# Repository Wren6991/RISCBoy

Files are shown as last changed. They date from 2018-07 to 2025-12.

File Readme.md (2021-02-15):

RISCBoy
=======

RISCBoy is an open-source portable games console, designed from scratch. This includes:

- A RISC-V compatible CPU
- A raster graphics pipeline and display controller
- Other chip infrastructure: busfabric, memory controllers, UART, GPIO etc.
- A PCB layout in KiCad

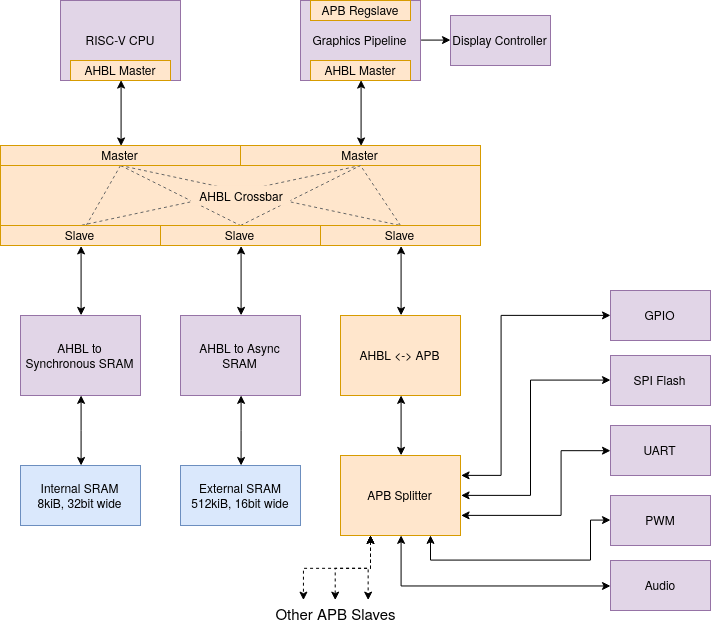
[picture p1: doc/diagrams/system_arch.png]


It is a Gameboy Advance from a parallel universe where RISC-V existed in 2001. A love letter to the handheld consoles from my childhood, and a 3AM drunk text to the technology that powered them.

The design is written in synthesisable Verilog 2005, and is intended to fit onto an iCE40-HX8k FPGA. This is a LUT4-based FPGA with 7680 logic elements, so fitting a 32 bit games console requires a crowbar and some vaseline, or perhaps just careful design. The HX8k was once the largest FPGA targeted by the open-source [Icestorm](http://www.clifford.at/icestorm/) FPGA toolchain, but that toolchain has since [moved on](https://github.com/SymbiFlow/prjtrellis) to [greater things](https://github.com/SymbiFlow/prjxray).

More detailed information can be found in the [documentation](doc/riscboy_doc.pdf).

The processor supports the RV32IMC instruction set, and passes the RISC-V compliance suite for these instructions, as well as the [riscv-formal](https://github.com/SymbioticEDA/riscv-formal) verification suite, and some of my own formal property checks for instruction frontend consistency and basic bus compliance. It also supports M-mode CSRs, exceptions, and a simple compliant extension for vectored external interrupts.

Cloning
-------

**This repository uses submodules for HDL as well as tests**

```bash
git clone --recursive https://github.com/Wren6991/RISCBoy.git riscboy
```

Alternatively

```bash
git clone https://github.com/Wren6991/RISCBoy.git riscboy
cd riscboy
git submodule update --init --recursive
```

Note a recursive submodule update is required to run the processor's standalone tests. This is not necessary for building RISCBoy gateware.

Building RV32IMC Toolchain
-------------------------

The RV32IMC toolchain is required for compilation of software-based tests. Follow the instructions on the [RISC-V GNU Toolchain GitHub](https://github.com/riscv/riscv-gnu-toolchain), except for the configure line:

```bash
# Prerequisites for Ubuntu 20.04
sudo apt install -y autoconf automake autotools-dev curl python3 libmpc-dev libmpfr-dev libgmp-dev gawk build-essential bison flex texinfo gperf libtool patchutils bc zlib1g-dev libexpat-dev
cd /tmp
git clone --recursive https://github.com/riscv/riscv-gnu-toolchain
cd riscv-gnu-toolchain
# The ./configure arguments are the most important difference
./configure --prefix=/opt/riscv --with-arch=rv32imc --with-abi=ilp32 --with-multilib-generator="rv32i-ilp32--;rv32ic-ilp32--;rv32im-ilp32--;rv32imc-ilp32--"
sudo mkdir /opt/riscv
sudo chown $(whoami) /opt/riscv
make -j $(nproc)
```

On smaller FPGAs, like the iCE40 UP5k, RISCBoy may be configured to use a smaller RV32I variant of the processor, rather than the higher-performance RV32IMC version. The compiler will support any of the ISA variants available on RISCBoy, but we must also instruct the toolchain build scripts to produce standard libraries for these variants, via the `--with-multilib` arguments. Running a RV32I executable linked against an RV32IMC standard library on an RV32I-only processor will ruin your day!

Simulation
----------

The simulation flow is driven by Xilinx ISIM 14.x; makefiles are found in the scripts/ folder. This has only been tested with the Linux version of ISIM.

You will also need to checkout the RISC-V compliance suite in order to run these tests (note the `-- test` is required to stop git from looking in the KiCad directories and complaining about the library structure there).

```
$ git submodule update --init --recursive
```

Once this is ready, you should be able to run the following:

```bash
. sourceme
cd test
./runtests
```

which will run all of the HDL-level tests. Software tests will require the RV32IC toolchain. You may need to adjust some of the paths in `sourceme` if ISIM is installed in a non-default location. To graphically debug a test, run its makefile directly:

```bash
cd system
make TEST=helloworld gui
```

PCB
---

The image shows the Rev A PCB. It is compatible with iTead's 4-layer 5x5 cm prototyping service, which currently costs $65 for 10 boards.

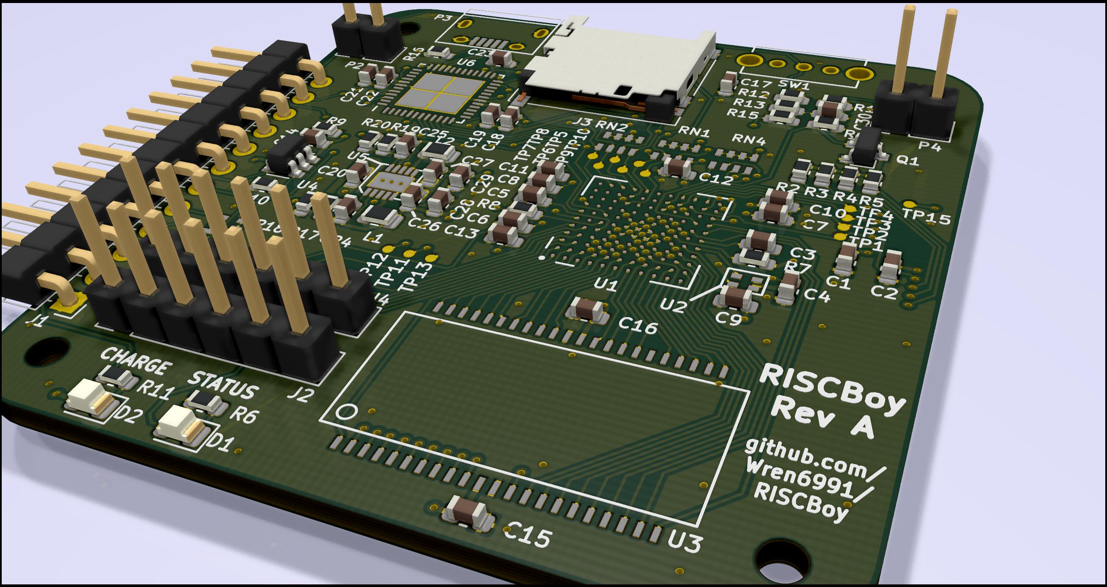
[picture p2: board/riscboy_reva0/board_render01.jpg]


The schematic can be viewed [here (pdf)](board/fpgaboy.pdf)

Rev B will look quite different; I am waiting for the gateware and bootloader to mature before proceeding. My current dev hardware looks a lot like my [Snowflake FPGA board](https://github.com/Wren6991/Snowflake-FPGA).

Synthesis
---------

FPGA synthesis for iCE40 uses an open-source toolchain. If you would like to build this project using the existing makefiles, you will first need to build the toolchain I used:

- [Yosys](https://github.com/yosyshq/yosys) for synthesis
- [nextpnr](https://github.com/YosysHQ/nextpnr) for place and route
- [Project Icestorm](http://www.clifford.at/icestorm/) for bitstream generation

Note that I have only built these on Linux. I've heard it is possible to build these on Windows, but haven't tried it. However, they can be built on a Raspberry Pi, which is neat.

Once the toolchain is in place, run

```bash
. sourceme
cd synth
make -f HX8k-EVN.mk bit
```

to generate an FPGA image suitable for Lattice HX8k evaluation board.

There is also highly experimental support (i.e. not my main dev platform) for ECP5, with board files for the Lattice LEF5UM5G-85F-EVN evaluation board:

```bash
make -f ECP5-EVN.mk BUILD=full bit
```

This build replaces the external, 512 kiB, 16 bit wide SRAM of RISCBoy development hardware with an internal, 256 kiB, 32 bit wide synchronous memory, which Trellis builds out of ECP5 sysmem blocks.

Directory Structure
-------------------

- `board`: KiCad files for main RISCBoy PCB and other small boards used during development
- `doc`: LaTeX source and diagrams for documentation, and the most recently built PDF
- `hdl`: The Verilog source for RISCBoy gateware.
	- `busfabric`: AHB-lite crossbar and APB peripheral fabric
	- `graphics`: Source for the pixel processing unit
	- `hazard5`: Source for the RISC-V processor. This is completely self-contained.
	- `mem`: Memory controllers, and inference/injection wrappers and models for the memories themselves
	- `peris`: Small peripherals such as UART, SPI, PWM
	- `riscboy_core`: Structural module to instantiate and connect the components that comprise RISCBoy
	- `riscboy_fpga`: Top-level wrappers for a few different FPGAs and boards: connect up IOs, provide clock and reset
- `reference`: a few PDFs for standards used in RISCBoy, e.g. the RISC-V instruction set
- `scripts`: Junk that I can't put anywhere else
- `software`: Loose collection of C files that are used for system-level tests. Not really a useful software tree yet.
- `synth`: Working directory for running whole-system synthesis. Top-level makefiles, pin constraint files.
- `test`: Regression tests. Some are Verilog testbenches, others are software testcases that run on simulations of the processor or the full system.

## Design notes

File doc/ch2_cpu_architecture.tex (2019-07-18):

\section{CPU Architecture}

Hazard5 is a 32-bit processor based on the RISC-V instruction set architecture. It accesses the system through a single AMBA 3 AHB-Lite master port. Those familiar with the textbook 5-stage RISC pipeline will find Hazard5 mostly straightforward, but hopefully will still find some interesting tricks. We will use the following symbols to refer to the 5 stages:

\begin{itemize}
\item {\tt F}: fetch
\item {\tt D}: decode
\item {\tt X}: execute
\item {\tt M}: memory access (load/store)
\item {\tt W}: register writeback, fetch address generation
\end{itemize}

Hazard5 supports the RV32IC instruction set, whose encoding is variable-width. The C extension typically reduces instruction bandwidth by \textasciitilde 25\%, which helps to maintain performance when sharing bus access between fetch and load/store.

Branches are speculated, but there is currently no dynamic branch predictor. Instead, we use the static prediction scheme described in the RV ISA manual (based on sign of branch offset).

\subsection{Frontend}
\label{section:frontend}

\begin{figure}[!htb]
\centering
\caption{Hazard5 processor frontend, block diagram}

\label{diagram:frontend}
\end{figure}

The frontend (figure \ref{diagram:frontend}) consists of stage {\tt F} and an additional stage which performs the AHB address phase, and can be considered part of {\tt W}. Its purpose is to feed {\tt D} with instructions, whilst meeting the following constraints:

\begin{itemize}
	\item No combinatorial path from AHB-Lite data phase to address phase (e.g. {\tt hready} $\to$ {\tt htrans})
	\item AHB-Lite compliant: no unaligned transfers, no deassertion or change of active requests
	\item Provide up to 32 bits of instruction data per clock in steady state, even if instructions are unaligned
	\item 0-cycle jump/flush to AHB address phase assertion (with minimal logic on this path)
	\item No performance penalty for unaligned jump to 16-bit instruction
	\item Attempt to maintain performance when competing with the load/store unit and AHB-Lite busmaster peers
\end{itemize}

The main source of complexity is that a RISC-V *C instruction stream is not naturally-aligned, i.e. instruction address modulo instruction size is not always zero. We spend gates here to optimise the common case of sequential execution, and to lessen the effects of fetch starvation due to load-store activity.

To meet these constraints, the frontend performs almost exclusively word accesses, which must be aligned. The only exception is a jump (or similar, e.g. mispredict recovery) to a non-word-aligned address. In this case, a halfword fetch from the target address is performed.

\subsubsection{Prefetch Queue}

The frontend queues up fresh instruction data which is waiting to be decoded. The pipelined nature of AHB-Lite means that the bus transfers run ahead of {\tt D} by at least two clocks, and the prefetch queue is able to buffer these in-flight transfers if {\tt D} stalls against a later pipe stage. The queue also decouples {\tt D}'s stall logic (which is a function of {\tt hready}) from the address phase request, and finally, the queue helps keep {\tt D} supplied with instructions while the busmaster is busy with load/stores from {\tt X}.

There are three parts to the queue:

\begin{itemize}
	\item A 32-bit FIFO. The depth is configurable, and can be as little as 1 word.
	\item A halfword buffer which may store the higher-addressed half of a recently-popped FIFO word
	\item The upper half of the current instruction register ({\tt CIR}), if the previous instruction was 16-bit
\end{itemize}

These three sources should service the majority of instruction fetches, and fresh bus data is written only to the FIFO. However, following jumps, flushes, or fetch starvation (either due to load/store activity or bus wait states), bus data can be forwarded directly to {\tt CIR}.

\subsubsection{Program Counter}

Hazard5 does {\it not} use the program counter ({\tt PC}) for code fetching, during sequential execution. {\tt PC} is used exclusively for the link value in {\tt JAL(R)}, mispredict recovery, and PC-relative addressing; it is physically located in {\tt D}.

The frontend fetches instruction data from consecutive word-aligned addresses, paced by backpressure from the instruction FIFO; {\tt PC} is not involved. However, as a special case, it {\it does} need the full jump target address (which becomes the new {\tt PC}), as unaligned jumps require special attention.

\subsubsection{Arbitration of Fetch and Load/Store}
\label{section:fetch_ls_arb}

The single AHB master port asserts transactions from two sources: the frontend, whose address phase is in {\tt W}, and the load/store unit, whose address phase is in {\tt X}. Frontend requests may be linear or non-linear (e.g jumps). The rules are:

\begin{enumerate}
	\item If a jump or mispredict recovery is asserted by {\tt M}, this wins.
	\begin{itemize}
		\item Any requests from earlier stages are logically later in program order.
		\item If {\tt M} wants to jump then these instructions are being executed in error, so should certainly not be permitted to access the bus.
	\end{itemize}
	\item Else if a load/store is asserted by {\tt X}, this wins.
	\begin{itemize}
		\item Stalling instruction fetch {\it may} be covered by the prefetch queue, in which case we've lost nothing
		\item Stalling a load/store will always increase execution time
		\item If instead {\tt X} stalled, and instruction fetch ran ahead, what would we do with the fetched instructions?
	\end{itemize}
	\item Otherwise, perform any other access requested by the frontend.
	\begin{itemize}
		\item Always Be Fetching
	\end{itemize}
\end{enumerate}

The fetch and load/store interfaces are well-decoupled; it would be simple to remove the arbiter and create a 2-master processor configuration. (TODO: add a wrapper that does this!)

\subsubsection{Jumps and Branches}

Due to the pipelined nature of AHB, we are unable to jump or to take branches in fewer than 2 cycles (without adding sophisticated prediction):

\begin{itemize}
\item Cycle 0: AHB data phase for fetch of jump/branch. Next instruction is in address phase concurrently.
\item Cycle 1: Jump/branch instruction is now available to {\tt D}
	\begin{itemize}
		\item (Quickly) use to control the new address phase
		\item The immediately following instruction is already in data phase
	\end{itemize}
\item Cycle 2: Data phase for jump target instruction
\item Cycle 3: Jump target is presented to {\tt D} and decoded.
\end{itemize}

We knew the jump target on cycle 1, but did not begin decoding the targeted instruction until cycle 3. We also made one wasted code fetch. This is suboptimal, but fetching the jump target {\it before} decoding the jump is tricky, and there are lower-hanging fruit in terms of performance per LUT.

Jumps physically occur in {\tt W}, directly in front of the fetch address generator. There are two reasons to jump:

\begin{itemize}
	\item Inspecting the {\tt CIR} in {\tt F/D} pipe register ({\tt JAL}, speculated taken branches)
	\item Inspecting {\tt X/M} pipe register ({\tt JALR}, branch mispredict recovery)
\end{itemize}

{\tt JALR} (indirect jump) is taken later because it uses the register file and the ALU to compute its target.

If both of these sources attempt to jump in the same cycle, {\tt X/M} takes priority, since it is executing an older instruction. In both cases, the part of the pipeline in the hazard shadow is invalidated; i.e., {\tt W} $\to$ {\tt F}, or {\tt W} $\to$ {\tt X}. Invalidation is performed by clobbering the pipeline control signals in such a way that these instructions will have no side effects.

The branch prediction scheme is static: take backward branches, and do not take forward branches. The cycle costs are as follows:

\begin{center}
\begin{tabular}{l c}
\hline
Jump Type & Cycles (Execution + Penalty) \\
\hline
Direct jump & 2 \\
Predicted, non-taken branch & 1 \\
Predicted, taken branch (same as jump) & 2 \\
Indirect jump & 4 \\
Branch mispredict & 4 \\
\hline
\end{tabular}
\end{center}

Upon jumping, we need some mechanism to invalidate parts of the pipeline: this is described in section \ref{section:stalling_flushing}.

\subsubsection{CIR Locking}

There is a landmine in the following tableau:

\begin{itemize}
	\item {\tt M} contains a load (in data phase), and the bus is stalled
	\item {\tt X} contains an instruction dependent on the load result; say an {\tt AND}
	\item {\tt D} contains a branch which is mispredicted taken
\end{itemize}

For example, say we are polling a status bit in an IO register, looping until some bit is high. The instruction in {\tt X} must stall for at least two cycles due to the bus stall and load-use hazard. Due to a frontend design constraint from \ref{section:frontend} -- "No combinatorial path from AHB-Lite data phase to address phase (e.g. {\tt hready} $\to$ {\tt htrans})" -- we must not use {\tt X}'s stall signal to gate the jump request, as this would create such a path. However, {\it not} gating the jump request is fatal, as new fetches will clobber {\tt CIR} before the branch instruction can proceed into {\tt X}, so the mispredict will never recover. {\tt JAL} has the same problem: it will jump, but not produce a link address.

Hazard5 resolves this with {\tt CIR} locking. {\tt D} signals to {\tt F} that {\tt CIR} and its validity count must not change on the next clock edge, and uses this same signal to inhibit repeated assertion of its own jump request. In the fetch path, this is achieved by steering the controls on the existing shift/overlay logic in the frontend, and requires no additional muxing.

Whilst the {\tt CIR} is locked, the frontend is still free to act on the jump request, and fetch ahead along the new code path (more useful for {\tt JAL}); this data is buffered in the FIFO. Once the roadblock ahead of {\tt D} clears, the branch instruction proceeds down the pipeline, and the lock is released simultaneously.

Note also that a bus stall does not cause the frontend to block jump requests, as this too would create a combinatorial path, since requests are forwarded straight to the bus (due to another constraint from \ref{section:frontend}). The frontend's response to bus stall on jump request is simply to not increment the target before storing to {\tt FC}, so that the target address continues to be asserted on subsequent cycles. Registered feedback blocks {\it subsequent} jump requests until the first request completes its address phase.

\subsubsection{Instruction Barrier (FENCE.I)}

If the program stores to instruction addresses about to be executed from, which potentially exist in the prefetch queue, a stale instruction will be executed. {\tt FENCE.I} cannot be decoded as a nop, and requires special handling.

Hazard5 decodes {\tt FENCE.I} as "jump to {\tt PC} + 4". The jump invalidates the prefetch queue, and the following instruction will be re-fetched from memory.

Timing analysis shows that calculating a jump target, between {\tt CIR} and the address bus, is generally on the critical path. To avoid more logic on this path, {\tt FENCE.I} is instead implemented by spoofing a branch-taken mispredict, which has the same effect. This adds two cycles to the execution time, but performance of this instruction is decidedly noncritical.

\subsection{Backend}

The backend is the hardware which manipulates the processor's architectural state according to the stream of instruction data from the frontend. Architectural state refers to the state you will read about in the ISA manual, and includes the register file and program counter; the backend also contains some non-architectural state, e.g. holding intermediate results in between pipeline stages.

The backend consists of stages {\tt D}, {\tt X}, {\tt M}. Its overall structure is depicted by figure \ref{diagram:cpu_backend}. This is a pretty large figure -- too large to print really -- so you can view it separately at \url{https://github.com/Wren6991/RISCBoy/raw/master/doc/diagrams/cpu_backend.pdf}

\newpage

\begin{center}
	\begin{sideways}
		\begin{minipage}{\textheight}
			
			\captionof{figure}{Hazard5 processor backend, block diagram}
			\label{diagram:cpu_backend}
		\end{minipage}
	\end{sideways}
\end{center}

\newpage

\subsubsection{Operand Bypass}

Hazard5 possesses an operand bypass (forwarding) network. Register writes must always be visible to later instructions, even before an earlier instruction reaches register writeback. One solution is to detect that one instruction depends on the result of an earlier instruction (a read-after-write, or RAW hazard) and stall the later instruction until the earlier one completes. This is safe, but incurs a hefty performance penalty; a more elegant solution is to pluck the result of the earlier instruction straight from the pipeline, before it finishes executing (but after the result is valid!).

Locations of bypasses are shown in figure \ref{diagram:cpu_backend}. The following bypasses are available:

\begin{itemize}
	\item {\tt X/M} $\to$ {\tt X}
	\item {\tt M/W} $\to$ {\tt X}
	\item {\tt M/W} $\to$ {\tt M}
	\item {\tt W/X} $\to$ {\tt X}
\end{itemize}

The last is in lieu of a write-to-read bypass in the register file; some tools (not Yosys!) struggle with inferring memories from transparent memory models, so it's better to be explicit.

To control the bypassing, some of the register specifiers from {\tt CIR} are passed down the pipeline alongside the data. {\tt rs1, rs2, rd} (operand sources and destination) are passed down as far as {\tt X}. {\tt rs2, rd} make it to {\tt M}, and only {\tt rd} makes it to {\tt W}.

The upshot is:

\begin{itemize}
	\item Back-to-back ALU operations execute at 1 CPI
	\item Loads insert 1 stall cycle if immediately required by the ALU. 1 CPI otherwise.
	\item Stores execute at 1 CPI (bus stall notwithstanding)
	\item In a load + store pair, the load takes only one cycle, since the {\tt M} stage has self-forwarding
\end{itemize}

Various interesting strategies can alleviate load-use penalty in in-order pipelines, such as adding a second, "late" ALU in the {\tt M} stage. In our case we judge this to not be worth the LUTs.

Another interesting strategy is to add muxing at the register file write port, to select which stage to retire from. This has the dual benefit of firstly simplifying the operand bypass, and secondly reducing dynamic power, since there is no need to pass data through unused stages (and they can be clock gated). Hazard5 does not use this strategy either -- maybe the next project.

\subsubsection{Pipeline Stalling and Flushing}
\label{section:stalling_flushing}

Our terminology: stalling means a pipeline stage does not advance its state until some blocking condition has cleared. The instruction residing in this stage will not progress to the next stage, and the previous stage will not write {\it its} instruction into this stage. Flushing is when in-flight instructions in some stages are replaced with NOPs, and their results are discarded.

The frontend is decoupled from other stages' stall logic via the prefetch queue. This is important: {\tt hready} is an input to that stall logic, and the the frontend's address-phase request must not be a function of {\tt hready}.

The frontend may not be able to immediately accept a jump request, which may cause other pipe stages to stall if it is low. One cause is the frontend holding an existing address-phase request stable until the cycle {\it after} {\tt hready}, which is required for AHB-Lite compliance.

For the backend, the stall logic is more intricate, as signals such as {\tt hready} are used in-cycle to determine whether an instruction progresses to the next pipeline stage:

\begin{itemize}
	\item {\tt D}:
	\begin{itemize}
		\item {\tt CIR} does not contain a valid instruction (either no data, or half of a 32-bit instruction)
		\item {\tt D} asserts jump, but frontend rejects the jump request
		\item {\tt X} is stalled
	\end{itemize}
	\item {\tt X}:
	\begin{itemize}
		\item {\tt hready} low and {\tt X} address-phase request asserted
		\item RAW hazard on {\tt M} (load-use)
		\item {\tt M} is stalled
	\end{itemize}
	\item {\tt M}:
	\begin{itemize}
		\item {\tt hready} low and data-phase active
		\item {\tt M} asserts jump, but frontend rejects the jump request
	\end{itemize}
	\item {\tt W}: does not stall
\end{itemize}

If a given stage is stalled, but the following stage is not, it must insert a bubble. Bubbles are created by zeroing out control fields, such as {\tt rd}, so that the instruction cannot affect system or processor state.

There are two cases where we must flush:

\begin{itemize}
	\item Branch/jump taken from {\tt D}; frontend invalidates prefetched data
	\item Jump/mispredict taken from {\tt M}; must flush frontend, {\tt D}, {\tt X}
\end{itemize}

And the flushing mechanisms for each stage are as follows:
\begin{itemize}
	\item {\tt D}: destination register {\tt rd} cleared, which makes result invisible to register file and operand bypass. {\tt memop}, {\tt branchcond} pipe flags are cleared.
	\item {\tt X}: same as {\tt D} (except for {\tt branchcond}, which does not pass on to {\tt M} anyway.
\end{itemize}

Flushing and bubble insertion are very similar in mechanism.

\subsection{Unaligned Memory Accesses}

Alignment is the constraint that the address of a memory access be equal to zero, modulo some size. Where no size is specified, we refer to {\it natural} alignment, i.e. modulo the size of this particular memory operation. RISC-V requires that memory is byte-addressable.

The frontend goes to some length (section \ref{section:frontend}) to maintain high throughput. RV-C instruction streams are {\it always} unaligned, and {\it every} instruction must be fetched before it is executed, so Amdahl says it's worth it. On the other hand load/stores are less than 100\% of all instructions, and the vast majority are unaligned; consequently, Hazard5 does not have hardware support for unaligned load/stores. These are trapped (TODO) and handled in software if and when they occur.

\subsection{Control and Status Registers (CSRs)}

Hazard5 possesses the standard {\tt Zicsr} extension, which provides atomic access to the CSRs. Only M-mode CSRs are implemented. Access to an unimplemented CSR (e.g. a U-mode or S-mode CSR) causes an illegal instruction exception. The implementation is minimally legal: WARL fields are widely exploited, to reduce logic and state overhead. Module parameters can reduce CSR support, or remove it entirely, as per relative importance of compliance versus area in your application. Note that some features, such as interrupts and exceptions, require CSR support.

When the counter CSRs are present, {\tt mtime} and {\tt mcycle} are aliased to the same counter. 64-bit counters are prohibitively large in a compact 32-bit processor. The {\tt mcountinhibit} (WARL) register is tied to zero: {\tt mtime} must run freely, hence the {\tt mcycle} alias of this counter cannot be halted either. {\tt minstret} is fully implemented, but its {\tt mcountinhibit} bit is also tied low. The width of the counters can be reduced from 64 bits to save logic ({\it noncompliant}), although the full 64 CSR bits remain writeable, which leaves some opportunity for software emulation.

TODO: full table of CSRs we implement, and to what extent they are implemented/WARL'd

\subsection{Interrupts and Exceptions}

\begin{figure}[!htb]
\centering
\caption{Hazard5 trap vector table layout}
\label{table:traps}
\begin{tabular}{l l l}
\hline
Trap Table Offset & {\tt mcause} & Trap Description \\
\hline
0x00 & 0x00000000 & Misaligned instruction access \\
0x04 & 0x00000001 & Instruction access fault \\
0x08 & 0x00000002 & Illegal instruction \\
0x0c & 0x00000003 & Breakpoint \\
0x10 & 0x00000004 & Misaligned load address \\
0x14 & 0x00000005 & Load access fault \\
0x18 & 0x00000006 & Misaligned store address \\
0x1c & 0x00000007 & Store access fault \\
0x20 & 0x00000008 & {\it Reserved} \\
0x24 & 0x00000009 & {\it Reserved} \\
0x28 & 0x0000000a & {\it Reserved} \\
0x2c & 0x0000000b & M-mode ECALL \\
0x30 & 0x0000000c & {\it Reserved} \\
... & ... & ... \\
0x3c & 0x0000000f & {\it Reserved} \\
\hline
0x40 & 0x80000000 & {\it Reserved} \\
0x44 & 0x80000001 & {\it Reserved} \\
0x48 & 0x80000002 & {\it Reserved} \\
0x4c & 0x80000003 & Machine software interrupt \\
0x50 & 0x80000004 & {\it Reserved} \\
0x54 & 0x80000005 & {\it Reserved} \\
0x58 & 0x80000006 & {\it Reserved} \\
0x5c & 0x80000007 & Machine timer interrupt \\
0x60 & 0x80000008 & {\it Reserved} \\
... & ... & ... \\
0x7c & 0x8000000f & {\it Reserved} \\
\hline
0x80 & 0x80000010 & External IRQ 0 \\
... & ... & ... \\
0xbc & 0x8000001f & External IRQ 15 \\
\hline
\end{tabular}
\end{figure}

Hazard5 has simple exception and interrupt support, compliant with the RISC-V privileged ISA spec (M-mode only). Here we follow the terminology set out in the RISC-V user-level spec: an {\it exception} is an anomalous condition caused by executing an instruction, which requires control transfer; an {\it interrupt} request is some external, asynchronous event, which requires control transfer; a {\it trap} is the transfer of control to a handler, used to service either an interrupt or an exception. Hazard5 implements interrupts and exceptions as follows:

\begin{itemize}
	\item Trap entry causes a jump to a location in the trap vector table (addressed by {\tt mtvec}), simultaneously stashing the PC in {\tt mepc}
	\begin{itemize}
		\item Other CSR state is also modified, e.g. {\tt mcause}, {\tt mstatus}
		\item The physical mechanism for this jump is the same as a branch mispredict
	\end{itemize}
	\item Trap exit, via the {\tt mret} instruction, causes a jump to {\tt mepc}
	\begin{itemize}
		\item {\tt mret} also modifies some diagnostic CSR state, e.g. {\tt mstatus}, as per the privileged ISA specification
	\end{itemize}
	\item Only vectored mode is available. I.e., the LSBs of {\tt mtvec} are tied to 0x1.
	\item When written, {\tt mtvec} is rounded down to a 4kB boundary. This saves an adder when generating the trap vector address.
	\item Besides PC, the hardware saves/restores no architectural state on entry/exit. Software is responsible for stacking/unstacking the GPRs.
\end{itemize}

External IRQs can be observed and masked in bits 31:16 of {\tt mip} and {\tt mie}. This limits the number of IRQs to 16, but this limit could be increased by additional nonstandard CSRs to observe and mask more external interrupts.

The layout of the trap table is in figure \ref{table:traps}. Where a standard exception or interrupt is unimplemented (S/U mode) or irrelevant (page faults), it is marked as {\it reserved}. In particular, the standard machine external interrupt vector ({\tt mcause} = 0x8000000b) is not used, and external interrupts are instead separately routed to {\tt mcause} = 0x80000010 and above. This layout has been arranged to produce an obvious mapping between {\tt mcause} and trap vector address, which unfortunately bloats the table with reserved vectors.

To save space, it is reasonable for initial bootcode to include only the first 12 entries in the table (the exceptions), and run with interrupts disabled until it has populated a more complete table elsewhere in memory, which it can then point to by modifying {\tt mtvec}.

Trap handlers do not preempt one another. After a trap returns, the highest-priority active trap request is selected, and its handler entered. Normal execution continues while there are no active trap requests. Exceptions take priority over IRQs, and lower-numbered IRQs are higher priority. An illegal instruction exception encountered while handling an exception causes a lockup of the core (details TBD). TODO: table of the exception/interrupt space

IRQ inputs are level-sensitive. It is recommended to clear an interrupt at its source upon entering its handler. If the interrupt reasserts before the handler {\tt mret}s, the handler still returns, and the interrupt competes with other trap requests for reentry. Note that, if many register stages are present on the IRQ signal, there is a potential race between clearing the IRQ and executing the {\tt mret}, causing spurious reentry; in practice, restoration of caller-saves should provide ample time for IRQ deassertion to be observed, before the {\tt mret} is reached.

\subsection{Plugin Interface}

Plugins are pieces of hardware attached to the Hazard5 pipeline to extend its functionality, and instruction set. For example, the M extension (multiply and divide) is implemented using a plugin.

Plugins interact with three pipe stages:

\begin{itemize}
	\item {\tt D}
	\begin{itemize}
		\item Plugins see the current instruction, so that they can decode it
		\item Plugins notify {\tt D} that an instruction it does not recognise is, in fact, valid
	\end{itemize}
	\item {\tt X}
	\begin{itemize}
		\item Plugins can see the {\tt rs1} and {\tt rs2} operand bypasses
		\item Additional control signals provide functionality such as killing an in-progress operation so that e.g. an interrupt can run
	\end{itemize}
	\item {\tt M}
	\begin{itemize}
		\item All plugins retire their results into {\tt M}.
		\item This adds a 1-cycle RAW stall if the immediately-following instruction is dependent, but on current iCE40 implementations, {\tt X} is already near-critical-path and very mux heavy.
		\item Plugins can stall {\tt M} if they need more cycles to produce a result.
	\end{itemize}
\end{itemize}

There is no hard limit to the number of plugins that can be added, but the additional muxing and fanout is not free, which constrains practical implementations.

\subsubsection{M-small Plugin}

The M-small plugin implements the RISC-V M standard extension (multiply, divide and modulo). To save area, the plugin employs a combined multiply/divide unit which performs all required calculations, at 1 bit per clock. If timing permits, the datapath can be unrolled to perform multiple iterations per clock. e.g. radix-4 divide/multiply.

\subsubsection{M-fast Plugin}

The Mfast plugin also implements the M extension, but uses a fast Wallace tree to perform multiplication, allowing a throughput of 1 32-bit multiply per clock.

Other details TBD

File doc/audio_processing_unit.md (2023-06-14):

# RISCBoy Audio Processing Unit (APU)

Goals:

- Resource budget: 100 LUTs (excluding system interface and digital DACs), two BRAMs
- 48 kHz 8 bit stereo output when running at 36 MHz
- Provide similar capability to an original Gameboy with default microcode
- Be rather more capable with user-supplied microcode
- Easy to use as a dumb wave-out ring buffer interface
- Fun to program

Design is still at the handwaving stage, I might have to adjust features downward or budget upward.

## Memory Architecture

Two 256x16 block RAMs, each with one write port and one read port. This assumes iCE40, but other FPGA block RAMs can support similar partitioning with some waste.

One memory (IRAM) contains the audio generation code. The registers (e.g. 8x16b) are stored at the top of this memory. The other memory (WRAM) contains wave sample tables, user configuration variables which can be used as software-defined control registers, and the core registers are *also* stored at the top of this memory. There is no memory for buffering of audio samples between the APU and the audio DACs: the APU runs in hard real time, with a fixed cycle budget for each audio sample.

Having the registers mirrored to both memories allows two source registers to be fetched in one cycle. The separate read and write port on IRAM allow the next instruction to be fetched on the same cycle that the current instruction's result is written back. So a typical register-to-register instruction will take two cycles:

1. Read both source registers
2. Write back result register, and fetch next instruction

At an ISA level, IRAM is read-only, and WRAM is read-write (using conventional load/store instructions). The system has write-only access to IRAM when the APU is halted, and no access when it is running. The system has read-write access to WRAM at all times, but has lower access priority than the APU, so may stall.

The APU has minimal linked-load store-conditional support on WRAM accesses: if the APU performs a linked load to some address, followed by a conditional store, and the system has written to that address in the intervening cycles, the store is suppressed (NOP'd). The APU is not able to detect that this has happened, and the system has no corresponding mechanism of its own. The use case is for the APU to perform read-modify-writes of some control variable (e.g. decrementing a volume) whilst the system concurrently performs *writes only* on that variable, in which case this ll-sc mechanism resolves the race between the write and the read-modify-write.

## Arithmetic

The APU uses two data types, each stored in a single register:

- 16-bit integers
- Pairs of 8-bit integers (SIMD)

The `88` format is for SIMD processing of stereo audio, and most arithmetic instructions use this format. The `16` format is used where higher precision or larger count is required, e.g. for phase accumulation.

All `88` arithmetic is signed-saturating. 16-bit arithmetic may be signed-saturating, or regular modular arithmetic.

Operations wishlist for 8+8:

- Saturating add (e.g. channel blending)
- 8x0.4 multiply (volume envelope; multiply 8-bit integer by 4-bit fractional in range 0..15/16)
- Some kind of swizzling move

Operations wishlist for 16:

- Signed-saturating add and subtract
- Modular add and subtract
- LFSR (polynomial in second source register; right-shift by 1, XOR masked by shifted-out LSB)

## Control Flow

There are two branch flags:
 - ZH (upper half of result was 0)
 - ZL (lower half of result was 0)

Branches test both flags against "true" or "don't care". So:

- `bxx` always branch
- `bxz` branch if lower half zero
- `bzx` branch if upper half zero
- `bzz` branch if all zeroes

Greater/less-than comparisons are performed with the help of saturating arithmetic.

TBD whether branches will be relative or absolute, but probably no indirect branches (so no procedure calls). We have more instruction slots than we have cycles per sample, so microcode is probably going to be fully unrolled rather than using loops and procedure calls.

## Load/Store Instructions

Only halfword load/stores are supported. Note that WRAM is always halfword-addressed, i.e. if two halfwords are consecutive in memory, the difference between their addresses is 1. The load/store data may represent a single 16-bit value or a pair of 8-bit values.

There are two addressing modes:

- Absolute immediate (loads or stores)
- Immediate with register ring (loads only)

The first is the most common. The entire address is supplied directly by the instruction word. Because we have more instruction slots available than cycles per sample, programs will generally be completely unrolled, so there is little purpose in being able to immediately index a data structure at offsets from a register-resident pointer.

Mnemonics are `ld` and `st`. Additionally there is a linked load, `ldl`, and conditional store, `stc`. `ldl` executes as a normal load, and additionally sets a hidden flag -- the *exclusive* flag -- that is cleared if the system writes to the address that the `ldl` loaded from, or any `stc` is executed. `stc` executes as a normal `st` when the exclusive flag is set (and additionally clears the flag), but executes as a NOP when the flag is clear.

Ok it's time to talk about the other addressing mode. The lower 5 address bits come from the upper 5 bits of a register, and the upper address bits come from an instruction immediate. This is used to index a 32-sample wave table stored in WRAM. The *upper* 5 bits of the register are used, so that the full 16 bits of that register can be used for fractional phase accumulation. Effectively the register is treated as a 5.11 fixed point number. Only a load is provided, and the mnemonic is `ldw`, where the w stands for "WTF".

Probably also some kind of immediate load (`ldi`). 8 bit immediate, same as address size. Ideally, can go to upper, lower or both halves of the destination register.

## Output

An `out` instruction outputs one `88` sample pair to the DACs.

Generally the APU will have finished calculating a sample slightly before the allotted time elapses. When this happens, the APU is stalled until the next audio sample period begins.

The APU runs in hard real time. There is (probably) no buffering of samples in between the APU and the DACs. It might be desirable to add a 1-deep sample buffer externally, for the case where the occasional sample has a longer runtime, e.g. some control update that happens once per 1024 samples, but the APU is designed to not need this in general.

## Interrupts

An `irq` instruction sets the interrupt flag. The system clears the flag to acknowledge the interrupt. Yup that's it.

Main use case is for dumb audio ring buffers with half-empty or quarter-empty interrupts. The audio ring buffer is constructed from multiple stacked 32-sample ring tables, which are addressed in a strictly incrementing fashion.

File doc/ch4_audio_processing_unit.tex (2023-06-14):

\section{Audio Processing Unit (APU)}

{\it Note: this section is even less complete than the others}

The APU is a lightweight processing core, designed to synthesise polyphonic audio, stream PCM or ADPCM audio from the system, or a mixture of the two, whilst blending/panning the audio channels. It runs in hard real time: each audio sample is calculated in one sample period, so no data buffering is required between APU and DACs. The design goals are:

\begin{enumerate}
	\item Low resource utilisation ($~100$ LUTs for the processing core)
	\item Output 48 kSa/s 8-bit stereo audio with a 12 MHz clock
	\item Provide similar interface to an 8-bit era games console with default APU code, so no programming required
	\item Streaming PCM audio from the system should be trivial (ring buffer + IRQ)
	\item Be fun to program: very focused on a single task, so quirky but easy to learn
\end{enumerate}

\subsection*{Architectural Overview}

\subsubsection*{Memory Architecture}

The APU is designed around a pair of iCE40 block RAMs: each is 16 bits wide by 256 entries deep, and has an independent read port and write port. The architecture and microarchitecture are designed around these parameters, for efficient use of the memory, and in particular for high utilisation of the memory ports. Figure \ref{diagram:apu_mem_arch} shows this in overview.

\begin{figure}[H]
\centering
\caption{Audio processing unit memory architecture}
\label{diagram:ppu_arch}

\end{figure}

\begin{itemize}
	\item IMEM:
	\begin{itemize}
		\item Contains the APU program instructions. Each instruction is 16 bits in size.
		\item Upper 8 slots contain a copy of the APU's general purpose registers
		\item The system has write-only access when the APU is halted, and no access when the APU is running
	\end{itemize}
	\item DMEM:
	\begin{itemize}
		\item Contains sample ring buffers used for wave tables or for buffering PCM data from the system
		\item Contains program temporary variables that don't fit into registers or need to be indexed
		\item Upper 8 slots contain a copy of the APU's general purpose registers
		\item The system has read-write access at all times, at a lower priority than the APU (system access stalls when the APU is accessing DMEM)
	\end{itemize}
\end{itemize}

8 general-purpose registers are available to APU programs. The register contents are mirrored across IMEM and DMEM, so that two independent register reads can take place simultaneously. Register writeback of one instruction is overlapped with instruction fetch of the next instruction. A typical register-to-register instruction (e.g. an add) executes in two cycles, performs 3 memory reads and 2 memory writes.

\subsubsection*{Arithmetic}

There are two data types used by APU instructions:

\begin{itemize}
	\item 16-bit integers
	\item Packed pairs of 8-bit integers (SIMD)
\end{itemize}

The former is useful for control variables and for phase accumulation of digital oscillators. The latter is used for SIMD processing of stereo sampling pairs. All 8-bit arithmetic is signed-saturating. 16-bit arithmetic can generally be either signed-saturating or normal modular arithmetic.

\subsubsection*{Input/Output}

The APU performs all calculations necessary to produce a 2$\times$8-bit stereo sample pair, then outputs this to the external DACs (probably some kind of sigma delta thing) with an {\tt out} instruction. The APU then stalls until the end of the audio sample period, whereupon it begins calculating the next samples.

For PCM sample streaming, the APU accesses ring buffers in DMEM, in the same way that it access DMEM wavetables for local synthesis. The system tops up the ring buffers by writing to DMEM, triggered by APU interrupts.

The {\tt irq} instruction can generate a system interrupt, which is mainly useful for half-empty or quarter-empty interrupts for PCM ring buffers.

\subsection{Instruction Set}

The two main instruction formats are:

{\bf R format}

\begin{bytefield}[endianness=big]{16}
\bitheader{0,4,5,7,8,10,11,15} \\
\bitbox{5}{{\tt opcode}} \bitbox{3}{{\tt rd}} \bitbox{3}{{\tt rs}} \bitbox{5}{\reservedfield}
\end{bytefield}

{\bf I format}

\begin{bytefield}[endianness=big]{16}
\bitheader{0,7,8,10,11,15} \\
\bitbox{5}{{\tt opcode}} \bitbox{3}{{\tt rd}} \bitbox{8}{{\tt imm}}
\end{bytefield}

\subsection*{Example Programs}

\subsubsection*{Wave channel}

\begin{lstlisting}
.imem                     ; List instruction memory contents
	ld r1, [#freq]        ; Initialise frequency from data memory
	li r0, #0             ; Initialise phase to 0
loop:
	addm16 r0, r1         ; Modular 16-bit addition to advance phase
	ldw r2, [r0, #sine]   ; Look up 2x8-bit samples in sine wave table
	out r2                ; Output samples to DAC, stall until next sample
	b loop                ; Repeat forever

.dmem                     ; List data memory contents
sine:
	...
freq:
	.hword 0x1234
\end{lstlisting}

\subsubsection{Wave channel, controllable frequency}

\begin{lstlisting}
.imem
loop:
	ld r1, [#freq]        ; Fetch frequency stored in memory
	ll r0, [#phase]       ; Fetch phase stored in memory, and set exclusive flag
	addm16 r0, r1         ; Increment phase by frequency
	sc r0, [#phase]       ; Store phase back into memory if still exclusive
	ldw r0, [r0, #sine]   ; Load wave sample from sine table
	out r0                ; Output 2x8-bit samples from r0
	b loop                ; Always jump to loop

.dmem
sine:
	...
freq:
	.hword 0x1234
phase:
	.hword 0
\end{lstlisting} 

\subsubsection{Wave channel, controllable volume with decay}

\begin{lstlisting}
.imem
loop:
	ld r1, [#freq]       ; Atomic update phase based on frequency
	ll r0, [#phase]
	addm16 r0, r1
	sc r0, [#phase]
	ld r2, [#decay]      ; Atomic update volume based on linear decay
	ll r1, [#volume]
	sub16 r1, r2
	sc r1, [#volume]
	ldw r0, [r0, #sine]  ; Look up wave table based on phase
	movhl r1, r1         ; Duplicate upper byte of volume
	mul48 r0, r1         ; Multiply each sample by 4 volume MSBs
	out
	b loop

.dmem
sine:
	...
freq:
	.hword 0x1234
phase:
	.hword 0
decay:
	.hword 0xabcd
volume:
	.hword 0
\end{lstlisting}

\subsubsection{Multiple wave channels}

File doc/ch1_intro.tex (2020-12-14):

\section{Introduction}

RISCBoy is an open source portable games console, designed from scratch:

\begin{itemize}
\item An open source CPU, graphics and bus architecture
\item Based on the RISC-V open source instruction set
\item FPGA synthesis, place and route with icestorm open source FPGA toolchain
\item An open source PCB layout
\item PCB designed with KiCAD open source PCB software
\item It's open source
\end{itemize}

\begin{displayquote}
{\it If you say open source one more time I'm gonna nut instantly} - Oscar Wilde
\end{displayquote}

\subsection{Digital Design}

\begin{figure}[!htb]
\caption{System-level block diagram}
\label{diagram:system_arch}
\centering

\end{figure}

The heart of the design is a Lattice iCE40-HX8k FPGA, containing 7680 LUT4s and flipflops. The logic was designed in synthesisable Verilog, with no dependencies on FPGA vendor IP; the contents of this GitHub repository could be taped out onto a chip. This includes:

\begin{itemize}
\item RV32IC-compatible 32-bit CPU design
	\begin{itemize}
	\item RISC-V instruction set
	\item 32I: base integer ISA profile
	\item M: hardware multiply/divide extension
	\item C: compressed instruction extension, for higher code density
	\item Vectored interrupts (save/restore of PC, RA only)
	\item 5-stage pipeline, similar to textbook RISC
	\item Single AHB-Lite master port
	\end{itemize}
\item Graphics pipeline
	\begin{itemize}
	\item Don't expect much, it's about as powerful as a Gameboy Advance
	\item Includes some MODE7-like functionality which allows drawing perspective-mapped textured planes, by providing per-scanline affine texture transformation. Think MarioKart
	\end{itemize}
\item AMBA 3 AHB-Lite compatible multi-master busfabric
\item Peripherals:
	\begin{itemize}
	\item DMA master
	\item External asynchronous SRAM controller (GS74116 or similar)
	\item Display controller (ILI9341)
	\item GPIO (bitbanging, peripheral muxing)
	\item SD card controller
	\item UART
	\item PWM
	\item Basic audio: voices + samples, noise-shaped PWM output
	\end{itemize}
\end{itemize}

This document attempts to describe some of these, but if you need nitty-gritty detail, the best documentation is the files ending with {\tt .v}.

That a free synthesis tool can cram this into one of the cheapest FPGAs on the market is tremendous. I hope for a situation like software compilers, where free tools such as GCC and LLVM are industry standards.

\subsection{Licensing}

The Verilog source to this project has no dependencies, and is distributed under the DWTFPL version 3. This is a {\it very} permissive open-source licence, and its text is included in full at the top of the source files. This license is very similar to the original DWTFPL, which more readers may be familiar with, but has an added indemnification clause.

This license is also known by its more formal name, as the "Do What The Fuck You Want To And Don't Blame Us Public License".

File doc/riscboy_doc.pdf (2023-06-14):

# RISCBoy Documentation

Luke Wren

1 Introduction | 1
2 CPU Architecture | 3
3 Pixel Processing Unit (PPU) | 13
4 Audio Processing Unit (APU) | 26
5 Bus Fabric and Memory Subsystem | 30

5.2.1 | Multiple Masters, One Slave | 32
5.2.2 | Full Crossbar | 34
5.3 Memories | 35
5.3.1 | Internal RAM | 35
5.3.2 | Main Memory | 37

## List of Figures

1 | System-level block diagram | | 1
2 | Hazard5 processor frontend, block diagram | | 3
3 | Hazard5 processor backend, block diagram | | 7
4 | Hazard5 trap vector table layout | 10
5 | Pixel processing unit, block-level diagram | 13
6 | PPU pixel formats | 14
7 | PPU scanline buffer states | 15
8 | PPU screen coordinate system | 19
9 | PPU texture coordinate system | 19
10 | PPU texture example | 20
11 | PPU affine blit with identity mapping | 21
12 | PPU affine blit with reflection in u=v | 21
13 | PPU affine blit with uniform scale | 22
14 | PPU affine blit with uniform scale and translation | 22
15 | PPU affine blit with rotation | 23
16 | PPU background coordinate system | 24
17 | Example PPU tileset | 24
18 | Example PPU tilemap | 25
19 | Audio processing unit memory architecture | 26
20 | AHB-Lite crossbar, module-level block diagram | 30
21 | AHB-Lite transfers, a simple example | 31
22 | AHB-Lite transfers, simple example with stalling | 32
23 | AHB-Lite transfers, two masters access one slave | 33
24 | AHB-Lite transfers, two masters access one slave, with low-priority back-to-back | 33
25 | AHB-Lite arbiter: simultaneous request buffer writes | 34
26 | AHB-Lite arbiter: late arrival of high priority request | 34
27 | Timing of synchronous SRAM interface | 36
28 | Timing of AHB-lite SRAM accesses, showing write data misalignment | 36
29 | AHB-lite SRAM access: resolving address collision with wait states | 36
30 | AHB-lite SRAM access: resolving address collision with a write buffer | 37

## 1 Introduction

RISCBoy is an open source portable games console, designed from scratch:

| An open source CPU, graphics and bus architecture
| Based on the RISC-V open source instruction set
| FPGA synthesis, place and route with icestorm open source FPGA toolchain
| An open source PCB layout
| PCB designed with KiCAD open source PCB software
| It’s open source
| If you say open source one more time I’m gonna nut instantly - Oscar Wilde

### 1.1 Digital Design

Figure 1: System-level block diagram

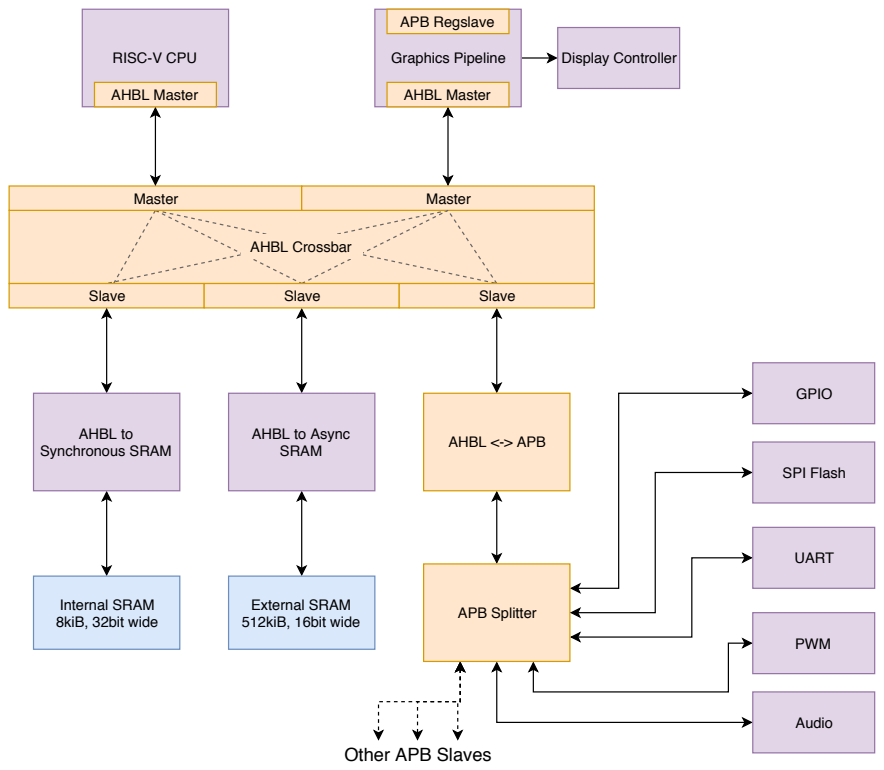
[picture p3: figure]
Master; Slave; RISC-V CPU; AHBL Master; Graphics Pipeline; APB Regslave; Display Controller; AHBL to Synchronous SRAM; Internal SRAM 8kiB, 32bit wide; AHBL to Async SRAM; External SRAM 512kiB, 16bit wide; AHBL <-> APB; APB Splitter; UART; PWM; Audio; GPIO; AHBL Crossbar; SPI Flash; Other APB Slaves

The heart of the design is a Lattice iCE40-HX8k FPGA, containing 7680 LUT4s and flipflops. The logic was designed in synthesisable Verilog, with no dependencies on FPGA vendor IP; the contents of this GitHub repository could be taped out onto a chip. This includes:

| RV32IC-compatible 32-bit CPU design
| – RISC-V instruction set
| – 32I: base integer ISA profile
| – M: hardware multiply/divide extension

– C: compressed instruction extension, for higher code density – Vectored interrupts (save/restore of PC, RA only)

– 5-stage pipeline, similar to textbook RISC

– Single AHB-Lite master port

| Graphics pipeline
| – Don’t expect much, it’s about as powerful as a Gameboy Advance – Includes some MODE7-like functionality which allows drawing perspective-mapped textured planes, by providing per-scanline affine texture transformation. Think MarioKart
| AMBA 3 AHB-Lite compatible multi-master busfabric
| Peripherals:
| – DMA master – External asynchronous SRAM controller (GS74116 or similar) – Display controller (ILI9341) – GPIO (bitbanging, peripheral muxing) – SD card controller – UART – PWM – Basic audio: voices + samples, noise-shaped PWM output

This document attempts to describe some of these, but if you need nitty-gritty detail, the best documentation is the files ending with .v.
That a free synthesis tool can cram this into one of the cheapest FPGAs on the market is tremendous. I hope for a situation like software compilers, where free tools such as GCC and LLVM are industry standards.

### 1.2 Licensing

The Verilog source to this project has no dependencies, and is distributed under the DWTFPL version 3. This is a very permissive open-source licence, and its text is included in full at the top of the source files. This license is very similar to the original DWTFPL, which more readers may be familiar with, but has an added indemnification clause.
This license is also known by its more formal name, as the “Do What The Fuck You Want To And Don’t Blame Us Public License”.

## 2 CPU Architecture

Hazard5 is a 32-bit processor based on the RISC-V instruction set architecture. It accesses the system through a single AMBA 3 AHB-Lite master port. Those familiar with the textbook 5-stage RISC pipeline will find Hazard5 mostly straightforward, but hopefully will still find some interesting tricks. We will use the following symbols to refer to the 5 stages:

| F: fetch
| D: decode
| X: execute
| M: memory access (load/store)
| W: register writeback, fetch address generation

Hazard5 supports the RV32IC instruction set, whose encoding is variable-width. The C extension typically reduces instruction bandwidth by ˜25%, which helps to maintain performance when sharing bus access between fetch and load/store.
Branches are speculated, but there is currently no dynamic branch predictor. Instead, we use the static prediction scheme described in the RV ISA manual (based on sign of branch offset).

### 2.1 Frontend

Figure 2: Hazard5 processor frontend, block diagram

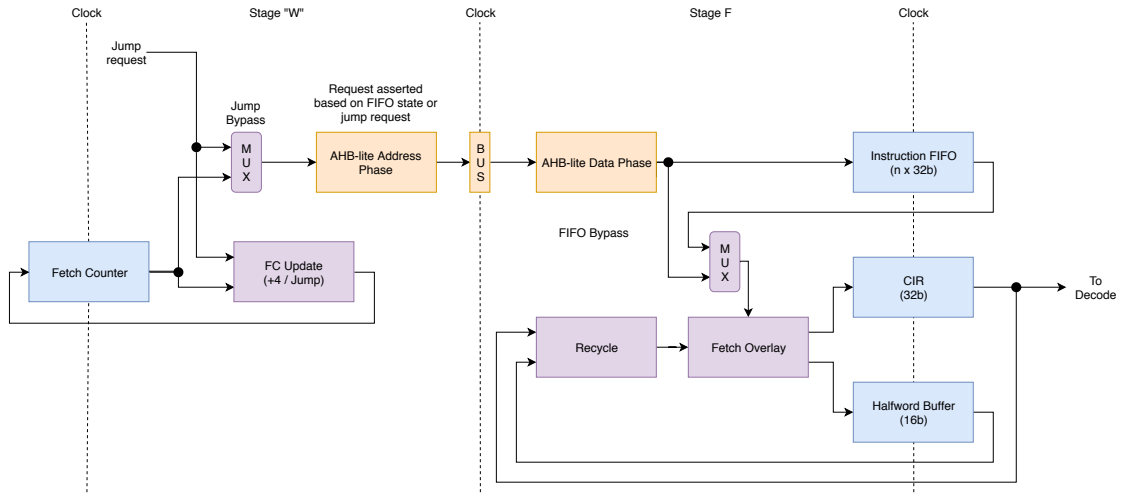
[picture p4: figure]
Instruction FIFO (n x 32b); Halfword Buffer (16b); CIR (32b); To Decode; Clock; AHB-lite Data Phase; Recycle; Fetch Overlay; FIFO Bypass; AHB-lite Address Phase; Fetch Counter; Request asserted based on FIFO state or jump request; FC Update (+4 / Jump); Jump request; Stage "W"; Stage F; Jump Bypass

The frontend (figure 2) consists of stage F and an additional stage which performs the AHB address phase, and can be considered part of W. Its purpose is to feed D with instructions, whilst meeting the following constraints:

| No combinatorial path from AHB-Lite data phase to address phase (e.g. hready → htrans)
| AHB-Lite compliant: no unaligned transfers, no deassertion or change of active requests
| Provide up to 32 bits of instruction data per clock in steady state, even if instructions are unaligned
| 0-cycle jump/flush to AHB address phase assertion (with minimal logic on this path)
| No performance penalty for unaligned jump to 16-bit instruction
| Attempt to maintain performance when competing with the load/store unit and AHB-Lite busmaster peers

The main source of complexity is that a RISC-V *C instruction stream is not naturally-aligned, i.e. instruction address modulo instruction size is not always zero. We spend gates here to optimise the common case of sequential execution, and to lessen the effects of fetch starvation due to load-store activity.
To meet these constraints, the frontend performs almost exclusively word accesses, which must be aligned. The only exception is a jump (or similar, e.g. mispredict recovery) to a non-word-aligned address. In this case, a halfword fetch from the target address is performed.

### 2.1.1 Prefetch Queue

The frontend queues up fresh instruction data which is waiting to be decoded. The pipelined nature of AHB-Lite means that the bus transfers run ahead of D by at least two clocks, and the prefetch queue is able to buffer these in-flight transfers if D stalls against a later pipe stage. The queue also decouples D’s stall logic (which is a function of hready) from the address phase request, and finally, the queue helps keep D supplied with instructions while the busmaster is busy with load/stores from X.
There are three parts to the queue:
| A 32-bit FIFO. The depth is configurable, and can be as little as 1 word.
| A halfword buffer which may store the higher-addressed half of a recently-popped FIFO word
| The upper half of the current instruction register (CIR), if the previous instruction was 16-bit

These three sources should service the majority of instruction fetches, and fresh bus data is written only to the FIFO. However, following jumps, flushes, or fetch starvation (either due to load/store activity or bus wait states), bus data can be forwarded directly to CIR.

### 2.1.2 Program Counter

Hazard5 does not use the program counter (PC) for code fetching, during sequential execution. PC is used exclusively for the link value in JAL(R), mispredict recovery, and PC-relative addressing; it is physically located in D.
The frontend fetches instruction data from consecutive word-aligned addresses, paced by backpressure from the instruction FIFO; PC is not involved. However, as a special case, it does need the full jump target address (which becomes the new PC), as unaligned jumps require special attention.

### 2.1.3 Arbitration of Fetch and Load/Store

The single AHB master port asserts transactions from two sources: the frontend, whose address phase is in W, and the load/store unit, whose address phase is in X. Frontend requests may be linear or non-linear (e.g jumps). The rules are:

1. If a jump or mispredict recovery is asserted by M, this wins.
| Any requests from earlier stages are logically later in program order.
| If M wants to jump then these instructions are being executed in error, so should certainly not be
permitted to access the bus.
2. Else if a load/store is asserted by X, this wins.
| Stalling instruction fetch may be covered by the prefetch queue, in which case we’ve lost nothing
| Stalling a load/store will always increase execution time
| If instead X stalled, and instruction fetch ran ahead, what would we do with the fetched instructions?
3. Otherwise, perform any other access requested by the frontend.

Always Be Fetching

The fetch and load/store interfaces are well-decoupled; it would be simple to remove the arbiter and create a 2-master processor configuration. (TODO: add a wrapper that does this!)

### 2.1.4 Jumps and Branches

Due to the pipelined nature of AHB, we are unable to jump or to take branches in fewer than 2 cycles (without adding sophisticated prediction):

| Cycle 0: AHB data phase for fetch of jump/branch. Next instruction is in address phase concurrently.
| Cycle 1: Jump/branch instruction is now available to D

– (Quickly) use to control the new address phase

– The immediately following instruction is already in data phase

| Cycle 2: Data phase for jump target instruction
| Cycle 3: Jump target is presented to D and decoded.

We knew the jump target on cycle 1, but did not begin decoding the targeted instruction until cycle 3. We also made one wasted code fetch. This is suboptimal, but fetching the jump target before decoding the jump is tricky, and there are lower-hanging fruit in terms of performance per LUT.
Jumps physically occur in W, directly in front of the fetch address generator. There are two reasons to jump:
| Inspecting the CIR in F/D pipe register (JAL, speculated taken branches)
| Inspecting X/M pipe register (JALR, branch mispredict recovery)

JALR (indirect jump) is taken later because it uses the register file and the ALU to compute its target.
If both of these sources attempt to jump in the same cycle, X/M takes priority, since it is executing an older instruction. In both cases, the part of the pipeline in the hazard shadow is invalidated; i.e., W → F, or W → X. Invalidation is performed by clobbering the pipeline control signals in such a way that these instructions will have no side effects.
The branch prediction scheme is static: take backward branches, and do not take forward branches. The cycle costs are as follows:
Jump Type | Cycles (Execution + Penalty)
Direct jump | 2
Predicted, non-taken branch | 1
Predicted, taken branch (same as jump) | 2
Indirect jump | 4
Branch mispredict | 4

Upon jumping, we need some mechanism to invalidate parts of the pipeline: this is described in section 2.2.2.

### 2.1.5 CIR Locking

There is a landmine in the following tableau:

| M contains a load (in data phase), and the bus is stalled
| X contains an instruction dependent on the load result; say an AND
| D contains a branch which is mispredicted taken

For example, say we are polling a status bit in an IO register, looping until some bit is high. The instruction in X must stall for at least two cycles due to the bus stall and load-use hazard. Due to a frontend design constraint from 2.1 – “No combinatorial path from AHB-Lite data phase to address phase (e.g. hready → htrans)” – we must not use X’s stall signal to gate the jump request, as this would create such a path. However, not gating the jump request is fatal, as new fetches will clobber CIR before the branch instruction can proceed into X, so the mispredict will never recover. JAL has the same problem: it will jump, but not produce a link address.

Hazard5 resolves this with CIR locking. D signals to F that CIR and its validity count must not change on the next clock edge, and uses this same signal to inhibit repeated assertion of its own jump request. In the fetch path, this is achieved by steering the controls on the existing shift/overlay logic in the frontend, and requires no additional muxing.
Whilst the CIR is locked, the frontend is still free to act on the jump request, and fetch ahead along the new code path (more useful for JAL); this data is buffered in the FIFO. Once the roadblock ahead of D clears, the branch instruction proceeds down the pipeline, and the lock is released simultaneously.
Note also that a bus stall does not cause the frontend to block jump requests, as this too would create a combinatorial path, since requests are forwarded straight to the bus (due to another constraint from 2.1). The frontend’s response to bus stall on jump request is simply to not increment the target before storing to FC, so that the target address continues to be asserted on subsequent cycles. Registered feedback blocks subsequent jump requests until the first request completes its address phase.

### 2.1.6 Instruction Barrier (FENCE.I)

If the program stores to instruction addresses about to be executed from, which potentially exist in the prefetch queue, a stale instruction will be executed. FENCE.I cannot be decoded as a nop, and requires special handling. Hazard5 decodes FENCE.I as “jump to PC + 4”. The jump invalidates the prefetch queue, and the following instruction will be re-fetched from memory.
Timing analysis shows that calculating a jump target, between CIR and the address bus, is generally on the critical path. To avoid more logic on this path, FENCE.I is instead implemented by spoofing a branch-taken mispredict, which has the same effect. This adds two cycles to the execution time, but performance of this instruction is decidedly noncritical.

### 2.2 Backend

The backend is the hardware which manipulates the processor’s architectural state according to the stream of instruction data from the frontend. Architectural state refers to the state you will read about in the ISA manual, and includes the register file and program counter; the backend also contains some non-architectural state, e.g. holding intermediate results in between pipeline stages.
The backend consists of stages D, X, M. Its overall structure is depicted by figure 3. This is a pretty large figure – too large to print really – so you can view it separately at https://github.com/Wren6991/RISCBoy/raw/master/doc/diagrams/cpu_backend.pdf (https://github.com/Wren6991/RISCBoy/raw/master/doc/diagrams/cpu_backend.pdf)

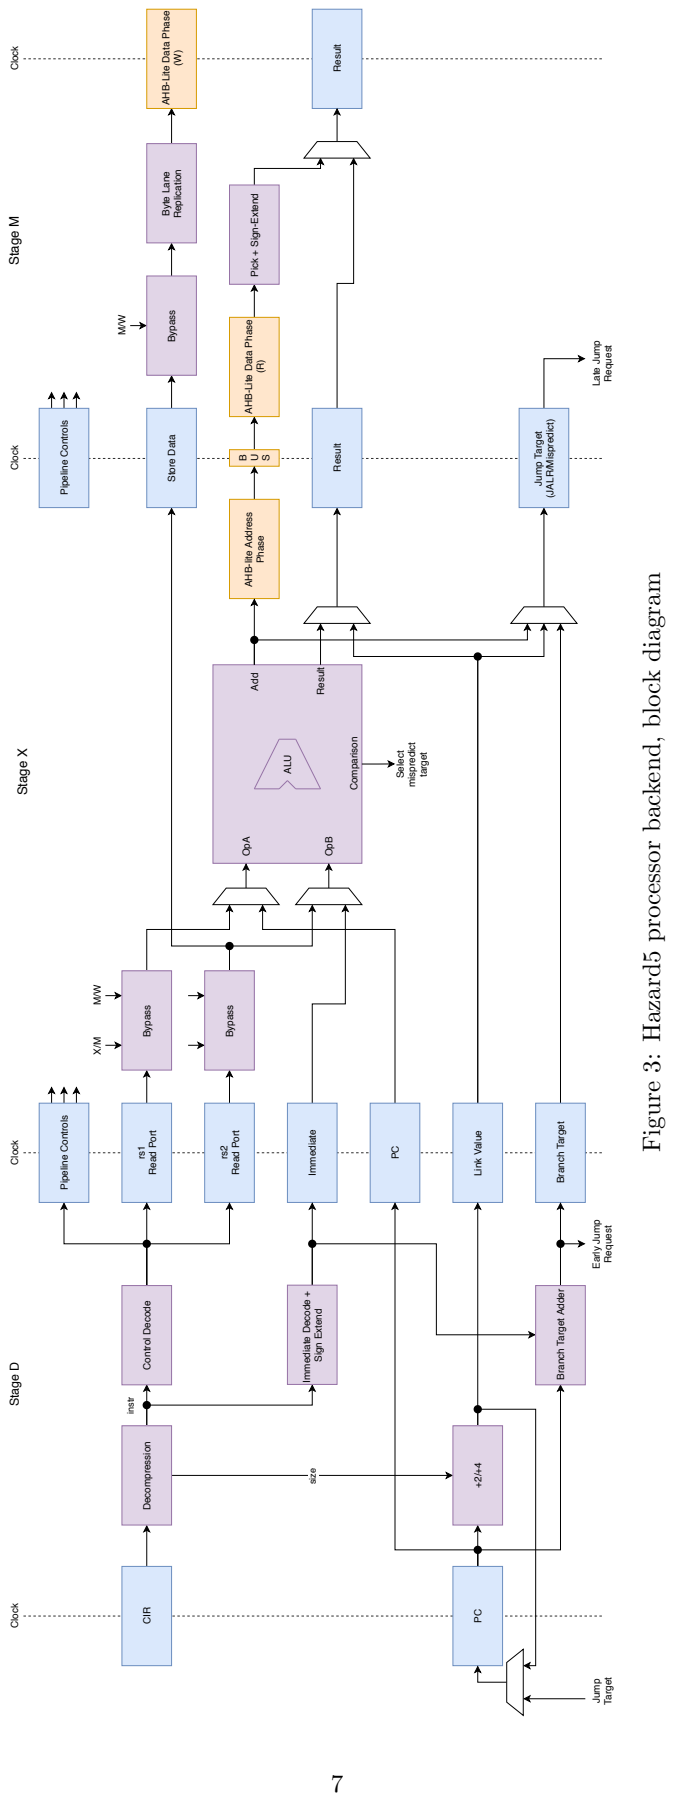
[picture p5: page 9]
Read Port; CIR; size; instr; Decompression; Branch Target; Link Value +2/+4; Immediate; Control Decode; Immediate Decode +; Sign Extend; Pipeline Controls; ALU; OpA; OpB; Add; Comparison; Result; Bypass; Early Jump; Request; Jump Target; Clock Stage D; Result BUS; Phase; (JALR/Mispredict); Late Jump; Replication; Clock Stage M; Select; mispredict; target

AHB-Lite Data Phase

Store Data Bypass Byte Lane

Pick + Sign-Extend

AHB-lite Address

Figure 3: Hazard5 processor backend, block diagram

Clock Stage X Clock

Branch Target Adder

### 2.2.1 Operand Bypass

Hazard5 possesses an operand bypass (forwarding) network. Register writes must always be visible to later instructions, even before an earlier instruction reaches register writeback. One solution is to detect that one instruction depends on the result of an earlier instruction (a read-after-write, or RAW hazard) and stall the later instruction until the earlier one completes. This is safe, but incurs a hefty performance penalty; a more elegant solution is to pluck the result of the earlier instruction straight from the pipeline, before it finishes executing (but after the result is valid!).
Locations of bypasses are shown in figure 3. The following bypasses are available:
| X/M → X
| M/W → X
| M/W → M
| W/X → X

The last is in lieu of a write-to-read bypass in the register file; some tools (not Yosys!) struggle with inferring memories from transparent memory models, so it’s better to be explicit.
To control the bypassing, some of the register specifiers from CIR are passed down the pipeline alongside the data. rs1, rs2, rd (operand sources and destination) are passed down as far as X. rs2, rd make it to M, and only rd makes it to W.
The upshot is:
| Back-to-back ALU operations execute at 1 CPI
| Loads insert 1 stall cycle if immediately required by the ALU. 1 CPI otherwise.
| Stores execute at 1 CPI (bus stall notwithstanding)
| In a load + store pair, the load takes only one cycle, since the M stage has self-forwarding

Various interesting strategies can alleviate load-use penalty in in-order pipelines, such as adding a second, “late” ALU in the M stage. In our case we judge this to not be worth the LUTs.
Another interesting strategy is to add muxing at the register file write port, to select which stage to retire from. This has the dual benefit of firstly simplifying the operand bypass, and secondly reducing dynamic power, since there is no need to pass data through unused stages (and they can be clock gated). Hazard5 does not use this strategy either – maybe the next project.

### 2.2.2 Pipeline Stalling and Flushing

Our terminology: stalling means a pipeline stage does not advance its state until some blocking condition has cleared. The instruction residing in this stage will not progress to the next stage, and the previous stage will not write its instruction into this stage. Flushing is when in-flight instructions in some stages are replaced with NOPs, and their results are discarded.
The frontend is decoupled from other stages’ stall logic via the prefetch queue. This is important: hready is an input to that stall logic, and the the frontend’s address-phase request must not be a function of hready.
The frontend may not be able to immediately accept a jump request, which may cause other pipe stages to stall if it is low. One cause is the frontend holding an existing address-phase request stable until the cycle after hready, which is required for AHB-Lite compliance.
For the backend, the stall logic is more intricate, as signals such as hready are used in-cycle to determine whether an instruction progresses to the next pipeline stage:

D:

– CIR does not contain a valid instruction (either no data, or half of a 32-bit instruction)

– D asserts jump, but frontend rejects the jump request – X is stalled

X:

– hready low and X address-phase request asserted – RAW hazard on M (load-use)
– M is stalled
| M:
| – hready low and data-phase active – M asserts jump, but frontend rejects the jump request
| W: does not stall

If a given stage is stalled, but the following stage is not, it must insert a bubble. Bubbles are created by zeroing out control fields, such as rd, so that the instruction cannot affect system or processor state.
There are two cases where we must flush:
| Branch/jump taken from D; frontend invalidates prefetched data
| Jump/mispredict taken from M; must flush frontend, D, X

And the flushing mechanisms for each stage are as follows:

| D: destination register rd cleared, which makes result invisible to register file and operand bypass. memop, branchcond pipe flags are cleared.
| X: same as D (except for branchcond, which does not pass on to M anyway.

Flushing and bubble insertion are very similar in mechanism.

### 2.3 Unaligned Memory Accesses

Alignment is the constraint that the address of a memory access be equal to zero, modulo some size. Where no size is specified, we refer to natural alignment, i.e. modulo the size of this particular memory operation. RISC-V requires that memory is byte-addressable.
The frontend goes to some length (section 2.1) to maintain high throughput. RV-C instruction streams are always unaligned, and every instruction must be fetched before it is executed, so Amdahl says it’s worth it. On the other hand load/stores are less than 100% of all instructions, and the vast majority are unaligned; consequently, Hazard5 does not have hardware support for unaligned load/stores. These are trapped (TODO) and handled in software if and when they occur.

### 2.4 Control and Status Registers (CSRs)

Hazard5 possesses the standard Zicsr extension, which provides atomic access to the CSRs. Only M-mode CSRs are implemented. Access to an unimplemented CSR (e.g. a U-mode or S-mode CSR) causes an illegal instruction exception. The implementation is minimally legal: WARL fields are widely exploited, to reduce logic and state overhead. Module parameters can reduce CSR support, or remove it entirely, as per relative importance of compliance versus area in your application. Note that some features, such as interrupts and exceptions, require CSR support.
When the counter CSRs are present, mtime and mcycle are aliased to the same counter. 64-bit counters are prohibitively large in a compact 32-bit processor. The mcountinhibit (WARL) register is tied to zero: mtime must run freely, hence the mcycle alias of this counter cannot be halted either. minstret is fully implemented, but its mcountinhibit bit is also tied low. The width of the counters can be reduced from 64 bits to save logic (noncompliant), although the full 64 CSR bits remain writeable, which leaves some opportunity for software emulation.
TODO: full table of CSRs we implement, and to what extent they are implemented/WARL’d

### 2.5 Interrupts and Exceptions

Figure 4: Hazard5 trap vector table layout

Trap Table Offset | mcause | Trap Description
0x00 | 0x00000000 | Misaligned instruction access
0x04 | 0x00000001 | Instruction access fault
0x08 | 0x00000002 | Illegal instruction
0x0c | 0x00000003 | Breakpoint
0x10 | 0x00000004 | Misaligned load address
0x14 | 0x00000005 | Load access fault
0x18 | 0x00000006 | Misaligned store address
0x1c | 0x00000007 | Store access fault
0x20 | 0x00000008 | Reserved
0x24 | 0x00000009 | Reserved
0x28 | 0x0000000a | Reserved
0x2c | 0x0000000b | M-mode ECALL
0x30 | 0x0000000c | Reserved
0x3c | 0x0000000f | Reserved
0x40 | 0x80000000 | Reserved
0x44 | 0x80000001 | Reserved
0x48 | 0x80000002 | Reserved
0x4c | 0x80000003 | Machine software interrupt
0x50 | 0x80000004 | Reserved
0x54 | 0x80000005 | Reserved
0x58 | 0x80000006 | Reserved
0x5c | 0x80000007 | Machine timer interrupt
0x60 | 0x80000008 | Reserved
0x7c | 0x8000000f | Reserved
0x80 | 0x80000010 | External IRQ 0
0xbc | 0x8000001f | External IRQ 15

Hazard5 has simple exception and interrupt support, compliant with the RISC-V privileged ISA spec (M-mode only). Here we follow the terminology set out in the RISC-V user-level spec: an exception is an anomalous condition caused by executing an instruction, which requires control transfer; an interrupt request is some external, asynchronous event, which requires control transfer; a trap is the transfer of control to a handler, used to service either an interrupt or an exception. Hazard5 implements interrupts and exceptions as follows:

Trap entry causes a jump to a location in the trap vector table (addressed by mtvec), simultaneously stashing the PC in mepc

– Other CSR state is also modified, e.g. mcause, mstatus

– The physical mechanism for this jump is the same as a branch mispredict

Trap exit, via the mret instruction, causes a jump to mepc

– mret also modifies some diagnostic CSR state, e.g. mstatus, as per the privileged ISA specification

| Only vectored mode is available. I.e., the LSBs of mtvec are tied to 0x1.
| When written, mtvec is rounded down to a 4kB boundary. This saves an adder when generating the trap
vector address.

Besides PC, the hardware saves/restores no architectural state on entry/exit. Software is responsible for stacking/unstacking the GPRs.

External IRQs can be observed and masked in bits 31:16 of mip and mie. This limits the number of IRQs to 16, but this limit could be increased by additional nonstandard CSRs to observe and mask more external interrupts. The layout of the trap table is in figure 4. Where a standard exception or interrupt is unimplemented (S/U mode) or irrelevant (page faults), it is marked as reserved. In particular, the standard machine external interrupt vector (mcause = 0x8000000b) is not used, and external interrupts are instead separately routed to mcause = 0x80000010 and above. This layout has been arranged to produce an obvious mapping between mcause and trap vector address, which unfortunately bloats the table with reserved vectors.
To save space, it is reasonable for initial bootcode to include only the first 12 entries in the table (the exceptions), and run with interrupts disabled until it has populated a more complete table elsewhere in memory, which it can then point to by modifying mtvec.
Trap handlers do not preempt one another. After a trap returns, the highest-priority active trap request is selected, and its handler entered. Normal execution continues while there are no active trap requests. Exceptions take priority over IRQs, and lower-numbered IRQs are higher priority. An illegal instruction exception encountered while handling an exception causes a lockup of the core (details TBD). TODO: table of the exception/interrupt space
IRQ inputs are level-sensitive. It is recommended to clear an interrupt at its source upon entering its handler. If the interrupt reasserts before the handler mrets, the handler still returns, and the interrupt competes with other trap requests for reentry. Note that, if many register stages are present on the IRQ signal, there is a potential race between clearing the IRQ and executing the mret, causing spurious reentry; in practice, restoration of caller-saves should provide ample time for IRQ deassertion to be observed, before the mret is reached.

### 2.6 Plugin Interface

Plugins are pieces of hardware attached to the Hazard5 pipeline to extend its functionality, and instruction set. For example, the M extension (multiply and divide) is implemented using a plugin.
Plugins interact with three pipe stages:

D

– Plugins see the current instruction, so that they can decode it

– Plugins notify D that an instruction it does not recognise is, in fact, valid

X

– Plugins can see the rs1 and rs2 operand bypasses
– Additional control signals provide functionality such as killing an in-progress operation so that e.g. an interrupt can run

M

– All plugins retire their results into M.

– This adds a 1-cycle RAW stall if the immediately-following instruction is dependent, but on current iCE40 implementations, X is already near-critical-path and very mux heavy.

– Plugins can stall M if they need more cycles to produce a result.

There is no hard limit to the number of plugins that can be added, but the additional muxing and fanout is not free, which constrains practical implementations.

### 2.6.1 M-small Plugin

The M-small plugin implements the RISC-V M standard extension (multiply, divide and modulo). To save area, the plugin employs a combined multiply/divide unit which performs all required calculations, at 1 bit per clock. If timing permits, the datapath can be unrolled to perform multiple iterations per clock. e.g. radix-4 divide/multiply.

### 2.6.2 M-fast Plugin

The Mfast plugin also implements the M extension, but uses a fast Wallace tree to perform multiplication, allowing a throughput of 1 32-bit multiply per clock.
Other details TBD

## 3 Pixel Processing Unit (PPU)

Figure 5 shows the high-level structure of the PPU. This is the second-generation architecture – the previous version had a number of sprite and tile engines operating in parallel, with shared bus access. This was a mistake. Many of these units were idle much of the time, and they were stripped down to the minimum to meet strict area requirements; this in turn led to poor bus utilisation and a lack of flexibility. The second problem was partially solved by the Poker, but at the expense of high software complexity for common use cases (e.g. many sprites on screen). The high level goals of PPU2 are, in order of precedence:

1. Always Be Fetching
2. Avoid idle or duplicated base functional units (e.g. pixel unpacker) so that more expensive functions can be provided (e.g. random access to pixels)
3. Be highly programmable, and allow features to be combined in interesting ways
4. Serve the simple use cases (layered, tiled backgrounds with sprites) with minimum program complexity
5. Mario Kart: Super Circuit

Fundamentally we are fetching pixels from memory (over a 16 bit bus on RISCBoy), and putting them on the screen in interesting orders. If we saturate the bus, and do not waste what we fetch, our performance is as good as it possibly can be.

Figure 5: Pixel processing unit, block-level diagram

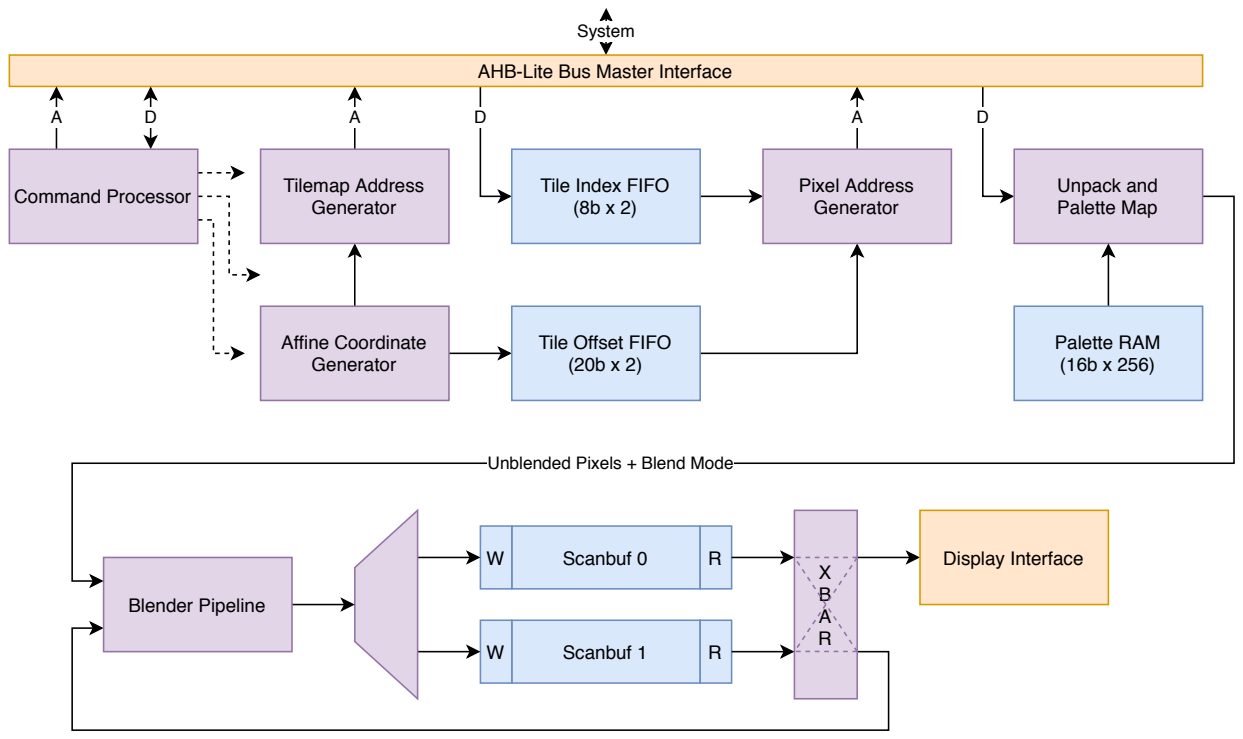
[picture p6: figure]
Scanbuf 0; Scanbuf 1; Blender Pipeline; Unblended Pixels + Blend Mode; Unpack and Palette Map; Affine Coordinate Generator; Tilemap Address Generator; Tile Index FIFO (8b x 2); Tile Offset FIFO (20b x 2); Pixel Address Generator; System; AHB-Lite Bus Master Interface; Command Processor; Display Interface; Palette RAM (16b x 256)

At any point in time the PPU is either rendering to one of the internal scanline buffers, or waiting for a buffer to be freed and passed back by the display interface hardware. The exact sequence of operations the PPU performs while rendering is defined by a program in memory, executed by the command processor. The instruction set is small, and specialised to the task at hand – for example the SYNC instruction marks the current scanline buffer as ready for display, and waits for a buffer be freed by the display hardware, and the FILL instruction writes a constant-colour span to some x range of pixels.

Common memory access patterns (for nonpaletted pixels):

| Sprite blitting: fetch a pixel from memory every cycle
| Tiling: fetch a tile index after every n pixels, then n pixel fetches
| Affine-mapped tiling: fetch tile indices and pixels on alternate cycles

The display controller attaches to a dedicated interface on the PPU. Through a simple handshake, the display controller can acquire and release dirty scanbuffers. The display interface routes read addresses from the display controller to the correct scanline buffer, and routes pixel data back to the controller. Currently two display controllers are available to connect to this interface: one for serial LCDs such as ILI9341, and another for direct DVI output. The PPU display interface is synchronous, and any clock crossing (to SCK domain for serial LCDs, or pixel clock domain for DVI) is handled inside the display controller.

### 3.1 Pixel Formats

Internally, the PPU uses a single native pixel format, namely ARGB 1555 (see figure 6), but it can stream pixels from memory in a variety of formats, and convert internally. PPU memory accesses are always little-endian: for performance reasons the PPU performs the widest possible fetch, yielding multiple pixels each, which are numbered least-significant-first.

Figure 6: PPU pixel formats

0459101415

A | R | G | B | Mode 0: ARGB1555, alpha = 0 when transparent

07

Index | Mode 1: P8, an index into a table of 256 colours

03

| | | Index | Mode 2: P4, an index into a table of 16 colours

0

I Mode 3: P1, an index into a table of 2 colours

For pixels smaller than one byte, the pixel order continues to be defined in a little-endian fashion, i.e. the least-significant pixel will be the first to be displayed. The PPU also requires image base addresses to be word-aligned, which implies all pixels are naturally aligned.

### 3.2 Palettes

The PPU contains a single hardware palette memory (PRAM), which is large enough to store 256 colours in ARGB1555 format. Each pixel in a paletted image (see figure 6) consists of an index into PRAM. The PPU looks these indices up before passing pixels to the screen; wide colour range is maintained at reduced bits per pixel. Since PRAM contents is in ARGB1555 format, there is no special convention for indicating whether a paletted pixel is transparent: the hardware always performs the palette lookup, and the resulting colour may or may not have its Alpha bit set.
Although there is only a single hardware palette, 256 colours in size, TILE and BLIT commands can supply an offset, which is added to each paletted pixel before palette lookup. PRAM may be initialised with e.g. multiple 16-colour tables at different (potentially overlapping) locations, giving effectively independent palettes.
PRAM can be written to (but not read) through the PPU’s configuration interface.

### 3.3 Scanline Buffers

The scanline buffers are implemented as 1-read 1-write memories, which allows the blending pipeline to easily achieve a 1 pixel per clock throughput, keeping the bottleneck on the system bus. This could also be implemented as a double-width 1RW memory, but not a compelling tradeoff on FPGA.

Figure 7: PPU scanline buffer states

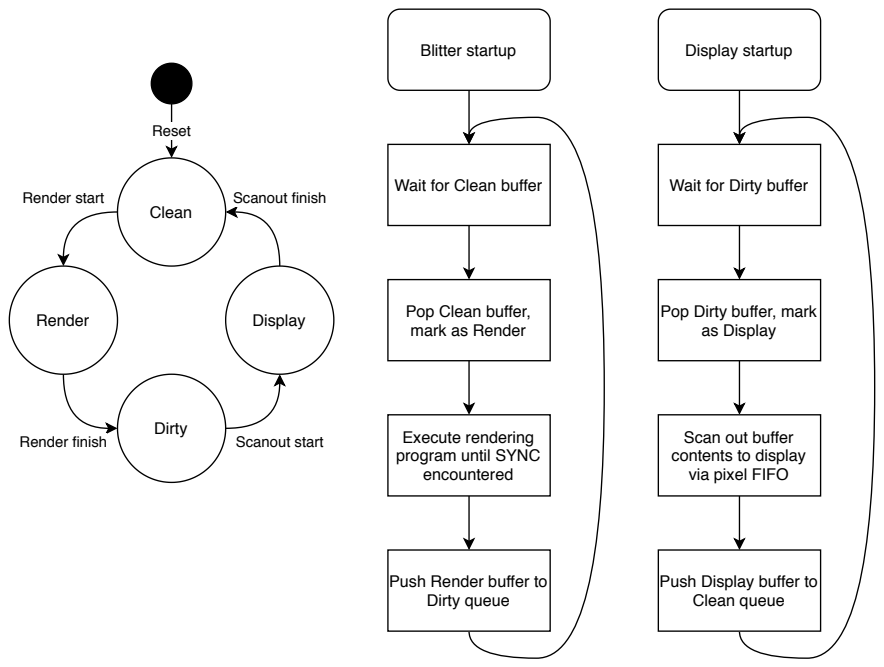
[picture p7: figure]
Render finish; Render; Scanout start; Dirty; Scanout finish; Display; Render start; Clean; Push Render buffer to Dirty queue; Wait for Clean buffer; Pop Clean buffer, mark as Render; Blitter startup; Execute rendering program until SYNC encountered; Display startup; Wait for Dirty buffer; Reset; Pop Dirty buffer, mark as Display; Scan out buffer contents to display via pixel FIFO; Push Display buffer to Clean queue

On RISCBoy these are 15b×512 memories, each composed of a pair of iCE40 4 kb block RAMs. This is sufficient to store one QVGA RGB555 scanline in each buffer. The blitter and display pass each other buffers through a pair of queues, one containing clean buffers for the blitter, and the other containing dirty buffers for the display. After reset, both buffers are in the clean queue.

### 3.4 Instruction Set

Each instruction consists of one or more words in memory; the blitter processes each instruction in turn, progressing in a linear fashion unless a POPJ is encountered, or the PPU is manually vectored to a new program by system software. This section describes the encoding of blitter instructions, and their operation. Some fields are marked as reserved, denoted by a grey colour fill in the bit diagrams. Reserved fields are not used by the current hardware, and should be written all-zeroes by software.
For simple purposes (e.g. tiled backgrounds with some sprites on top), the blitter can execute the same program on each scanline: the coordinate systems of BLIT/TILE commands take the current raster y coordinate into account (see section 3.5). However, the instruction set is quite flexible, and the blitter’s features can be combined in interesting ways, with fancy-looking results.

SYNC

272831 | 0
0x0

Present the current scanline buffer to the display, then stall until a clean buffer becomes available. If CSR HALT HSYNC is set, or CSR HALT VSYNC is set and this is the last line of the frame, halt the PPU.

CLIP

09101920272831
0x1 | | | x end | x start

Set the active region for rendering. Pixels at x coordinates less than x start or greater than x end will be unaffected by subsequent FILL, [A]TILE or [A]BLIT operations. This region remains in effect until another CLIP is executed.
Often it is sufficient to perform an initial CLIP to the screen width, and never change from this value, but CLIP has numerous applications when combined with pixel-filling operations: for example using CLIP + ABLIT pairs to render a sequence of short affine-textured spans.

FILL

0459101415272831
0x2 | R | G | B

Fill the entire clipped region with a single colour. Note that scanline buffers retain their old contents when passed back to the blitter by the display hardware; if you want a solid background colour, you must FILL it into each scanline, or include it in your background tileset.

BLIT

0910192021222425272831
0x4 | size | poff | y | x
31 | 012
img | fmt

Block image transfer: paste a square image (e.g. a sprite) over the current scanline. If this image does not intersect the current scanline due to its position and size, or if it is fully outside of the clipped region on this scanline, the BLIT command has no effect, and completes immediately. Generally BLIT is called on each scanline with the same arguments, to build up the full image. For example, each game sprite may correspond to a BLIT command which runs on every scanline.
BLIT also supports efficient framebuffer graphics: in this case each scanline will have a different BLIT command with a y equal to that scanline’s position, and a img pointer that is one scanline further advanced into a software framebuffer. This allows a framebuffer to be packed in memory as a flat width × height array of pixels.
| img is a pointer to the source image, which is assumed to be word-aligned (hence the missing LSBs).
| fmt is the pixel format, as described in figure 6. The values are: mode 0 ARGB1555, mode 1 P8, mode 2 P4,
mode 3 P1.

size defines the size of the source image: width = height = 2size+3, so square images from 8 to 1024 pixels are supported.

poff is the palette offset. This is left-shifted by 5 and added to each paletted pixel, with wrap on overflow, before the pixel is looked up in the palette RAM.

TILE

091019202122242526272831
0x5 | s | poff | yscroll | xscroll
31 | 012
tilemap | pfs
31 | 012
tileset | fmt

Render a tiled background span (see section 3.6).

xscroll and yscroll define the horizontal and vertical scroll of the tiled region. (TBD this may need to be redefined slightly for new PPU).

s defines the size of the source image: width = height = 2s+3, so square images of 8 × 8 or 16 × 16 are supported.

poff is the palette offset. This is left-shifted by 5 and added to each paletted pixel, with wrap on overflow, before the pixel is looked up in the palette RAM.

| tileset is a pointer to an array of 8 × 8 or 16 × 16 px images
| fmt is the pixel format of the tileset images, as described in figure 6. The values are: mode 0 ARGB1555,
mode 1 P8, mode 2 P4, mode 3 P1.

tilemap is a pointer to a 2D array of 8 bit tile indices. Each index identifies which image from tileset occupies that 8 × 8 or 16 × 16 px square.

pfs is the playfield size in pixels, width = height = 2size+7, so 128 to 1024 px. See section 3.6.

ABLIT

0910192021222425272831
0x6 | size | poff | h | y | x

0151631
b1 | b0

0151631
a01 | a00

0151631
a11 | a10
31 | 012
img | fmt

Like BLIT, except screen coordinates are transformed before each pixel lookup:

u = A(s − s0) + b

Where

u =

u vT
(texture coordinates)

s =

sx sy

T
(screen coordinates)

s0 =

x yT
(blit target position x, y)

A =

a00 | a01
a10 | a11
(scale/rotate/shear matrix)

b =

b0 b1

T
(translation vector)

This affine transform is described in detail in section 3.5. It allows a range of geometric manipulations of the source image. ABLIT renders to the same square region as BLIT, defined by the size, x and y parameters, as well as the current CLIP region. It is the texture lookup for each rendered pixel that differs.
The a components are signed 8.8 fixed point numbers, and b components are unsigned 10.6 fixed point.

h: half-size flag: indicate the texture is only half the size of the rasterized region in each axis. This allows e.g. a 32 × 32 px texture to be rotated, without scaling, by 45◦ and blitted to a 64 × 64 px region, so that its corners are not clipped. The effect of the half-size flag when size = 0 is undefined.

| img is a pointer to the source image, which is assumed to be word-aligned (hence the missing LSBs).
| fmt is the pixel format, as described in figure 6. The values are: mode 0 ARGB1555, mode 1 P8, mode 2 P4,
mode 3 P1.

size defines the size of both the source image and the blit target area: width = height = 2size+3, so square images from 8 to 1024 pixels are supported.

poff is the palette offset. This is left-shifted by 5 and added to each paletted pixel, with wrap on overflow, before the pixel is looked up in the palette RAM.

ATILE

091019202122242526272831
0x7 | s | poff | yscroll | xscroll

0151631
b1 | b0

0151631
a01 | a00

0151631
a11 | a10
31 | 012
tilemap | pfs
31 | 012
tileset | fmt

Like TILE but affine transform applied before each tile and pixel lookup: u = A(s − s0) + b. As with TILE, the entire CLIP region is rendered to. s0 is the xscroll, yscroll offset, the same as TILE. All in all, TILE can be thought of as a simple case of ATILE, where A is the identity matrix and b is the zero vector.

s defines the size of the source image: width = height = 2s+3, so square images of 8 × 8 or 16 × 16 are supported.

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

| tileset is a pointer to an array of 8 × 8 or 16 × 16 px images
| fmt is the pixel format of the tileset images, as described in figure 6. The values are: mode 0 ARGB1555,
mode 1 P8, mode 2 P4, mode 3 P1.

tilemap is a pointer to a 2D array of 8 bit tile indices. Each index identifies which image from tileset occupies that 8 × 8 or 16 × 16 px square.

pfs is the playfield size in pixels, width = height = 2size+7, so 128 to 1024 px. See section 3.6.

PUSH

272831 | 0
0xe
31 | 012
data

Push literal data onto the stack. The stack is popped only by a POPJ instruction, is 8 words deep, and wraps on empty/full.

POPJ

09102324272831
0xf | cc | a

Always pop an address from the stack. If cc is true, branch to this address. Values for cc:

| 0: always
| 1: YLT, current raster beam y < a
| 2: YGE, current raster beam y ≥ a

A regular jump is formed with PUSH addr; POPJ, and a subroutine call is formed with PUSH ret; PUSH target; POPJ; label ret: followed by a POPJ at the end of the target routine.
Subroutines are useful for when a part of your command list is repeated every scanline (e.g. a list of sprites, represented by BLIT commands) and a part is not (e.g. FILLing a different background colour every scanline to produce a gradient). Such a program can be structured as a larger per-frame command list which repeatedly calls into a per-scanline subroutine.

### 3.5 Coordinate Systems

The origin of the screen is at the top left. x coordinates increase to the right. y coordinates increase going downward.

Figure 8: PPU screen coordinate system

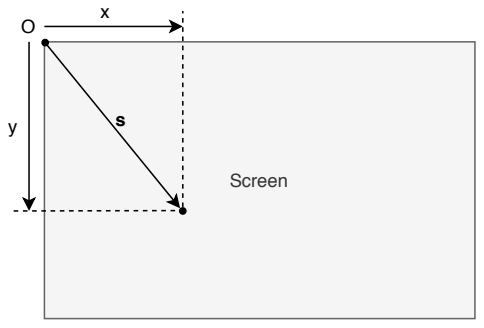
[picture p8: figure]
Screen

When using a vector to refer to a screen-space coordinate, we will typically use the symbol s.

Texture Coordinates

Figure 9: PPU texture coordinate system

O

u

v | u

Textures (e.g. sprite images) have completely independent coordinates. We will conventionally refer to pixels in texture space with the vector u =

u vT
. Textures are stored in memory as a flat array of pixels, going first in u order and then stepping down to the next row.
When drawing a sprite, the PPU does the following:
| Iterate over each pixel in some horizontal span of screen space
| For each pixel, transform the screen-space coordinate s into a texture-space coordinate u
| Look up the texture pixel at u and draw it on the screen at s

This transformation may be simple, as in the case of the BLIT command:

| u = s − s0

Where s0 is the position the texture is being blitted to (x, y in the BLIT instruction), s is the position of next pixel to be rendered on the screen, and u is the position in texture space which determines the colour of the screen pixel. The transformation may be more complex, as in the case of the ABLIT command:

| u = A(s − s0) + b

Where the matrix A and vector b are constants supplied by the ABLIT instruction, permitting any combination of translation, rotation, scale and shear. Note the direction of the definition: this is a mapping from screen space to texture space. If you find it more intuitive to think about mapping the texture onto the screen, you must note that this is the inverse of the above mapping, and you have some linear algebra to do.
Internally, the PPU represents u-space coordinates as pairs of unsigned 10.8 fixed point numbers (a range of 0 to 1023 + 255
| 256 ); the largest supported texture size is therefore 1024 × 1024 px.
As far as coordinates are concerned, there is no difference between e.g. a 512×512 px texture and a 512×512 px tiled background. The difference is that a texture’s pixels are defined by a single large image (512 × 512 px in this example), whereas the tiled area is defined by a number of small e.g. 16 × 16 px images called the tileset, and a 2D array of tile indices called the tilemap which defines which 16 × 16 px image should be at which 16 × 16 px region of u-space.

Affine Transforms

We gave the following definition for the transformation from screen space to texture space used by the ABLIT and ATILE commands:

| u = A(s − s0) + b

All of our examples will use the following texture which, for argument’s sake, is 64 × 64 px in size:

Figure 10: PPU texture example

| u

v

64 x 64 px

Like BLIT, ABLIT renders to a square area of the screen, starting at s0 (defined by the x, y arguments to ABLIT),

and extending rightward and downward by the texture size. If we set A = I =

1 0

0 1
and b =

0 0T
, then the

texture coordinate u is equal to the raster coordinate s − s0, and the ABLIT behaves the same as a BLIT:

Figure 11: PPU affine blit with identity mapping

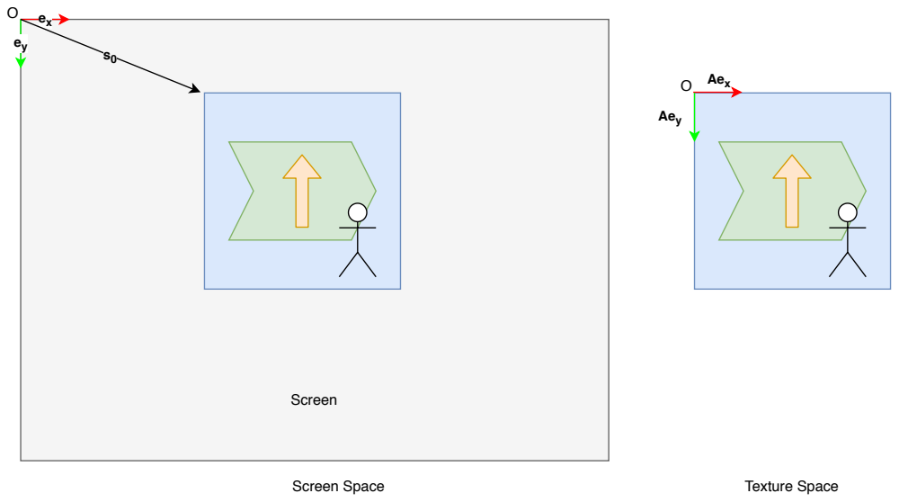
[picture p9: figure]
Screen; Aex; Aey; Screen Space; Texture Space

Setting A to the identity matrix maps the screen-space unit vectors ex and ey to the texture space’s unit vectors

eu, ev. The texture is undistorted. If we instead set A =

0 1

1 0
:

Figure 12: PPU affine blit with reflection in u=v

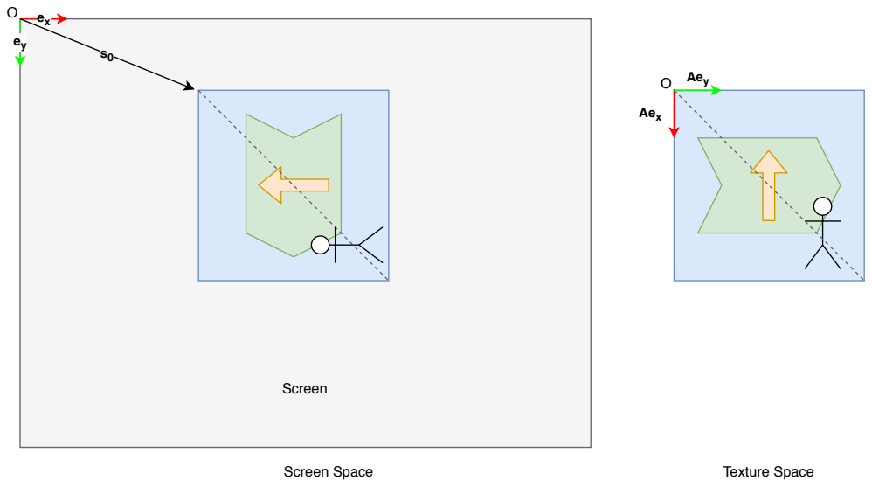
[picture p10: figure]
Screen; Aex; Aey; Screen Space; Texture Space

The horizontal axis in screen space (ex) has instead been mapped to the vertical axis in texture space (ev), and vice versa. Texture lookups have been reflected across the line u = v.
We can perform a uniform scale by setting A = λI, which maps the screen-space unit vectors onto larger vectors in texture space, so that texture samples of neighbouring screen pixels are further apart on the texture. E.g. take

λ = 2:

Figure 13: PPU affine blit with uniform scale

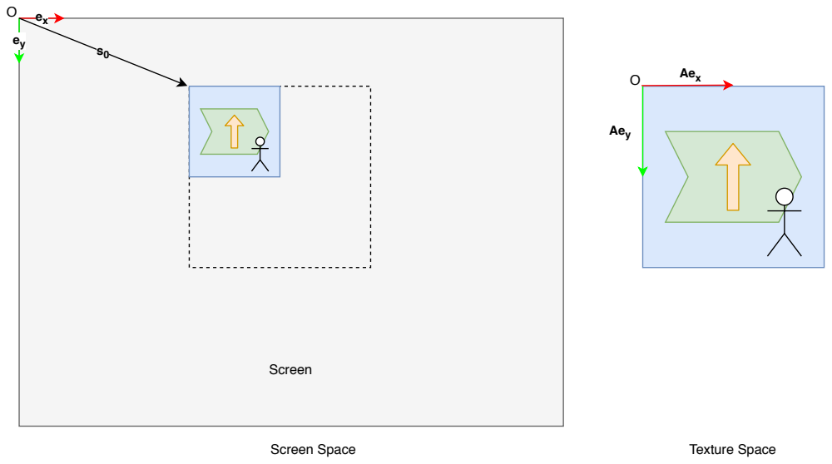
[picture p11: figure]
Screen; Aex; Aey; Screen Space; Texture Space

The b vector is used to translate texture lookups. It can be understood as the point in texture space to which the upper-left of the rasterised region is mapped, since at this point on the screen s = s0, so u = A(s0−s0)+b = b. For example, we could set b =

−32 −32T
, so that the sample corresponding to s0 is higher and further left in texture space:

Figure 14: PPU affine blit with uniform scale and translation

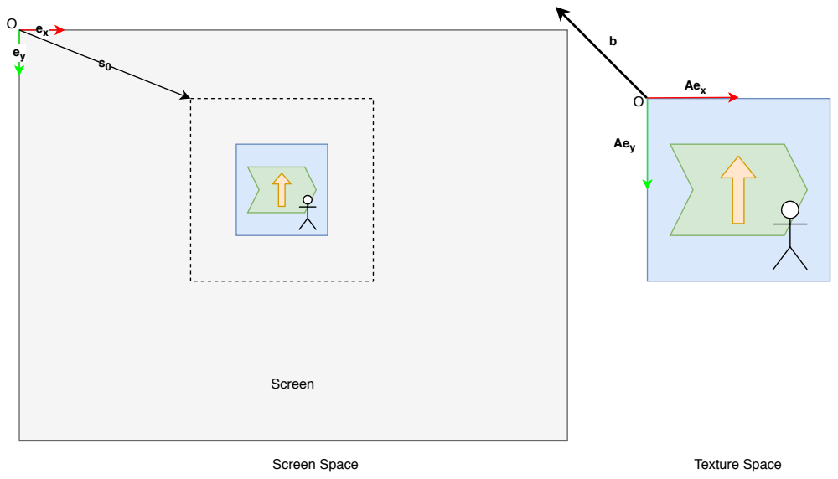
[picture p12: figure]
Screen; Aex; Aey; Screen Space; Texture Space

Figure 14 shows b plotted in texture space, and the resulting shift of the sampled texture as seen in the rasterised area. For a final example, the matrix

A =

cos θ − sin θ
sin θ cos θ

Defines, in our coordinate system, a clockwise rotation by θ. Setting θ = 45◦
, scaling by 2 and carefully choosing the b vector, we can make the texture appear to rotate counterclockwise about its centre in screen space.

Figure 15: PPU affine blit with rotation

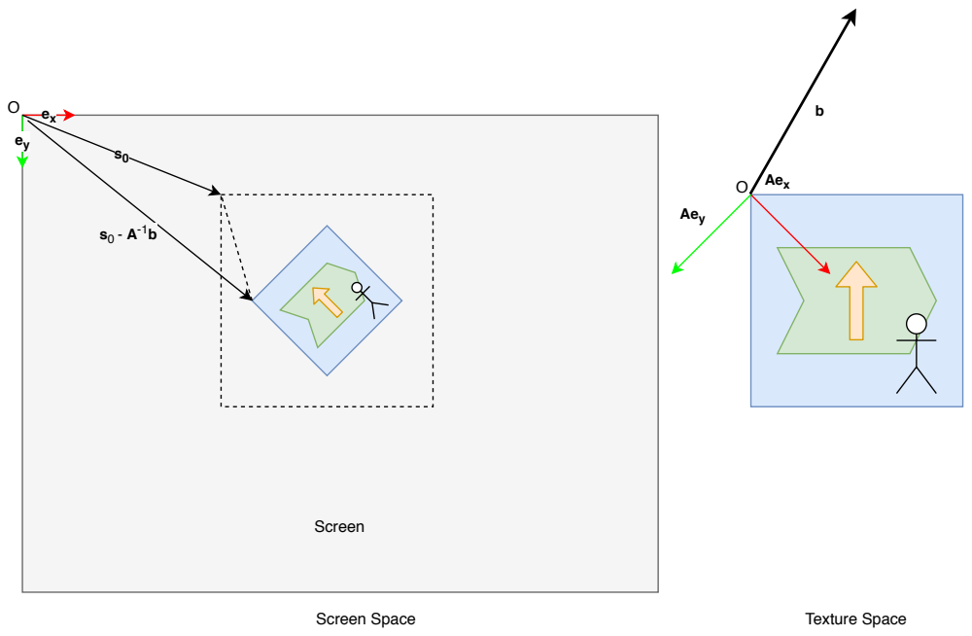
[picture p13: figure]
Screen; Aex; Aey; Screen Space; Texture Space

Note that, without a scale factor, the corners of the texture would be clipped to the rasterised region of the screen. It is quite inefficient to take a large texture and always show it in a scaled-down form; ABLIT’s half-size flag reduces the texture size to half of the rasterised region, so a 64 × 64 px ABLIT would expect a 32 × 32 px texture, which would occupy the upper-left quadrant of the rasterised region if A = I and b = 0. This could then be rotated without scaling, and provided it is appropriately translated, the corners of the texture would not be clipped.

### 3.6 Tiles

To reduce memory footprint, the PPU is able to assemble scenes on the fly from an array of small images, known as tiles. TODO much of this section refers to old hw with dedicated tiled backgrounds engines

Figure 16: PPU background coordinate system

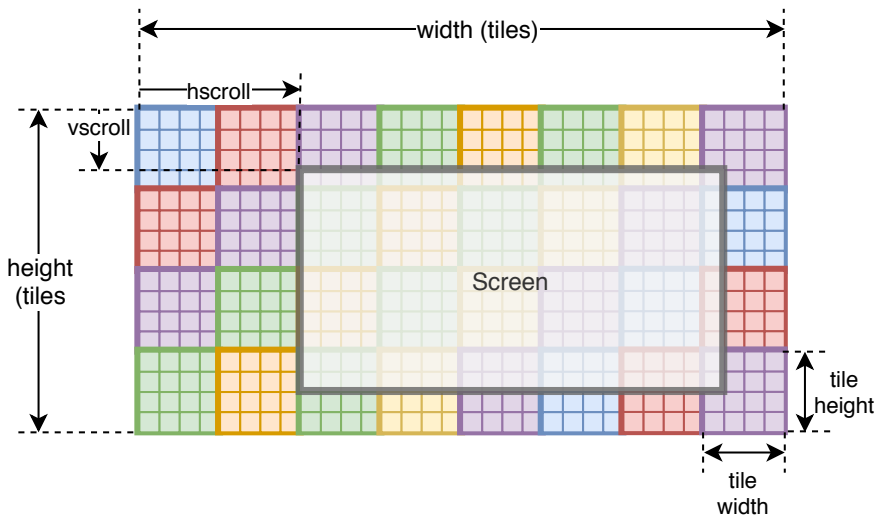
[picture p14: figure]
Screen; hscroll; vscroll; width (tiles); height (tiles; tile height; tile width

Each tile is a square image, the width and height of which (measured in pixels) is configured per-background, and is always a power of two. Tiles are stored as part of a larger image, known as the tileset. Tiles are numbered in a row-major order, starting at the top left of the tileset. An example tileset is shown in figure 17: this is a tileset of 8 tiles, each 4 × 4 pixels in size.

Figure 17: Example PPU tileset

+0

+16

Tile 0 | Tile 1 | Tile 2 | Tile 3
0 | 1 | 2 | 3 | 4 | 5 | 6 | 7 | 8 | 9 | 10 | 11 | 12 | 13 | 14 | 15

+32

+48

Tileset
pixels

+64

+80

+96

+112

Tile 4 | Tile 5 | Tile 6 | Tile 7

Each pixel row of the tileset is stored as a packed array of pixels in memory, and the next row follows. Note that all tiles must be the same size, and have the same pixel format.
The complete background image is assembled from these tiles. The arrangement is specified the tilemap: a grid of numbers, each naming a tile from the tileset. For each pixel on the screen, the tilemap tells the PPU which tile should be at that location, and the corresponding tile image in the tileset tells the PPU the colour of each pixel in that screen tile. This is shown in figure 18.

Figure 18: Example PPU tilemap

0 | 1 | 4 | 5 | 0 | 1
2 | 3 | 6 | 7 | 2 | 3

The screen origin is offset into the background by configuring the horizontal and vertical scroll. This allows the game view to move smoothly over a fixed background. If the screen area overhangs the background, coordinates are wrapped.
In total, a background is defined by:
| Width and height, measured in pixels
| Horizontal and vertical scroll, measured in pixels
| Tileset:
| – Tile pixel format – Tile size in pixels (power of two) – Tileset width in pixels (power of two) – Pointer to the tileset image (aligned to row size in bytes)
| Tilemap:
| – Pointer to the tilemap buffer

This tilemapping process allows detailed images to be displayed with a minimal memory footprint, compared with a framebuffer, which must store the colour of every single pixel on the screen.

## 4 Audio Processing Unit (APU)

Note: this section is even less complete than the others
The APU is a lightweight processing core, designed to synthesise polyphonic audio, stream PCM or ADPCM audio from the system, or a mixture of the two, whilst blending/panning the audio channels. It runs in hard real time: each audio sample is calculated in one sample period, so no data buffering is required between APU and DACs. The design goals are:
1. Low resource utilisation ( 100 LUTs for the processing core)
2. Output 48 kSa/s 8-bit stereo audio with a 12 MHz clock
3. Provide similar interface to an 8-bit era games console with default APU code, so no programming required
4. Streaming PCM audio from the system should be trivial (ring buffer + IRQ)
5. Be fun to program: very focused on a single task, so quirky but easy to learn

Architectural Overview

Memory Architecture

The APU is designed around a pair of iCE40 block RAMs: each is 16 bits wide by 256 entries deep, and has an independent read port and write port. The architecture and microarchitecture are designed around these parameters, for efficient use of the memory, and in particular for high utilisation of the memory ports. Figure ?? shows this in overview.

Figure 19: Audio processing unit memory architecture

| IMEM:

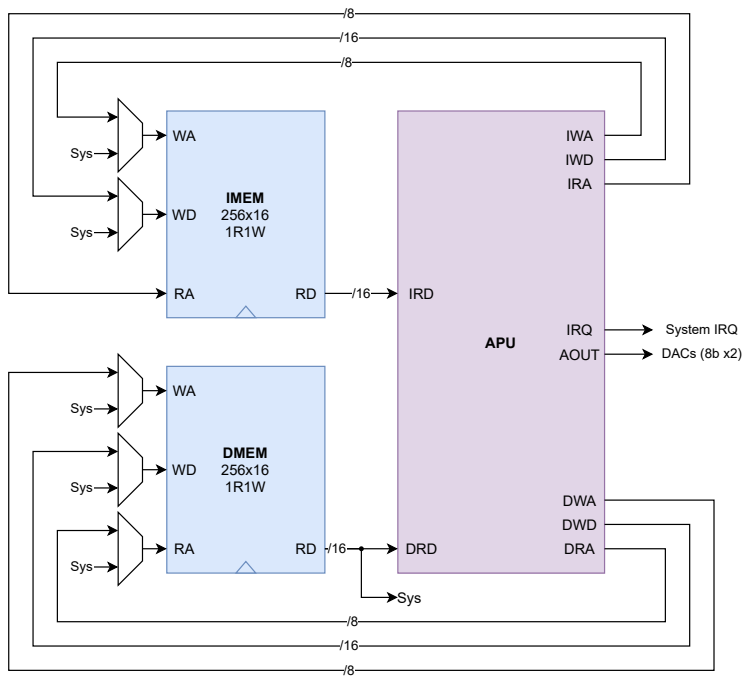
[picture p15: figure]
IMEM 256x16 1R1W; Sys; DMEM 256x16 1R1W; APU; IWA IWD IRA; IRD; DWA; AOUT; DACs (8b x2); IRQ; System IRQ; DWD; DRD; DRA

| – Contains the APU program instructions. Each instruction is 16 bits in size.
| – Upper 8 slots contain a copy of the APU’s general purpose registers

– The system has write-only access when the APU is halted, and no access when the APU is running

DMEM:

– Contains sample ring buffers used for wave tables or for buffering PCM data from the system

– Contains program temporary variables that don’t fit into registers or need to be indexed

– Upper 8 slots contain a copy of the APU’s general purpose registers
– The system has read-write access at all times, at a lower priority than the APU (system access stalls when the APU is accessing DMEM)

8 general-purpose registers are available to APU programs. The register contents are mirrored across IMEM and DMEM, so that two independent register reads can take place simultaneously. Register writeback of one instruction is overlapped with instruction fetch of the next instruction. A typical register-to-register instruction (e.g. an add) executes in two cycles, performs 3 memory reads and 2 memory writes.

Arithmetic

There are two data types used by APU instructions:

| 16-bit integers
| Packed pairs of 8-bit integers (SIMD)

The former is useful for control variables and for phase accumulation of digital oscillators. The latter is used for SIMD processing of stereo sampling pairs. All 8-bit arithmetic is signed-saturating. 16-bit arithmetic can generally be either signed-saturating or normal modular arithmetic.

Input/Output

The APU performs all calculations necessary to produce a 2×8-bit stereo sample pair, then outputs this to the external DACs (probably some kind of sigma delta thing) with an out instruction. The APU then stalls until the end of the audio sample period, whereupon it begins calculating the next samples.
For PCM sample streaming, the APU accesses ring buffers in DMEM, in the same way that it access DMEM wavetables for local synthesis. The system tops up the ring buffers by writing to DMEM, triggered by APU interrupts.
The irq instruction can generate a system interrupt, which is mainly useful for half-empty or quarter-empty interrupts for PCM ring buffers.

### 4.1 Instruction Set

The two main instruction formats are: R format
04578101115
opcode | rd | rs

I format
078101115
opcode | rd | imm

Example Programs

Wave channel

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

### 4.1.1 Wave channel, controllable frequency

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

.dmem
s i n e :
f r e q :
. hword 0 x1234
phase :
. hword 0

### 4.1.2 Wave channel, controllable volume with decay

. imem
l o o p :
l d r1 , [# f r e q ] | ; Atomic update phase based on f r e q u e n c y
l l r0 , [# phase ]
addm16 r0 , r 1
s c r0 , [# phase ]
l d r2 , [# decay ] | ; Atomic update volume based on l i n e a r decay
l l r1 , [#volume ]
sub16 r1 , r 2
s c r1 , [#volume ]
ldw r0 , [ r0 , #s i n e ] | ; Look up wave t a b l e based on phase
movhl r1 , r 1 | ; D u pli c a t e upper by te o f volume
mul48 r0 , r 1 | ; M ul ti pl y each sample by 4 volume MSBs
out
b l o o p

.dmem
s i n e :
f r e q :
. hword 0 x1234

phase :
. hword 0
decay :
. hword 0 xabcd
volume :
. hword 0

### 4.1.3 Multiple wave channels
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

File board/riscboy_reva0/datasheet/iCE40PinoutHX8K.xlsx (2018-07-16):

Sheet: Pinout
iCE40 Pinout HX8K
Ball Function | Pin Type | Bank | (BG121) 121-Ball caBGA Ball Number | (CB132) 132-Ball csBGA Ball Number | (CM225) 225-Ball ucBGA Ball Number | (CT256) 256-Ball caBGA Ball Number
IOL_1A | DPIO | 3 | - | - | C2 | E4
IOL_1B | DPIO | 3 | - | - | B1 | B2
IOL_2A | DPIO | 3 | B1 | B1 | E4 | F5
IOL_2B | DPIO | 3 | B2 | C1 | D4 | B1
IOL_3A | DPIO | 3 | - | - | E3 | C1
IOL_3B | DPIO | 3 | - | - | C1 | C2
IOL_4A | DPIO | 3 | C4 | C3 | E5 | F4
IOL_4B | DPIO | 3 | C3 | D3 | D3 | D2
IOL_5A | DPIO | 3 | C2 | D1 | E6 | G5
IOL_5B | DPIO | 3 | C1 | E1 | D1 | D1
IOL_6A | DPIO | 3 | - | - | D2 | G4
IOL_6B | DPIO | 3 | - | - | E2 | E3
IOL_7A | DPIO | 3 | - | - | - | H5
IOL_7B | DPIO | 3 | - | - | - | E2
IOL_8A | DPIO | 3 | E1 | D4 | F5 | G3
IOL_8B | DPIO | 3 | D1 | E4 | F4 | F3
IOL_9A | DPIO | 3 | D2 | F4 | F3 | H3
IOL_9B | DPIO | 3 | D3 | F3 | F2 | F2
IOL_10A | DPIO | 3 | E2 | H4 | G2 | H6
IOL_10B | DPIO | 3 | E3 | G4 | F1 | F1
IOL_11A | DPIO | 3 | - | - | G3 | H4
IOL_11B | DPIO | 3 | - | - | G1 | G2
IOL_12A | DPIO | 3 | F1 | J3 | G5 | J4
IOL_12B | DPIO | 3 | F2 | J1 | H2 | H2
IOL_13A | DPIO | 3 | F4 | G3 | H6 | J5
IOL_13B_GBIN7 | GBIN | 3 | F3 | G1 | G4 | G1
IOL_14A_GBIN6 | GBIN | 3 | G1 | H1 | H5 | J3
IOL_14B | DPIO | 3 | G2 | H3 | H1 | H1
IOL_15A | DPIO | 3 | - | - | H3 | J2
IOL_15B | DPIO | 3 | - | - | J3 | J1
IOL_16A | DPIO | 3 | - | - | H4 | K1
IOL_16B | DPIO | 3 | - | - | J1 | K3
IOL_17A | DPIO | 3 | G3 | - | J5 | L4
IOL_17B | DPIO | 3 | H3 | - | J2 | L1
IOL_18A | DPIO | 3 | H1 | K3 | J4 | K4
IOL_18B | DPIO | 3 | H2 | K4 | K1 | M1
IOL_19A | DPIO | 3 | - | - | - | L6
IOL_19B | DPIO | 3 | - | - | - | L3
IOL_20A | DPIO | 3 | - | - | K3 | K5
IOL_20B | DPIO | 3 | - | - | L1 | M2
IOL_21A | DPIO | 3 | - | - | - | L7
IOL_21B | DPIO | 3 | - | - | - | N2
IOL_22A | DPIO | 3 | - | - | L3 | M6
IOL_22B | DPIO | 3 | - | - | M1 | M3
IOL_23A | DPIO | 3 | J1 | L1 | K5 | L5
IOL_23B | DPIO | 3 | K1 | M1 | M2 | N3
IOL_24A | DPIO | 3 | - | - | N2 | P1
IOL_24B | DPIO | 3 | - | - | M3 | M4
IOL_25A | DPIO | 3 | K2 | N1 | P1 | P2
IOL_25B | DPIO | 3 | J2 | P1 | K4 | M5
IOL_26A | DPIO | 3 | - | - | M4 | R1
IOL_26B | DPIO | 3 | - | - | L4 | N4
IOB_52 | PIO | 2 | - | - | N3 | N6
IOB_53 | PIO | 2 | - | - | P2 | T1
IOB_54 | PIO | 2 | - | - | N4 | P4
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

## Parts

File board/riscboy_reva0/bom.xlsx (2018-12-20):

Ref | Val | Type
C10 | 0.1u | C
C11 | 0.1u | C
C12 | 0.1u | C
C13 | 0.1u | C
C16 | 0.1u | C
C17 | 0.1u | C
C19 | 0.1u | C
C22 | 0.1u | C
C30 | 0.1u | C
C4 | 0.1u | C
C6 | 0.1u | C
C7 | 0.1u | C
C8 | 0.1u | C
C9 | 0.1u | C
C23 | 10u | C
C26 | 10u | C
C27 | 10u | C
C24 | 18p | C
C25 | 18p | C
C1 | 1u | C
C14 | 1u | C
C15 | 1u | C
C18 | 1u | C
C2 | 1u | C
C20 | 1u | C
C21 | 1u | C
C28 | 1u | C
C29 | 1u | C
C3 | 1u | C
C5 | 1u | C
D1 | LED | D
D2 | LED | D
J2 | Conn_01x06 | J
J4 | Conn_01x06 | J
J1 | Conn_01x12 | J
J3 | Micro_SD_Card_Det | J
L1 | 2u2 | L
L2 | 2u2 | L
P2 | CONN_01X02 | P
P4 | CONN_01X02 | P
P1 | ILI9341 | P
P3 | USB_OTG | P
Q1 | BSS816NW | Q
R7 | 10 | R
R8 | 10 | R
R14 | 220 | R
R2 | 220 | R
R3 | 220 | R
R4 | 220 | R
R5 | 220 | R
R10 | 680 | R
R11 | 680 | R
R13 | 680 | R
R15 | 680 | R
R6 | 680 | R
R18 | 100k | R
R19 | 100k | R
R20 | 100k | R
R1 | 10k | R
R12 | 10k | R
R9 | 10k | R
RN1 | 10k | R
RN2 | 10k | R
RN3 | 10k | R
RN4 | 10k | R
R17 | 450k | R
R16 | NF | R
SW1 | SWITCH_SPST | S
U4 | BQ21040 | U
U2 | DSC60XX | U
U3 | GS74116AGP/ | U
U1 | iCE40-HX8k-BG121 | U
U5 | NCP1532 | U
U6 | SAML22G18A | U

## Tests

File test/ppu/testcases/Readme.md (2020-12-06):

PPU Testcases
-------------

These testcases are run against a PPU cycle model generated from the PPU's Verilog source with [CXXRTL](https://tomverbeure.github.io/2020/08/08/CXXRTL-the-New-Yosys-Simulation-Backend.html), in a C++ testbench containing a memory and a virtual display output. Each testcase is one directory:

- Any files named `(addr).S` are assembled and appear in the testbench memory at address `(addr)`, where `(addr)` is a number of any base
- Any files named `sprite_(addr)_(format).png` (can be any image file extension) will be packed with pixel format `(format)` (any of argb1555, p8, p4, p1) and appear in the testbench memory at address `(addr)`.
- Files named `tile8_(addr)_(format).png` or `tile16_(addr)_(format).png` are treated similarly, except the pixels are packed as a tileset, rather than a single large image.
- Files named `asset_(addr).bin` (file extension unimportant) are copied directly into the program image, and appear in the testbench memory at address `(addr`)

The maximum program image size is 16 MiB. The testbench vectors the PPU command processor to address `0`, so generally each testcase directory will at least contain an assembly file called `0.S` containing the program entry point. For example, the `fill_with_branch` testcase consists of two files, one of them called `0.S`, and containing the following:

```
	clip 0, 319

loop1:
	fill 31, 0, 0
	sync
	push loop1
	popj ylt 80

loop2:
	fill 0, 31, 0
	sync
	push loop3
	popj yge 160
	push loop2
	popj

loop3:
	fill 0, 0, 31
	sync
	push loop3
	popj
```

The second file in the `fill_with_branch` directory is an image called `expected_output.png`. This is used to check testcase success, and one file with this name must appear in every testcase directory.

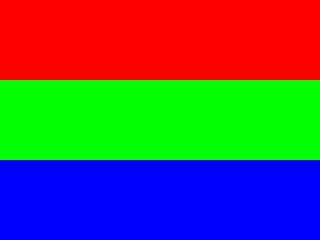
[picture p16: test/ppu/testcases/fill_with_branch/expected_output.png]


The program image is loaded into the C++ testbench and executed. The PPU's output is dumped to an image file, which is compared with the expected output. If the PPU fails to produce the required image, the test scripts create a file called `invalid_mask.png` in the test directory. For example, if the `y` comparisons were off by one, this would be the result:

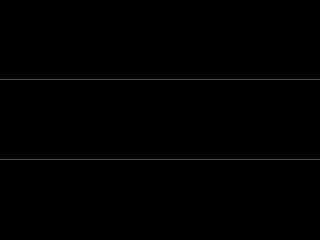
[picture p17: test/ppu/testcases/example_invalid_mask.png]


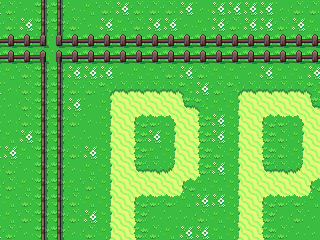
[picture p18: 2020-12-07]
test/ppu/testcases/tile_t16_pf1024_argb1555/expected_output.png

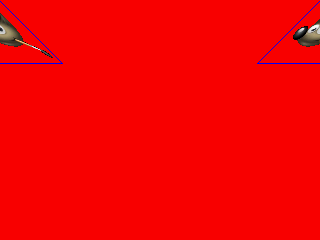
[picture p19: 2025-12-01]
test/ppu/testcases/blit_xedge_argb1555/expected_output.png

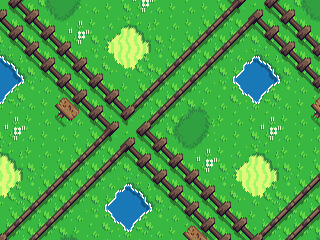
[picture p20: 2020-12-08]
test/ppu/testcases/atile_t16_pf128_argb1555/expected_output.png

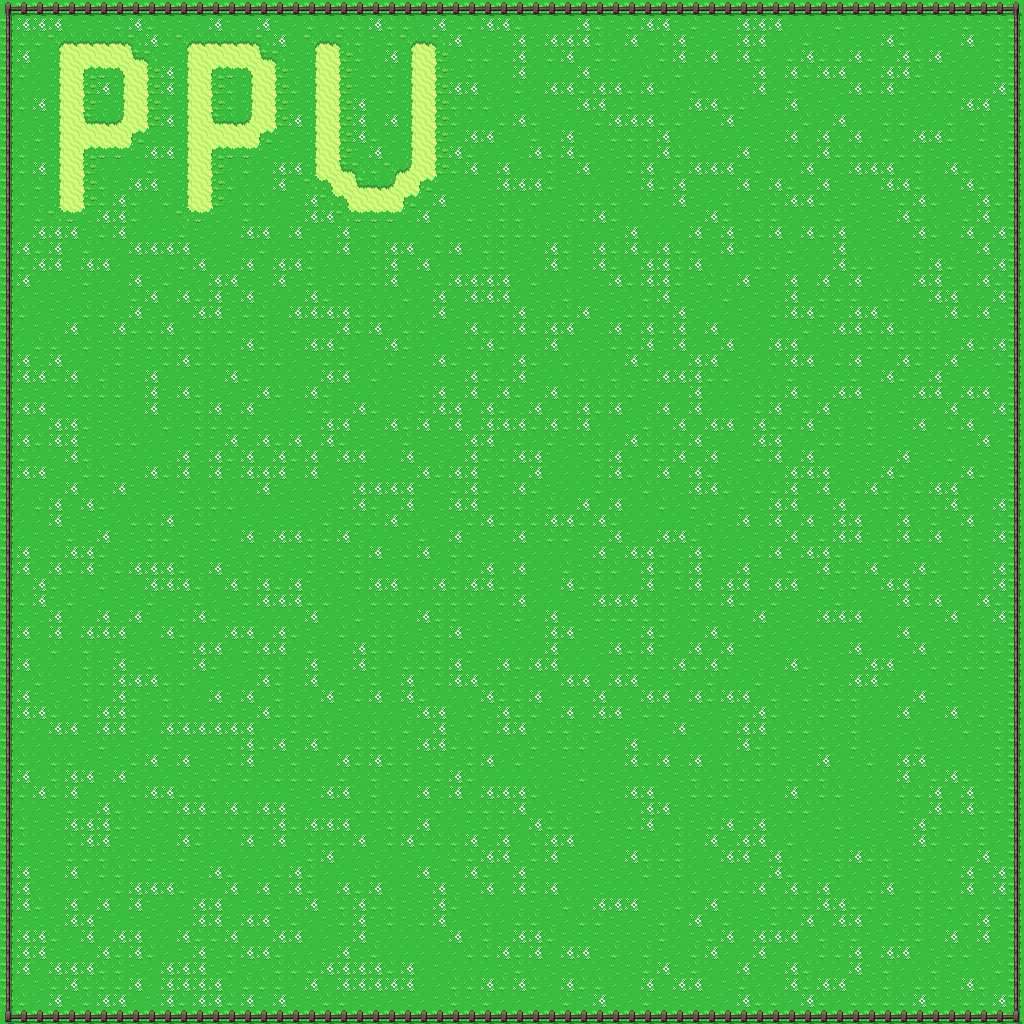
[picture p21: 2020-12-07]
test/ppu/testcases/tile_t16_pf1024_argb1555/1024x1024.png

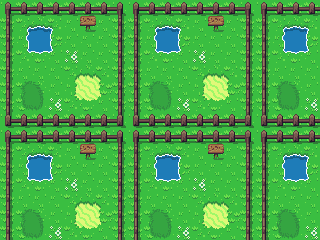
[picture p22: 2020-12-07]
test/ppu/testcases/tile_t16_pf128_argb1555/expected_output.png

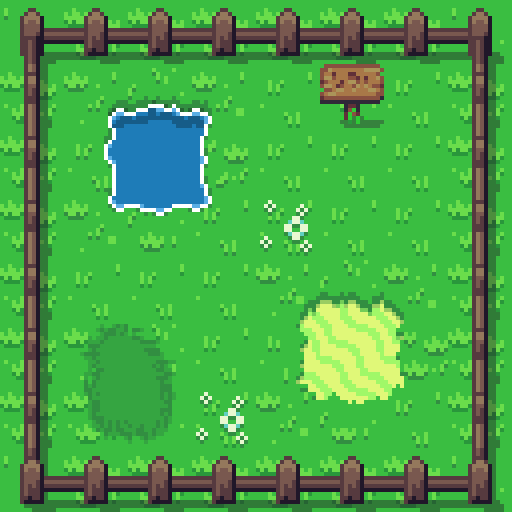
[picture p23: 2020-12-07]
test/ppu/testcases/atile_t16_pf128_argb1555/example_map_render.png

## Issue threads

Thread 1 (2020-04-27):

LLVM Scheduling Model!

lenary, 2020-04-27:
I think I threatened to make one of these a while ago on twitter… finally sat down and started one this weekend: https://reviews.llvm.org/D78910

I'm not sure I have the model entirely correct, and tbh improving instruction selection in the LLVM RISC-V backend will make a bigger difference than improving instruction scheduling, but I am interested to see if it helps at all.

I also know I don't have forwarding entirely correct yet, and probably some of the other latencies are incorrect too. I though I'd at least show you before it was finished and merged so you could have some input.

Wren6991, 2020-05-04:
Wow! This is far out of my wheelhouse, but at a first glance the parameters in that `.td` file look correct to me.

I'm not sure about this

```
  // RISCBoy has some funky instruction fetch fun
  let LoopMicroOpBufferSize = 2;
```

I do have a prefetch queue, mostly for timing reasons oddly enough, but it gets flushed on any branch, predicted or no. You just flush twice on a mispredict :)

I will do a pass over the processor documentation and make sure it is all strictly accurate, to save your from wasting time. In particular I think I am dropping the plugin idea.

Wren6991, 2020-05-04:
Load-use is indeed two cycles, but there is a load-to-store forward, so for that particular case (back-to-back load store) you don't pay the penalty cycle. This is mostly a waste of gates except perhaps for `memcpy`.

lenary, 2020-05-04:
Yeah, I'm not sure about the `LoopMicroOpBufferSize` which may just be for OoO cores.

There is a way to tell the scheduling model you have forwarding, I just haven't worked out exactly how to write it correctly.

lenary, 2020-05-12:
I haven't got around to updating this, but I see you've spun off a new repo for Hazard5 - should I rename the model to give the core that name instead?

Wren6991, 2020-05-12:
Yep, no rush -- I'm going to move the documentation over there too, and will do an update pass over it when I do that. I'll also add some friendlier test environment like a Verilator model so that people can run code against the core and get accurate cycle counts

Wren6991, 2020-05-12:
Yeah Hazard5 is the CPU, RISCBoy is the games console!

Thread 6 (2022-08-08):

No UART output on unsupported board

machdyne, 2022-08-08:
Hi. I've been trying to port RISCBoy to the [Riegel](https://github.com/machdyne/riegel) FPGA computer without much luck so far.

I'm wondering if this repo is still supposed to be in a working state as I had to change a reference from hazard5_cpu to hazard5_cpu_1port to get it to build.

With the nextpnr `--placer sa` option it seems to be hanging here:

```
nextpnr-ice40 -- Next Generation Place and Route (Version nextpnr-0.3-31-g997af6d7)
Info: Creating initial placement for remaining 4287 cells.
Info:   initial placement placed 500/4287 cells
Info:   initial placement placed 1000/4287 cells
Info:   initial placement placed 1500/4287 cells
Info:   initial placement placed 2000/4287 cells
Info:   initial placement placed 2500/4287 cells
```

Or maybe I'm not being patient enough. I was able to get it to build with the heap placer and blinky works but I'm not seeing anything on the UART. Unfortunately I don't have any of the supported boards to test this on. Any tips would be appreciated.

The fork with (non-working) Riegel support is here: https://github.com/machdyne/RISCBoy

Wren6991, 2023-06-12:
Yes I think this repo has suffered from the fact that the "tests" for libfpga live here, and I possibly bumped libfpga at some point without re-running the RISCBoy system-level tests. Let's see if I can find anything obvious.

Wren6991, 2023-06-12:
This should now be fixed by 77de506a. At least, I can now run the demos on my test platform, and couldn't before this commit.

machdyne, 2023-06-28:
Thanks. It's exciting to see activity on this project again.

I'm still not seeing any bootloader output to the UART so I'm probably doing something wrong. I'll keep testing your updates and debugging the issue because it would be great to have this working on [Riegel](https://github.com/machdyne/riegel), [Eis](https://github.com/machdyne/eis) and [Keks](https://github.com/machdyne/keks). In the meantime I'm keeping my [fork](https://github.com/machdyne/RISCBoy) up-to-date in case you'd like to have a look.

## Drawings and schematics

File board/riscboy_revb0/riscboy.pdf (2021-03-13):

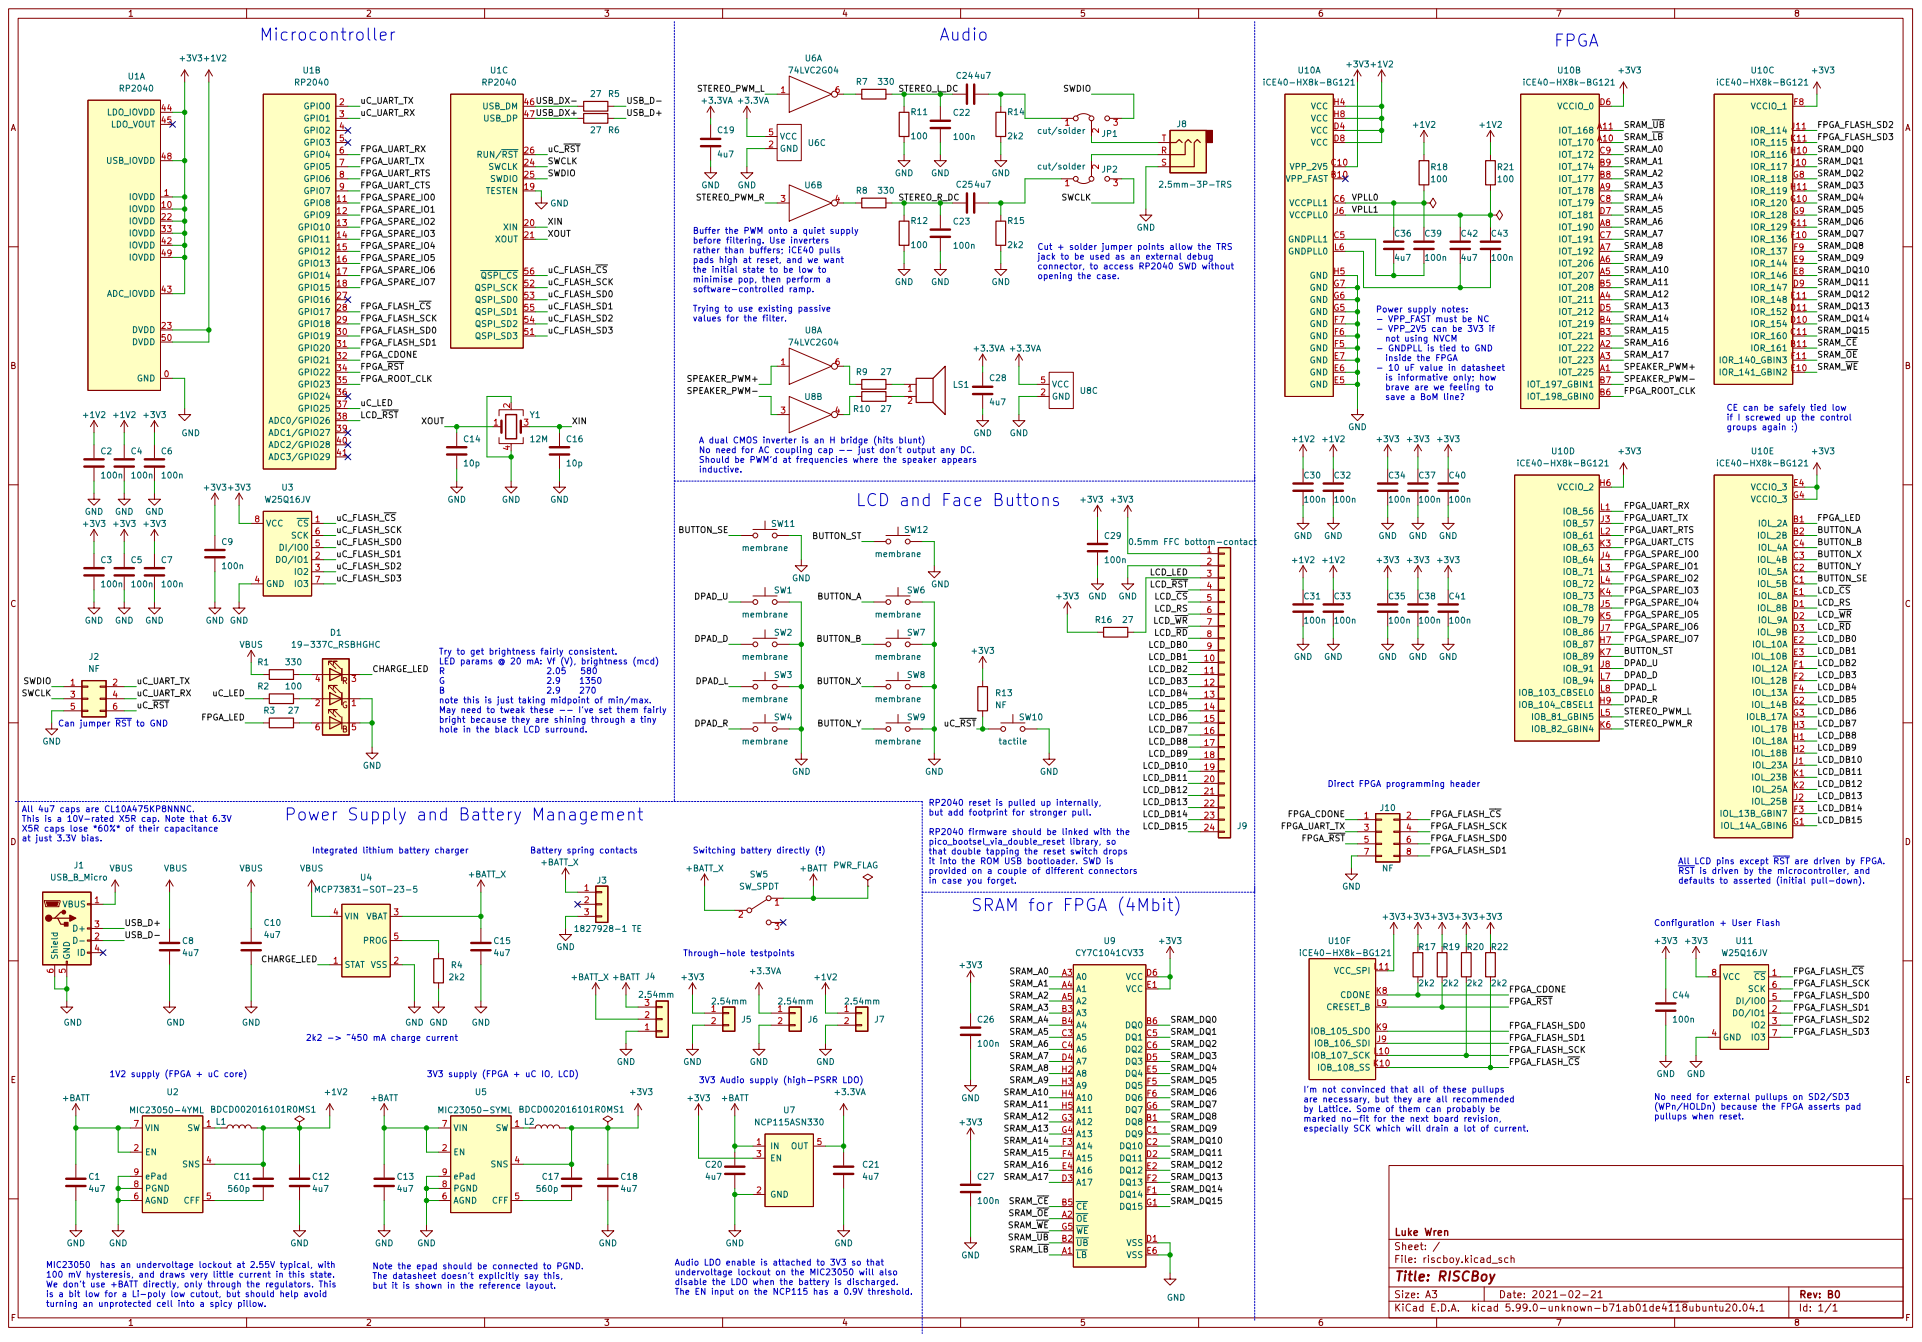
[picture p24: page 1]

Buffer the PWM onto a quiet supply
before filtering. Use inverters
rather than buffers; iCE40 pulls
pads high at reset, and we want
the initial state to be low to minimise pop, then perform a
R10 27 GND

Cut + solder jumper points allow the TRS
jack to be used as an external debug
connector, to access RP2040 SWD without opening the case.

values for the filter. Power Supply and Battery Management

Trying to use existing passive
inductive. Battery spring contacts

Power supply notes: - VPP_FAST must be NC

- VPP_2V5 can be 3V3 if
not using NVCM
- GNDPLL is tied to GND
inside the FPGA
- 10 uF value in datasheet
is informative only; how
brave are we feeling to
save a BoM line?

0.5mm FFC bottom-contact GND

CE can be safely tied low
if I screwed up the control
groups again :)

A dual CMOS inverter is an H bridge (hits blunt)
No need for AC coupling cap -- just don't output any DC.
Should be PWM'd at frequencies where the speaker appears

LCD and Face Buttons

100n GND GND GND GND

Try to get brightness fairly consistent.

Can jumper ~RST~ to GND

note this is just taking midpoint of min/max.
May need to tweak these -- I've set them fairly

Direct FPGA programming header

RP2040 reset is pulled up internally,
but add footprint for stronger pull. RP2040 firmware should be linked with the

All 4u7 caps are CL10A475KP8NNNC.
This is a 10V-rated X5R cap. Note that 6.3V
X5R caps lose *60%* of their capacitance
at just 3.3V bias.

pico_bootsel_via_double_reset library, so
that double tapping the reset switch drops
it into the ROM USB bootloader. SWD is provided on a couple of different connectors

Integrated lithium battery charger

All LCD pins except ~RST~ are driven by FPGA.
~RST~ is driven by the microcontroller, and
defaults to asserted (initial pull-down).

in case you forget.

1V2 supply (FPGA + uC core)

3V3 supply (FPGA + uC IO, LCD)

3V3 Audio supply (high-PSRR LDO)
+BATT

I'm not convinced that all of these pullups
are necessary, but they are all recommended
by Lattice. Some of them can probably be marked no-fit for the next board revision, especially SCK which will drain a lot of current.

(WPn/HOLDn) because the FPGA asserts pad
pullups when reset.

File: riscboy.kicad_sch Sheet: / Luke Wren

MIC23050 has an undervoltage lockout at 2.55V typical, with
100 mV hysteresis, and draws very little current in this state.
We don't use +BATT directly, only through the regulators. This
is a bit low for a Li-poly low cutout, but should help avoid
turning an unprotected cell into a spicy pillow.

Note the epad should be connected to PGND.
The datasheet doesn't explicitly say this,
but it is shown in the reference layout.

disable the LDO when the battery is discharged.
The EN input on the NCP115 has a 0.9V threshold.

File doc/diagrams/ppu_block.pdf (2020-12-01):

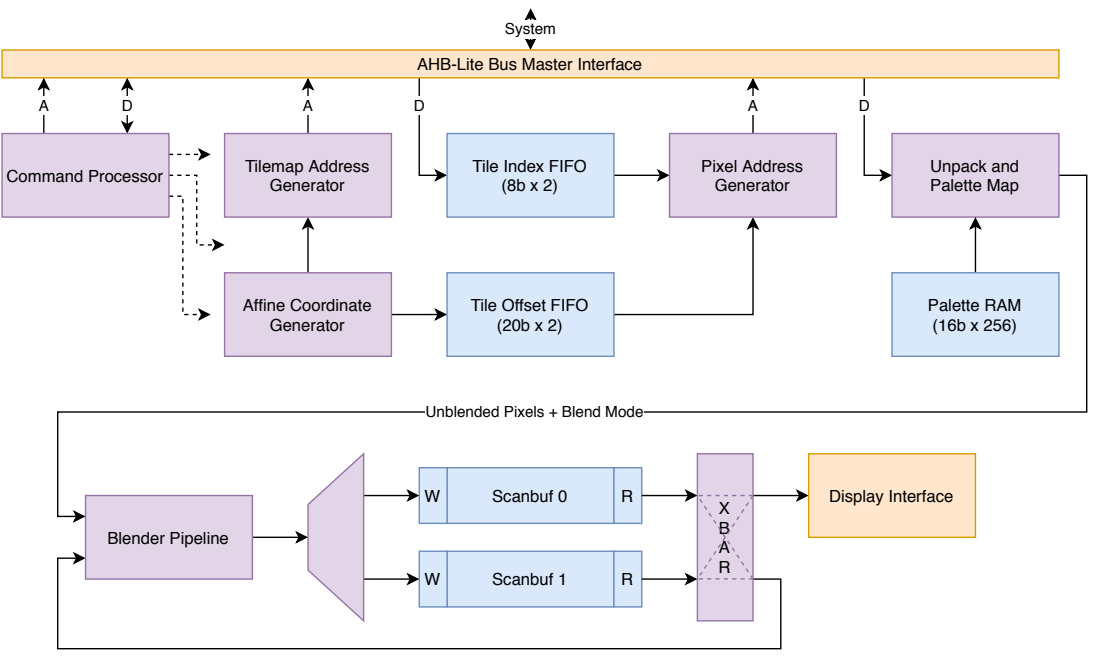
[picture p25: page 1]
Scanbuf 0; Scanbuf 1; Blender Pipeline; Unpack and Palette Map; Affine Coordinate Generator; Tilemap Address Generator; Pixel Address Generator; System; Command Processor; Display Interface; Palette RAM (16b x 256)

AHB-Lite Bus Master Interface

Tile Index FIFO

Tile Offset FIFO

Unblended Pixels + Blend Mode

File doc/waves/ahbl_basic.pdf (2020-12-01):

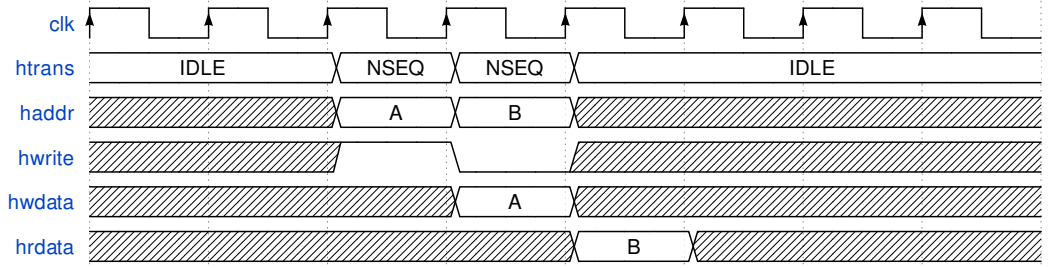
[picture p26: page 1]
clk; htrans; IDLE; NSEQ; haddr; hwrite; hwdata; hrdata

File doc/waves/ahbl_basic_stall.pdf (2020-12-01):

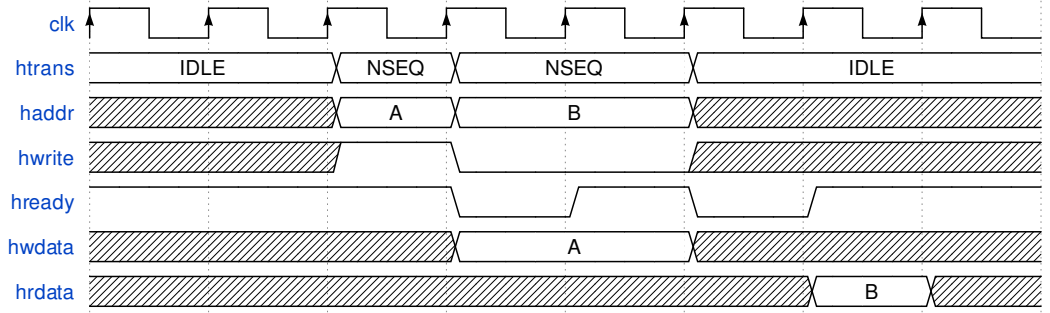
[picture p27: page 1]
clk; htrans; IDLE; NSEQ; haddr; hwrite; hready; hwdata; hrdata

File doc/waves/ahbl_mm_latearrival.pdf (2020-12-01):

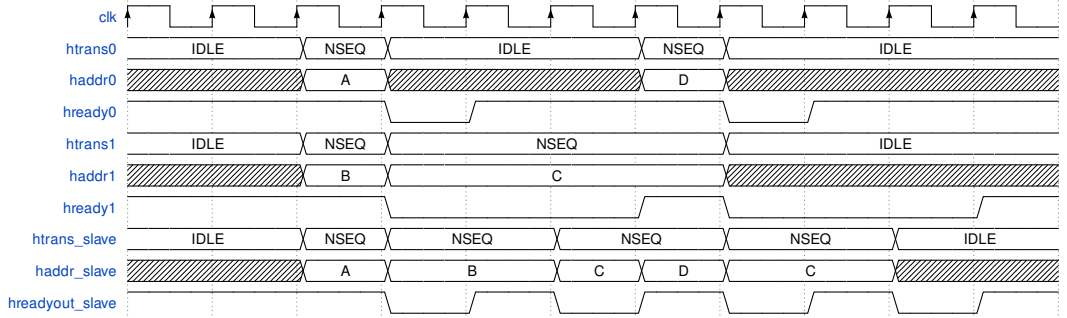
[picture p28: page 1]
clk; htrans0; IDLE; NSEQ; haddr0; hready0; htrans1; haddr1; hready1; htrans_slave; haddr_slave; hreadyout_slave

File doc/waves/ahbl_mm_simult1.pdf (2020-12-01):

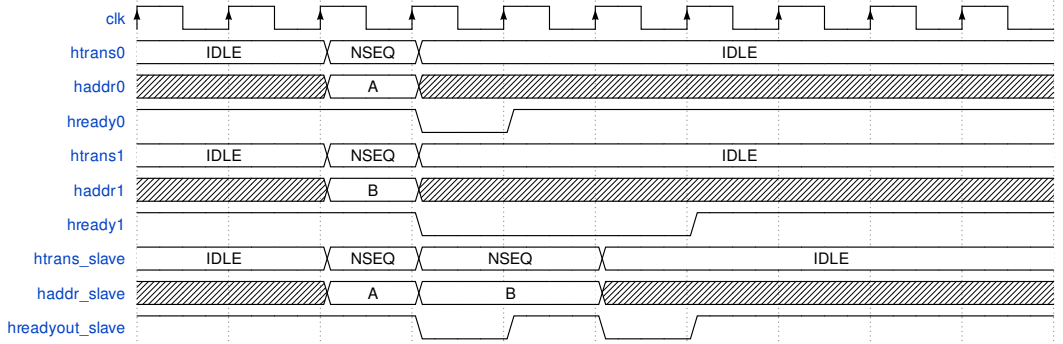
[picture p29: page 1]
clk; htrans0; IDLE; NSEQ; haddr0; hready0; htrans1; haddr1; hready1; htrans_slave; haddr_slave; hreadyout_slave

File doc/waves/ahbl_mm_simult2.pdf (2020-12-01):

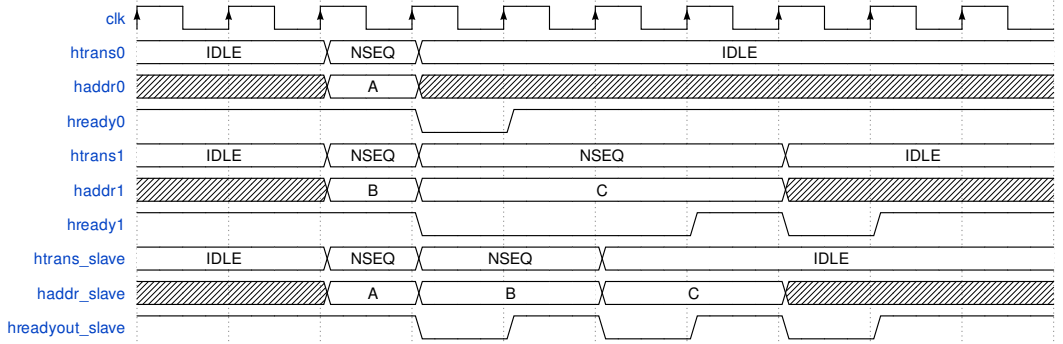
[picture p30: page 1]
clk; htrans0; IDLE; NSEQ; haddr0; hready0; htrans1; haddr1; hready1; htrans_slave; haddr_slave; hreadyout_slave

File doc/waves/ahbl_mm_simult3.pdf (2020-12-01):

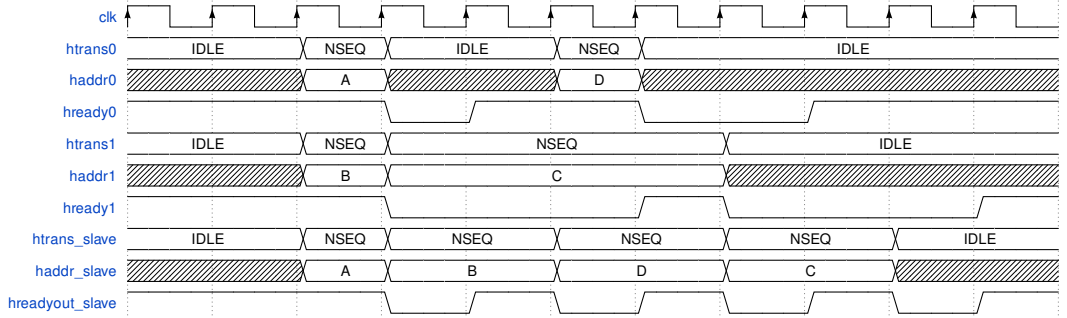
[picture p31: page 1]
clk; htrans0; IDLE; NSEQ; haddr0; hready0; htrans1; haddr1; hready1; htrans_slave; haddr_slave; hreadyout_slave

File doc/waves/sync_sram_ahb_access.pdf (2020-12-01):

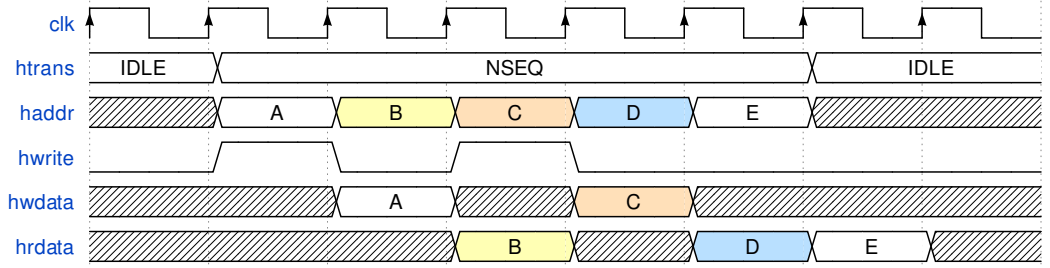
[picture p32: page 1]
clk; htrans; IDLE; NSEQ; haddr; hwrite; hwdata; hrdata

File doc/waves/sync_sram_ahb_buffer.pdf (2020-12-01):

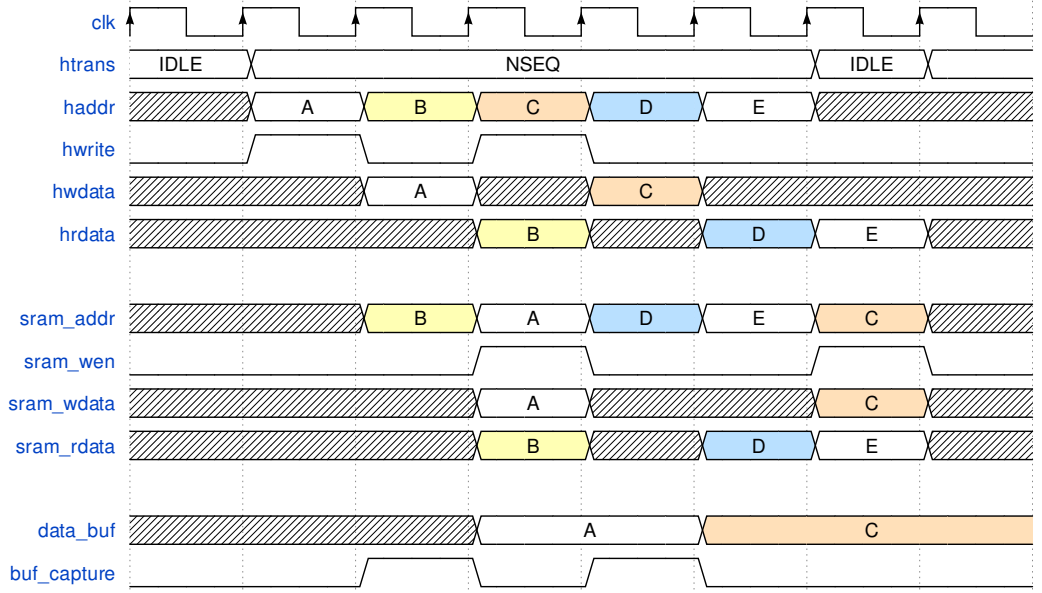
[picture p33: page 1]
clk; htrans; IDLE; NSEQ; haddr; hwrite; hwdata; hrdata; sram_addr; sram_wen; sram_wdata; sram_rdata; data_buf; buf_capture

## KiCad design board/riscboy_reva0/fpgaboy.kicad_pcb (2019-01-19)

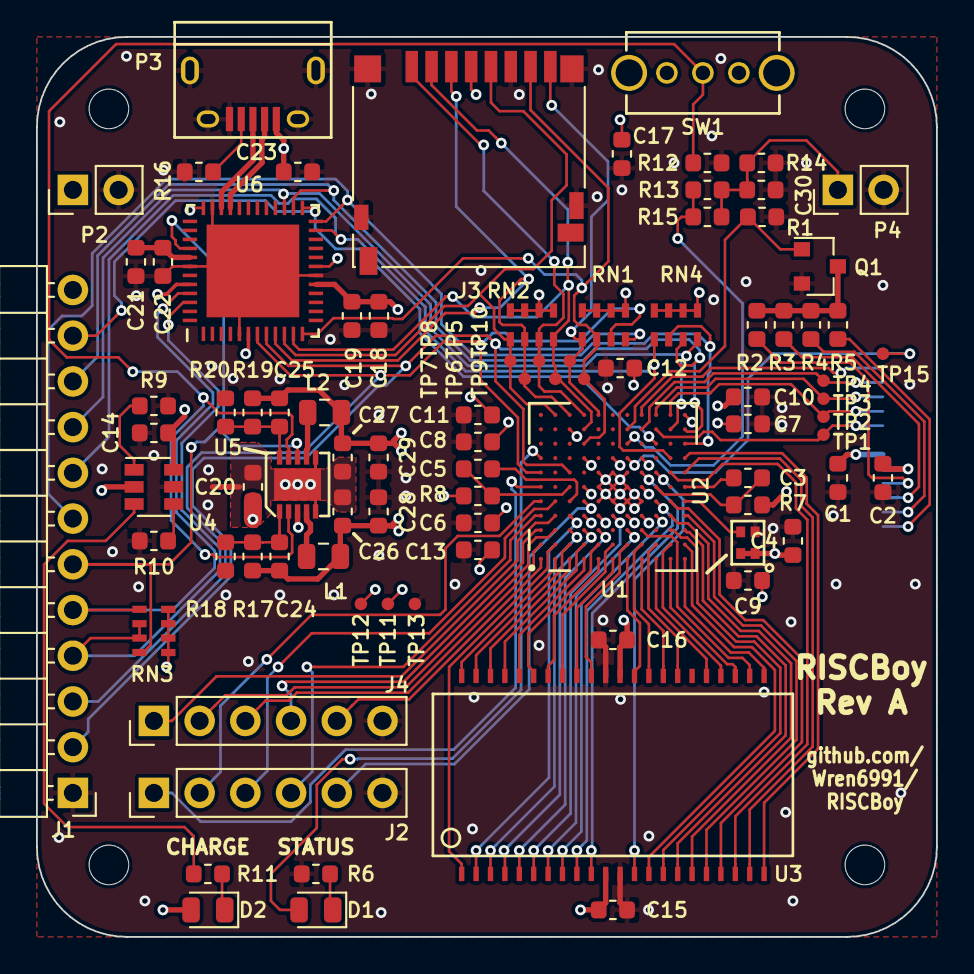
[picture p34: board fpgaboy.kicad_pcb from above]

Board: 4 copper layers, 50.0 x 50.0 mm, 89 parts (1 on the bottom side), 105 nets.

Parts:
C1, C2, C3, C5, C14, C15, C18, C20, C21, C28, C29: 1u; C_0603_1608Metric
C4, C6, C7, C8, C9, C10, C11, C12, C13, C16, C17, C19, C22, C30: 0.1u; C_0603_1608Metric
C23, C26, C27: 10u; C_0603_1608Metric
C24, C25: 18p; C_0603_1608Metric
D1, D2: LED; LED_0805_2012Metric
J1: Conn_01x12; PinHeader_1x12_P2.54mm_Horizontal
J2, J4: Conn_01x06; PinHeader_1x06_P2.54mm_Vertical
J3: Micro_SD_Card_Det; microSD_HC_Hirose_DM3D-SF
L1, L2: 2u2; R_0805_2012Metric
P1: ILI9341; FFC_18_0.8mm_solder
P2, P4: CONN_01X02; PinHeader_1x02_P2.54mm_Vertical
P3: USB_OTG; USB_Micro-B
Q1: BSS816NW; SOT-23
R1, R9, R12: 10k; R_0603_1608Metric
R2, R3, R4, R5, R14: 220; R_0603_1608Metric
R6, R10, R11, R13, R15: 680; R_0603_1608Metric
R7, R8: 10; R_0603_1608Metric
R16: NF; R_0603_1608Metric
R17: 450k; R_0603_1608Metric
R18, R19, R20: 100k; R_0603_1608Metric
RN1, RN2, RN3, RN4: 10k; RN4-1206
SW1: SWITCH_SPST; SPDT_SLIDE_SWITCH
TP1, TP2, TP3, TP4, TP5, TP6, TP7, TP8, TP9, TP10, TP11, TP12, TP13, TP15: TestPoint; Testpoint_d0.7mm
TP14: Tie_point; tiepoint-0.5
U1: iCE40-HX8k-BG121; BGA-121_11x11_9.0x9.0mm
U2: DSC60XX; LGA4_1.6x1.2mm
U3: GS74116AGP/; TSOP_II_44
U4: BQ21040; SOT-23-6
U5: NCP1532; UDFN-10
U6: SAML22G18A; QFN-48_EP_7x7_Pitch0.5mm

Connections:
+1V2: C7.1, C9.1, C11.1, C13.1, C25.1, C27.1, C29.1, L2.2, R7.2, R8.2, R19.1, TP11.1, U1.D4, U1.D8, U1.H4, U1.H8
+3V3: C1.1, C4.1, C6.1, C8.1, C10.1, C12.1, C15.1, C16.1, C17.1, C18.1, C19.1, C24.1, C26.1, C28.1, J3.4, L1.2, P1.9, R17.1, RN1.5, RN1.6, RN1.7, RN1.8, RN2.5, RN2.6, RN2.7, RN2.8, RN3.5, RN3.6, RN3.7, RN3.8, RN4.5, RN4.6, RN4.7, RN4.8, TP12.1, U1.C10, U1.D6, U1.E4, U1.F8, U1.G4, U1.H6, U1.L11, U2.1, U2.4, U3.11, U3.33, U6.6, U6.17, U6.19, U6.36, U6.44
+5V: C14.1, C23.1, P3.1, U4.6
+BATT: C2.1, C20.1, D2.2, J1.12, P1.10, P2.1, SW1.1, U4.2, U5.3
/AUDIO_PWM: R13.1, R15.1, U1.G9
/CHARGE: R11.2, U4.3
/CLK_OSC: U1.L5, U2.3
/FPGA_CFG_DONE: J1.8, RN4.1, U1.K8, U6.23
/FPGA_CFG_SCK: J1.10, RN4.3, U1.L10, U6.26
/FPGA_CFG_SI: J1.11, U1.J9, U6.25
/FPGA_CFG_~RST: J1.7, RN4.2, U1.L9, U6.24
/FPGA_CFG_~SS: J1.9, RN4.4, U1.K10, U6.27
/FPGA_HEARTBEAT: D1.2, U1.A8
/FPGA_UART_RX: J1.2, RN1.4, U1.C7, U6.8
/FPGA_UART_TX: J1.3, RN1.3, U1.A7, U6.7
/GPIO_SW0: J2.1, U1.A6
/GPIO_SW1: J2.2, U1.A5
/GPIO_SW2: J2.3, U1.B5
/GPIO_SW3: J2.4, U1.A4
/GPIO_SW4: J2.5, U1.D5
/GPIO_SW5: J4.1, U1.B4
/GPIO_SW6: J4.2, U1.B3
/GPIO_SW7: J4.3, U1.A2
/GPIO_SW8: J4.4, U1.A3
/GPIO_SW9: J4.5, U1.A1
/LCD_CS: P1.5, TP3.1, U1.J11
/LCD_D~C~: P1.6, TP2.1, U1.K11
/LCD_PWM: Q1.1, R1.1, U1.G10
/LCD_RESET: P1.2, TP15.1, U1.G8
/LCD_SCL: P1.7, TP1.1, U1.J10
/LCD_SDA: P1.4, TP4.1, U1.H10
/LCD_SDO: P1.3, U1.H11
/SRAM_A0: U1.E3, U3.5
/SRAM_A1: U1.D3, U3.4
/SRAM_A2: U1.C3, U3.3
/SRAM_A3: U1.C4, U3.2
/SRAM_A4: U1.B2, U3.1
/SRAM_A5: U1.B1, U3.44
/SRAM_A6: U1.C2, U3.43
/SRAM_A7: U1.C1, U3.42
/SRAM_A8: U1.J1, U3.27
/SRAM_A9: U1.K2, U3.26
/SRAM_A10: U1.K1, U3.25
/SRAM_A11: U1.H3, U3.24
/SRAM_A12: U1.L7, U3.21
/SRAM_A13: U1.K7, U3.20
/SRAM_A14: U1.K5, U3.19
/SRAM_A15: U1.L4, U3.18
/SRAM_A16: U1.L8, U3.22
/SRAM_A17: U1.L1, U3.23
/SRAM_DQ1: U1.G3, U3.7
/SRAM_DQ2: U1.J4, U3.8
/SRAM_DQ3: U1.J5, U3.9
/SRAM_DQ4: U1.H7, U3.10
/SRAM_DQ5: U1.J7, U3.13
/SRAM_DQ6: U1.L2, U3.14
/SRAM_DQ7: U1.K3, U3.15
/SRAM_DQ8: U1.L3, U3.16
/SRAM_DQ9: U1.J2, U3.29
/SRAM_DQ10: U1.H1, U3.30
/SRAM_DQ11: U1.H2, U3.31
/SRAM_DQ12: U1.G1, U3.32
/SRAM_DQ13: U1.G2, U3.35
/SRAM_DQ14: U1.F1, U3.36
/SRAM_DQ15: U1.F2, U3.37
/SRAM_DQ16: U1.E1, U3.38
/SRAM_~CE: U1.F4, U3.6
/SRAM_~LB: U1.E2, U3.39
/SRAM_~OE: U1.D2, U3.41
/SRAM_~UB: U1.D1, U3.40
/SRAM_~WE: U1.K4, U3.17
/USB_DM: P3.2, U6.33
/USB_DP: P3.3, U6.34
/VCCPLL0: C3.1, R7.1, U1.J6
/VCCPLL1: C5.1, R8.1, U1.C6
/VDDCORE: C21.1, C22.1, U6.41
/uC_SWCLK: J1.5, RN3.1, U6.45
/uC_SWD: J1.4, RN3.2, RN3.3, U6.46
/uC_~RST: J1.6, RN3.4, U5.8, U6.40
/uSD_CLK: J3.5, RN2.1, TP8.1, U1.B11, U6.10
/uSD_CMD: J3.3, RN2.2, TP7.1, U1.C11, U6.9
/uSD_DAT0: J3.7, RN1.2, TP9.1, U1.D9, U6.12
/uSD_DAT1: J3.8, RN1.1, TP10.1, U1.E11
/uSD_DAT2: J3.1, RN2.3, TP5.1, U1.D11
/uSD_DAT3: J3.2, RN2.4, TP6.1, U1.D10, U6.11
GND: C1.2, C2.2, C4.2, C6.2, C7.2, C8.2, C9.2, C10.2, C11.2, C12.2, C13.2, C14.2, C15.2, C16.2, C17.2, C18.2, C19.2, C21.2, C22.2, C23.2, C28.2, C29.2, C30.2, J1.1, J2.6, J3.6, J3.11, J4.6, P1.1, P1.8, P2.2, P3.5, P3.6, P4.2, Q1.2, R1.2, R6.2, R9.2, R10.2, R12.2, R14.2, R16.2, R18.2, R20.2, TP13.1, TP14.1, U1.E5, U1.E6, U1.E7, U1.F5, U1.F6, U1.F7, U1.G5, U1.G6, U1.G7, U1.H5, U2.2, U3.12, U3.34, U4.5, U6.5, U6.18, U6.35, U6.42, U6.49
GNDPWR: C20.2, C26.2, C27.2, TP14.2, U5.5, U5.6
unnamed: C3.2, U1.L6
unnamed: C5.2, U1.C5
unnamed: C24.2, R17.2, R18.1, U5.1
unnamed: C25.2, R19.2, R20.1, U5.10
unnamed: C30.1, P4.1, R13.2, R14.1, R15.2
unnamed: D1.1, R6.1
unnamed: D2.1, R11.1
unnamed: L1.1, U5.4
unnamed: L2.1, U5.7
unnamed: P1.11, R2.1
unnamed: P1.12, R3.1
unnamed: P1.13, R4.1
unnamed: P1.14, R5.1
unnamed: P3.4, R16.1
unnamed: Q1.3, R2.2, R3.2, R4.2, R5.2
unnamed: R9.1, U4.1
unnamed: R10.1, U4.4
unnamed: R12.1, SW1.2, U5.2, U5.9

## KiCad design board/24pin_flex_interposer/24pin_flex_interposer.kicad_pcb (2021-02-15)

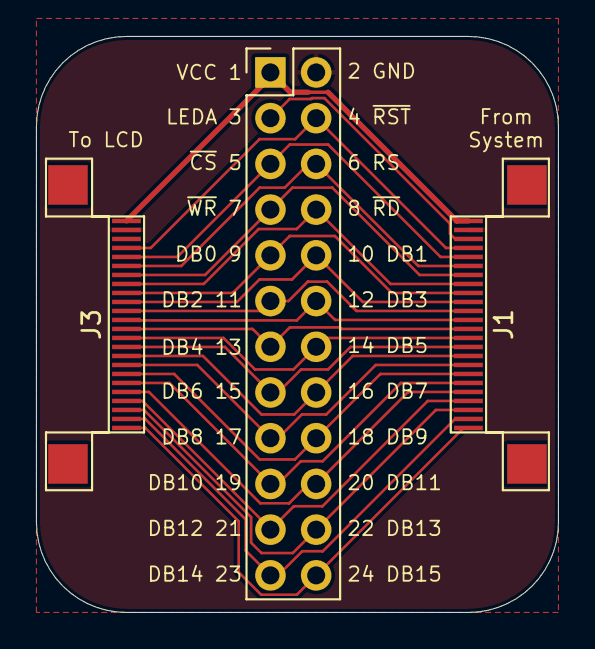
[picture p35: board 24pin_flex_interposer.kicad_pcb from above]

Board: 2 copper layers, 29.0 x 32.0 mm, 3 parts (0 on the bottom side), 24 nets.

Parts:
J1, J3: TF31-24S-0.5SH; FPC_24
J2: Conn_02x12_Odd_Even; PinHeader_2x12_P2.54mm_Vertical

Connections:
/LCD1: J1.24, J2.1, J3.1
/LCD2: J1.23, J2.2, J3.2
/LCD3: J1.22, J2.3, J3.3
/LCD4: J1.21, J2.4, J3.4
/LCD5: J1.20, J2.5, J3.5
/LCD6: J1.19, J2.6, J3.6
/LCD7: J1.18, J2.7, J3.7
/LCD8: J1.17, J2.8, J3.8
/LCD9: J1.16, J2.9, J3.9
/LCD10: J1.15, J2.10, J3.10
/LCD11: J1.14, J2.11, J3.11
/LCD12: J1.13, J2.12, J3.12
/LCD13: J1.12, J2.13, J3.13
/LCD14: J1.11, J2.14, J3.14
/LCD15: J1.10, J2.15, J3.15
/LCD16: J1.9, J2.16, J3.16
/LCD17: J1.8, J2.17, J3.17
/LCD18: J1.7, J2.18, J3.18
/LCD19: J1.6, J2.19, J3.19
/LCD20: J1.5, J2.20, J3.20
/LCD21: J1.4, J2.21, J3.21
/LCD22: J1.3, J2.22, J3.22
/LCD23: J1.2, J2.23, J3.23
/LCD24: J1.1, J2.24, J3.24

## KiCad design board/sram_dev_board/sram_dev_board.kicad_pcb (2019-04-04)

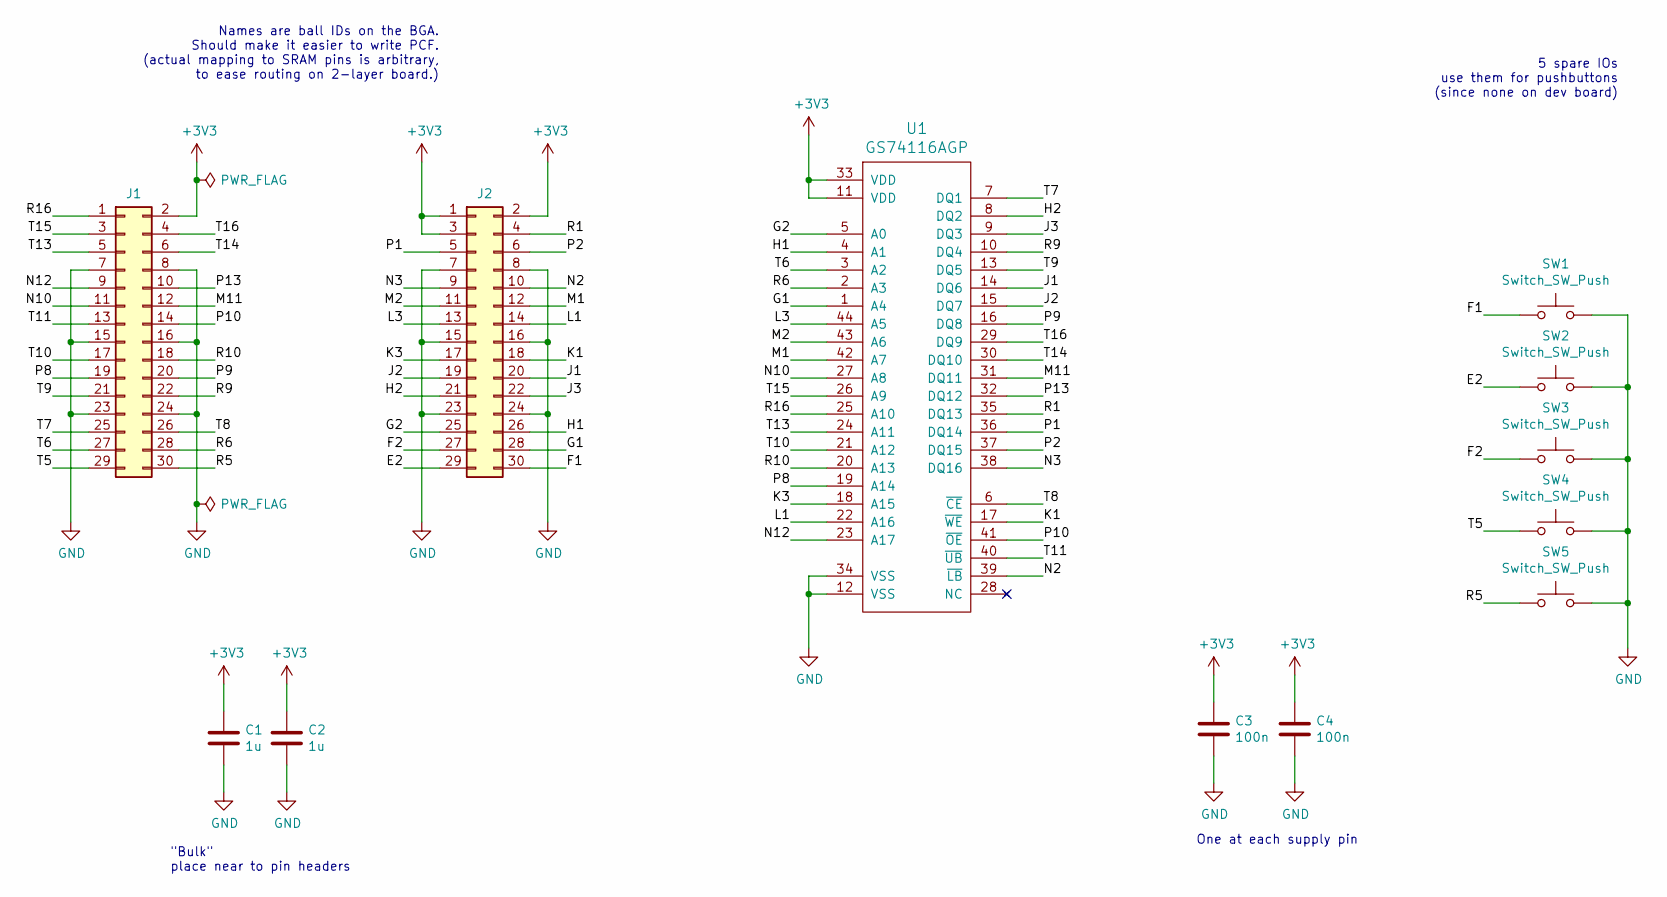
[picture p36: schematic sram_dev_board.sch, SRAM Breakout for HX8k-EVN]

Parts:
C1, C2: 1u; C_0603_1608Metric_Pad1.05x0.95mm_HandSolder
C3, C4: 100n; C_0603_1608Metric_Pad1.05x0.95mm_HandSolder
J1, J2: Conn_02x15_Odd_Even; PinHeader_2x15_P2.54mm_Vertical
SW1, SW2, SW3, SW4, SW5: Switch_SW_Push; SW_SPST_EVQP0
U1: GS74116AGP; TSOP_II_44

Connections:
+3V3: C1.1, C2.1, C3.1, C4.1, J1.2, J2.1, J2.2, J2.3, U1.11 (VDD), U1.33 (VDD)
/E2: J2.29, SW2.1
/F1: J2.30, SW1.1
/F2: J2.27, SW3.1
/G1: J2.28, U1.1 (A4)
/G2: J2.25, U1.5 (A0)
/H1: J2.26, U1.4 (A1)
/H2: J2.21, U1.8 (DQ2)
/J1: J2.20, U1.14 (DQ6)
/J2: J2.19, U1.15 (DQ7)
/J3: J2.22, U1.9 (DQ3)
/K1: J2.18, U1.17 (~WE)
/K3: J2.17, U1.18 (A15)
/L1: J2.14, U1.22 (A16)
/L3: J2.13, U1.44 (A5)
/M1: J2.12, U1.42 (A7)
/M2: J2.11, U1.43 (A6)
/M11: J1.12, U1.31 (DQ11)
/N2: J2.10, U1.39 (~LB)
/N3: J2.9, U1.38 (DQ16)
/N10: J1.11, U1.27 (A8)
/N12: J1.9, U1.23 (A17)
/P1: J2.5, U1.36 (DQ14)
/P2: J2.6, U1.37 (DQ15)
/P8: J1.19, U1.19 (A14)
/P9: J1.20, U1.16 (DQ8)
/P10: J1.14, U1.41 (~OE)
/P13: J1.10, U1.32 (DQ12)
/R1: J2.4, U1.35 (DQ13)
/R5: J1.30, SW5.1
/R6: J1.28, U1.2 (A3)
/R9: J1.22, U1.10 (DQ4)
/R10: J1.18, U1.20 (A13)
/R16: J1.1, U1.25 (A10)
/T5: J1.29, SW4.1
/T6: J1.27, U1.3 (A2)
/T7: J1.25, U1.7 (DQ1)
/T8: J1.26, U1.6 (~CE)
/T9: J1.21, U1.13 (DQ5)
/T10: J1.17, U1.21 (A12)
/T11: J1.13, U1.40 (~UB)
/T13: J1.5, U1.24 (A11)
/T14: J1.6, U1.30 (DQ10)
/T15: J1.3, U1.26 (A9)
/T16: J1.4, U1.29 (DQ9)
GND: C1.2, C2.2, C3.2, C4.2, J1.7, J1.8, J1.15, J1.16, J1.23, J1.24, J2.7, J2.8, J2.15, J2.16, J2.23, J2.24, SW1.2, SW2.2, SW3.2, SW4.2, SW5.2, U1.12 (VSS), U1.34 (VSS)

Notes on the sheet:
One at each supply pin
"Bulk" place near to pin headers
Names are ball IDs on the BGA. Should make it easier to write PCF. (actual mapping to SRAM pins is arbitrary, to ease routing on 2-layer board.)
5 spare IOs use them for pushbuttons (since none on dev board)

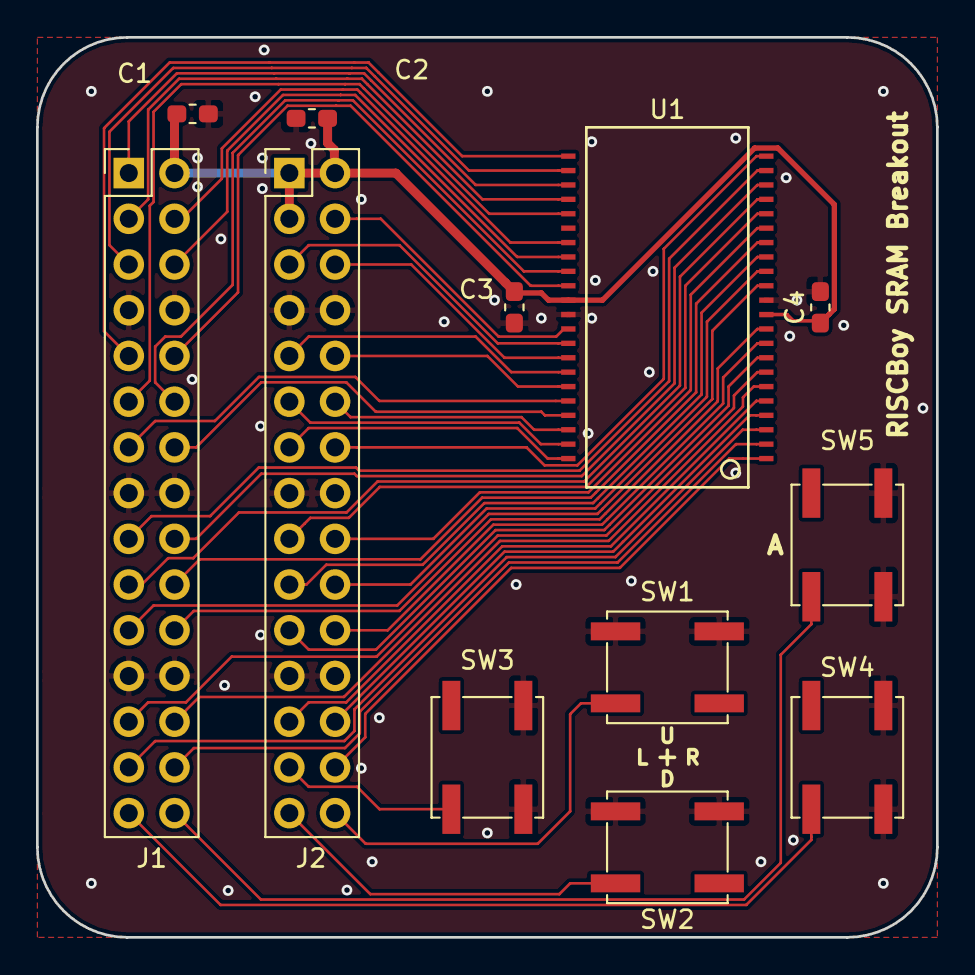
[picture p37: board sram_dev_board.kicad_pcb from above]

Board: 2 copper layers, 50.0 x 50.0 mm, 12 parts (0 on the bottom side), 46 nets.

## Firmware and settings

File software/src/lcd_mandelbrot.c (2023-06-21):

#include <stdint.h>
#include <stdbool.h>

#define CLK_SYS_MHZ 12
#include "gpio.h"
#include "spi_lcd.h"
#include "pwm.h"
#include "tb_cxxrtl_io.h"

static uint16_t palette[256];

#define WIDTH 320
#define HEIGHT 240
#define FIXPOINT 8
#define ESCAPE (3 << FIXPOINT)

int main()
{
	pwm_enable(false);
	pwm_invert(true);
	if (!tb_running_in_sim())
		spi_lcd_init(ili9341_init_seq);

	for (int i = 0; i < 256; ++i)
	{
		int j = i * 8;
		uint8_t r = 255 - j;
		uint8_t g = j < 128 ? j : 255 - j;
		uint8_t b = 0;
		palette[i] = (b >> 3) | ((g >> 2) << 5) | ((r >> 3) << 11);
	}

	// Output a test pattern and clear it, to check everything works
	if (!tb_running_in_sim())
	{
		spi_lcd_start_pixels();
		for (int y = 0; y < HEIGHT; ++y)
		{
			for (int x = 0; x < WIDTH; ++x)
			{
				spi_lcd_put_hword(0xffffu);
			}
		}
	}

	// This time it's for real
	spi_lcd_start_pixels();
	for (int y = 0; y < HEIGHT; ++y)
	{
		for (int x = 0; x < WIDTH; ++x)
		{
			int32_t cr = (x - WIDTH / 2 - 20) * 3;
			int32_t ci = (y - HEIGHT / 2) * 3;
			int32_t zr = cr;
			int32_t zi = ci;
			int i = 0;
			for (; i < 31; ++i)
			{
				int32_t zr_tmp = (((zr * zr) - (zi * zi)) >> FIXPOINT) + cr;
				zi = 2 * ((zr * zi) >> FIXPOINT) + ci;
				zr = zr_tmp;
				if (zi * zi + zr * zr > ESCAPE * ESCAPE)
					break;
			}
			uint16_t colour = palette[i];
			spi_lcd_put_hword(colour);
		}
	}
}

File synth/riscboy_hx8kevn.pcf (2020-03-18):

###############################################################################
# EVN board
###############################################################################

# LEDs
set_io led[0] B5
set_io led[1] B4
set_io led[2] A2
set_io led[3] A1
set_io led[4] C5
set_io led[5] C4
set_io led[6] B3
set_io led[7] C3

# To FT2233H UART:  (note the Lattice schematic shows TX/RX from FPGA pov, but CTS/RTS from FTDI pov! aaargh)
set_io uart_tx B12
set_io uart_rx B10
set_io uart_cts B13
set_io uart_rts A15

# Connect SPI master to configuration flash!
set_io flash_mosi P12
set_io flash_miso P11
set_io flash_sclk R11
set_io flash_cs R12

# 12 MHz oscillator
set_io clk_osc J3

# Connect LCD signals to some random IOs
set_io lcd_cs   B7
set_io lcd_dc   C7
set_io lcd_sclk B8
set_io lcd_mosi A7

###############################################################################
# Breakout board
###############################################################################

set_io dpad_u F1
set_io dpad_d E2
set_io dpad_l F2
set_io dpad_r T5
set_io btn_a R5

set_io sram_dq[0]  T7
set_io sram_dq[1]  H2

# See note on CE below
# set_io sram_dq[2]  J3
set_io sram_dq[2]  T8

set_io sram_dq[3]  R9
set_io sram_dq[4]  T9
set_io sram_dq[5]  J1
set_io sram_dq[6]  J2
set_io sram_dq[7]  P9
set_io sram_dq[8]  T16
set_io sram_dq[9]  T14
set_io sram_dq[10] M11
set_io sram_dq[11] P13
set_io sram_dq[12] R1
set_io sram_dq[13] P1
set_io sram_dq[14] P2
set_io sram_dq[15] N3

# NB: addr[0] and addr[15] have been pinswapped!
# Due to combination of:
# - addr[15] was constrained into the same tile as WE
# - clock enable is global to tile, i.e. shared between two IOs
# - addr[15] has a clock enable, WE doesn't
# - nextpnr silently just drives clock enable into both (fatal, and a nightmare to debug)
#
# (HACK) solution was to drive addr[0] clock enable to 1'b1 (which is safe/ok) and swap
# this one to be next to WEn.
# The SRAM doesn't care about address bit order; just needs to be an invertible mapping
# into processor address space.

set_io sram_addr[0]  K3 # G2
set_io sram_addr[1]  H1
set_io sram_addr[2]  T6
set_io sram_addr[3]  R6
set_io sram_addr[4]  G1
set_io sram_addr[5]  L3
set_io sram_addr[6]  M2
set_io sram_addr[7]  M1
set_io sram_addr[8]  N10
set_io sram_addr[9]  T15
set_io sram_addr[10] R16
set_io sram_addr[11] T13
set_io sram_addr[12] T10
set_io sram_addr[13] R10
set_io sram_addr[14] P8
set_io sram_addr[15] G2 # K3
set_io sram_addr[16] L1
set_io sram_addr[17] N12

# CE was tied to ground to free up an IO to drive DQ2.
# DQ2 was supposed to be tied to J3, but this ball is actually tied to the oscillator
# on the HX8k-EVN board, and Lattice still exposed it on the header for some reason.

#set_io sram_ce_n T8

set_io sram_we_n K1
set_io sram_oe_n P10
set_io sram_byte_n[1] T11
set_io sram_byte_n[0] N2

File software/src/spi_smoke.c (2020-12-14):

#include <stdint.h>

#include "delay.h"
#include "gpio.h"
#include "spi.h"
#include "tbman.h"

// Use SPI's internal loopback setting to perform quick sanity check
// for various CPOL, CPHA and baud rate

#define BUFSIZE 4
static const uint8_t tx[BUFSIZE] = {
	0,
	1,
	0xa5,
	0x5a
};

int main()
{
	uint8_t rx[BUFSIZE];

	for (int div = 1; div <= 10; div += 9)
	{
		spi_clkdiv(div);
		for (int cpol_cpha = 0; cpol_cpha < 4; ++cpol_cpha)
		{
			for (int i = 0; i < BUFSIZE; ++i)
				rx[i] = 0xff;
			spi_init(cpol_cpha >> 1, cpol_cpha & 0x1);
			*SPI_CSR |= SPI_CSR_LOOPBACK_MASK;
			spi_write_read(tx, rx, BUFSIZE);
			for (int i = 0; i < BUFSIZE; ++i)
				if (tx[i] != rx[i])
					tbman_exit(-1);
		}
		delay_us(100);
	}

	tbman_puts("All tests passed\n");
	tbman_exit(0);
}

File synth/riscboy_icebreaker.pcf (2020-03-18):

# LEDs
set_io led[0] 37 # Green on main board
set_io led[1] 11 # Red on main board
set_io led[2] 26 # Middle on snapoff (L1)
set_io led[3] 27 # Left on snapoff   (L2)
set_io led[4] 25 # Right on snapoff  (L3)
set_io led[5] 23 # Top on snapoff    (L4)
set_io led[6] 21 # Bottom on snapoff (L5)

set_io uart_tx 9
set_io uart_rx 6

# Connect SPI master to configuration flash!
set_io flash_mosi 14
set_io flash_miso 17
set_io flash_sclk 15
set_io flash_cs 16

# 12 MHz oscillator
set_io clk_osc 35

# Connect LCD signals to some random IOs
set_io lcd_cs   4  # PMOD P1A1
set_io lcd_dc   2  # PMOD P1A2
set_io lcd_sclk 47 # PMOD P1A3
set_io lcd_mosi 45 # PMOD P1A4

set_io dpad_u 20 # Snapoff top
set_io dpad_d 18 # Snapoff bottom
set_io dpad_l 10 # Main board
set_io dpad_r 19 # Snapoff middle

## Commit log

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2018-02-12 Add flash, eeprom and oscillator to schematic. Add some footprints
    Former-commit-id: 7ac2ef4c4fae7cdb8e0b55eb8623fde80e732552
    [fpgaboy.kicad_pcb, fpgaboy.sch]
2018-02-13 Add beginnnings of project directory structure. Write some HDL for busfabric.
    Former-commit-id: 16076bd35e57e0a62a98463b35fe3b4b4d608619
    [_saved_fpgaboy.sch, fpgaboy.kicad_pcb]
2018-02-18 Correct bug in opcode list parsing. Remove non-RV32IC opcodes from header.
    Former-commit-id: 397b3a49cdce0db2d0dabde518f7a9a4f9154396
    [_saved_fpgaboy.sch, fpgaboy.sch]
2018-03-02 Chasing busfabric bugs.
    Former-commit-id: c45fde4014cf416347e1dc4e27e6da2cc6d71206
    [fpgaboy.sch]
2018-03-13 Update stall policy in documentation
    Former-commit-id: 8e9322a9e14f861c8a9a32b316cf06ec0b2d843e
2018-03-16 Implement some CPU stall logic
    Former-commit-id: 65ff4065bcc8ae836de1048197d97dc027c55e5d
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2018-05-07 Update documentation: new stall policy, add section on unaligned accesses
    Former-commit-id: de82ce137ea2a1d153565191a38178257d5beab7
2018-05-07 Update stall logic, load/store logic
    Former-commit-id: ecf4deaac81a1cd741277c45331a63cc5c7abb3b
2018-05-09 Rethought fetch decision logic. Changed cpu implementation to reflect this, and fixed another bug related to spurious stalls. Core now comes out of reset, fetches some instructions and executes them.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
    Former-commit-id: cc7819abeb5bf10d363259704eb58648452955a7
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2018-05-11 Remove now-misleading worked example section; update interrupt section; explain lack of extra buffering in F for D stalls.
    Former-commit-id: a97cced567d3ffa79660675e86416bb4f5c31a77
2018-05-12 Complete overhaul of stall, load/store logic. Overhauled fetch logic to be more succinct. Added a load/store testcase, which currently does not pass (although the other two still do.
    Former-commit-id: 6faacc0f2194797f9b81fb1eb5e57c4086f5258f
2018-05-12 Tidy up readme. Update stall logic in documentation.
    Former-commit-id: 9345c8fb4530392311af7e365f30e8ec71c8b285
2018-05-13 Fixed: wire width typo in compressed decode, correct handling of unaligned jumps when target is 16 bit (need to discard MSBs of CIR on following cycle), all sw tests apart from factorial now run on c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
    Former-commit-id: 5fa5e2701975df7083f12ff92a42bbe24d2ba5f9
2018-05-27 regblock: add tieoffs to wf, ro types. Fix wiring bug in tbman.
    Former-commit-id: a33e5da3e2a29c997aa1e9a2a62a16533558c70d
2018-06-03 Move tbman. Add some peri code. Increase RAM to 0.5MiB. Add (failing) printf testcase
    Former-commit-id: b58b94ef245b7f33cc1714ffb68d7ce47f75a31e
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2018-07-05 Reset uart divider to divide-by-1
    Former-commit-id: db61425c02113660698a8f7ab963b0d1292b0b81
2018-07-06 Add condition to fetch address increment. Any kind of AHB stall will now cause a non-increment. Execution tests now pass, but system tests hang due to a loop between stall logic and bus fabric.
    Former-commit-id: f6603d3e293a3c5257fef4b05a4195669d483f2a
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2018-07-16 Create BG121 symbol for iCE40. Mostly wire this up. New kicad version has moved some files around.
    Former-commit-id: e45c33045238516c7f00d15ed939b18139a34b1a
    [fpgaboy-2018-07-15-17-57-10.sch, fpgaboy-2018-07-15-19-27-53.sch, fpgaboy.sch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]
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2018-10-31 Doc updates: major stall logic changes. Simplify bus arbitration (and add better version to improvements section). Various editing and small typo corrections.
    Former-commit-id: a094b35ea95e195f080ac726e7c799bd7782e605
    Former-commit-id: 26d32446b5afad6a293e436d90395ce55820f153
2018-11-04 Frontend finally starting to look plausible. Verilator linting found a couple of actual bugs.
    Former-commit-id: 5e287a3b6b7cabc3a783b3416cf6117db1dca6d8
    Former-commit-id: cdc8e51bf7674a9fb412be35e0f277b1e9a75e59
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2018-11-14 Update printf test. Closer than it has ever been to passing; plain string printf works fine, integer printf prints wrong result (1111 instead of 1234). Trying a string printf results in an X being wr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
    Former-commit-id: f4fd774f610bb7f2b643035c7c92c3634b2774d4
    Former-commit-id: ad5364996c9c142ae7bf1f1a77c8bb90f34fcc0b
2018-11-16 Add RV-C tests. Some don't assemble due to macro issue. All others pass.
    Former-commit-id: 65dabb2aa5bdae023b2847d2b456a891a327f4a0
    Former-commit-id: e5110c14ba197c1db75e2c64182dcd7f4cfcae68
2018-11-16 Simplified test linking. Makefile now uses labels to extract signature location and pass this onto TB so that it can dump the correct memory. Preload works properly now, since it's all just in one lo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
    Former-commit-id: 15b6c8e579901d7aa894b7a347adc3a712dd792a
    Former-commit-id: 04716fce212d9c2f2fbd7163c5fef826eeb58917
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2018-11-20 Correct GPIO muxing logic. Add behavioural unaligned access exception to processor. Add GPIO testcase, and a couple of other small tests (which didn't find any bugs).
    Former-commit-id: b137cf74ab83884e8b6978dfd31e44ca2f7ae4d9
    Former-commit-id: bd4b0f87d6867385a08ba08b4596578385867bde
    [gpio.c, gpio.h]
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2018-11-21 Add UART TX test. Fix bug in uart_mini where FIFO would be popped while clk_en low.
    Former-commit-id: 0a52260c7e90fdd683188ffc8ab717cd9c563b43
    Former-commit-id: 958d4f29ff5c9a3879fcef2207e19422982a2643
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2018-11-23 Schematic: remove FT2232H. Add debug connector. Add datasheet for a better microcontroller.
    Former-commit-id: 58bdfe8228768011608435203ff3ba7e6b664fb3 [formerly 19c51b7f48ccd36d2be7f46b66d55bb2d971f80c]
    Former-commit-id: a48f46e7092b9bd3871c3da2e30a9efbadde95d5
    Former-commit-id: 433e187ffcc20f4383464b4435a475bd7f0d864e
    [fpgaboy.sch]
2018-11-23 Update TODO after ATXMEGA boot investigation. Small schematic updates. Specify a power inductor for buck converters.
    Former-commit-id: 586be8256e79858f7111731a34fe6ef163739060 [formerly 97448644a8469dd8cefe4e310b3627ed06cd7808]
    Former-commit-id: 3bf18d91c30ecc2b96a7fe993086419bc1b087ca
    Former-commit-id: c2c9c4b26ce43b5d69dd4ad5f325b8a792337350
    [fpgaboy.sch]
2018-11-24 Create symbol for SAML22G18A, and wire up its reset + power in schematic.
    Former-commit-id: f8500376bb14c4c390649148718081ca3b6a35f1 [formerly 521bb755447660a73386e8553a6c7468d998e60e]
    Former-commit-id: 26e2e9ec17376e09dd901902dce13d3365899e41
    Former-commit-id: fe970733337899ed4e4bdd0aab35c62028279936
    [fpgaboy.sch]
2018-11-24 Wire out the microcontroller for configuring the FPGA (schematic). Tidy up the schematic and plot a new PDF.
    Former-commit-id: 553688574ba543be4953e053e0c4107ba995adef [formerly c6a2819b6c2684fe9bb14790893372c204047c33]
    Former-commit-id: a5a449c2b279eb1dab0f9965ea9f995ead69723e
    Former-commit-id: 1a751dc78d6cc8e84260da454cecb41cb910ce74
    [fpgaboy.sch]
2018-11-24 Add QFN + BGA footprints for micro + FPGA
    Former-commit-id: 7541db08c17ab0c5d6e889ec17e90f371dee7338 [formerly 9840031564159e7f4111f7c80a710bb6ae147441]
    Former-commit-id: ce7f7c8906362a7c0de501f7c490ec63a2a02b45
    Former-commit-id: 974fb59ca84e90da889c89c04514da06a414107a
    [fpgaboy.sch]
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2018-11-24 Add resistor network package. All parts have packages now.
    Former-commit-id: 0b51040ba55026eb32bf7672abd378413d5b1aa8 [formerly 3af19796ff91624e68b98778ec9330fc0c2468fa]
    Former-commit-id: 8b1512044760b471084426639aa71f0e6167fb8a
    Former-commit-id: 218fb62fe46fb1cc7a80e32c9c3561c1d71eda29
    [fpgaboy.sch]
2018-11-24 Fix some issues following schematic review: correct connection of GNDPLL. Additional pullups on FPGA cfg interface. Correct symbol for SD card, which has correct pin numbering. Pullups on UART.
    Former-commit-id: 964ad8dd6cc5873646a4e96bc6209f2bcc4b4d7d [formerly 0e3158e5005aa66432e377a7b44187b746066b41]
    Former-commit-id: 425d42906596eca8c48ae509e9d5434d9bf78729
    Former-commit-id: 0af48cad3085f2ea8b760d9a8685e12d99917022
    [fpgaboy.sch]
2018-11-24 More minor schematic revisions. Update readme to be in line with recent makefile changes.
    Former-commit-id: 8ef72371ea7fd745afb8cdcf134a653c64881dbe [formerly 7f52ef52474cb2422fedbd7386fc0c5cfbe4b50d]
    Former-commit-id: 253d02704809da7d666954123b80e3bfba1c52b2
    Former-commit-id: ee214239cc7680f8ac5aebabaebb7df9bb74e2a4
    [fpgaboy.sch]
2018-11-24 Fix ERCs on schematic (SRAM controls unconnected oops). Ready for layout!
    Former-commit-id: 202b182379a01c0fb2a119a5850cd0e08c7dbe72 [formerly 86b19f6ba7559f60dbdfce0b263ec2e63d73cd75]
    Former-commit-id: f6afff385088ec8977dd953ecbc976619d289004
    Former-commit-id: e7fd20351cb775cefb8e5f5e2094818bde919f17
    [fpgaboy.sch]
2018-11-24 PCB: import netlist, set up board perimeter, planes, DRC.
    Former-commit-id: db39540da853fd6e9b11bb7ebc257c05f2c57114 [formerly a41c5352efe3ec2d7d83614421b6e63e598ce97c]
    Former-commit-id: a1b8f921a68008d3870cc9ae1145b4fb55359cd4
    Former-commit-id: cf0d552804170fee1a25c4142faf7534d85e2960
    [fpgaboy.kicad_pcb]
2018-11-24 Start placing components. Fix references to kicad4 footprints. Alter BGA footprint so that vias can be placed between pads.
    Former-commit-id: bd528e47238e1e5486ab4242507cff2d8ebbe877 [formerly e25b043cde048c10d5d4d75b9e60daf800c100f4]
    Former-commit-id: 11b4f6d371cc355af72a2cc654ce37b7b2cdccaa
    Former-commit-id: 1230468cd22565a20545bb1cbead323269b41e59
    [fpgaboy.kicad_pcb, fpgaboy.sch]
2018-11-24 Part placement for switchmode supply. Remove silkscreen on pad in BGA footprint.
    Former-commit-id: 3a3be8eab7c0b08d64aa998ecce77922e7b7b81f [formerly 3ca67d1ac3340a2e648bb178ad1a65c83304dd27]
    Former-commit-id: 5b3b48003e4daa74b0e82a3c52147ad53126a4d0
    Former-commit-id: 2e4ec40682e333392ab8fb2fd83839f39101e2cb
    [fpgaboy.kicad_pcb]
2018-11-24 First pass of placing all components.
    Former-commit-id: 935330e139bbc688dd3075af15c022303e23c6e1 [formerly f9cef177abd4ecc2c663cb08782e3e3e737b028e]
    Former-commit-id: 80bf02931e0e868b70c2aba9824d08be8d3d2d28
    Former-commit-id: 687b3f498758089015909bee82d7bb9f30404761
    [fpgaboy.kicad_pcb, fpgaboy.sch]
2018-11-25 kicad crashed and deleted all traces from the board. wtf? 3 hours' progress lost. Only some vias under the BGA are left. Should commit more often
    Former-commit-id: 02cf3a33ecf67da1eb78e7c40696abeefd4b2115 [formerly 0f2dd3bf6e83a96bdb5da01df3e7540a826b344c]
    Former-commit-id: e1ce6b3b8ad0493b9ac25c1ada88c924ade3c314
    Former-commit-id: 9ae19f32a7b680d308611b0b1fcd16b73eed0f11
    [fpgaboy.kicad_pcb]
2018-11-25 Add extra zones under BGA to tighten up plane clearance (so that planes can go between diagonally-spaced vias).
    Former-commit-id: acc1dc0282ce864e70f9f44a6a4090a0b3997665 [formerly ad3864c5784006ca55ec16fa14b2cfcdcb240494]
    Former-commit-id: f4db6870202bdf4893f368656aa2d5cde32939b2
    Former-commit-id: 2560b549215e1b4d3805b382c28499008ce62867
    [fpgaboy.kicad_pcb]
2018-11-25 Start escaping from BGA
    Former-commit-id: 9b2ec634a9d14f5a00aa033b8db1d85e0c78b99c [formerly 7e16a053d58713ca8d71d0c2a84a88b1021e3366]
    Former-commit-id: 4f433b0f30c8e87b2832e49c298eff8525979f51
    Former-commit-id: 97705cad689f829e66c5841578c966588ae79a7e
    [fpgaboy.kicad_pcb]
2018-11-25 Continue BGA escape. Pin-swap LCD and uSD card so that the traces don't have to cross.
    Former-commit-id: f8ac038b637c7257d92a3d2f030f50e78c9c9bc2 [formerly 6bcc831231e3fdf82be743b82d14a98c5b81e0ac]
    Former-commit-id: 605b2bd4fd829a74481d758a2aba6bf016992be6
    Former-commit-id: 63a570fdaa14407f687558ae361da6e3eddfbbe5
    [fpgaboy.kicad_pcb, fpgaboy.sch]
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2018-11-25 BGA route out 99%. Use a gbin for an SRAM pin to avoid nasty route-out.
    Former-commit-id: 07f92fcfe0b8196dbaa0211e318f2cb0094c4f09 [formerly 87ade9239a6d7c42a9d86e2b403b5dd729dbe203]
    Former-commit-id: 3d668f6e0e5d229a5cfefa9fffbb2161422c9dee
    Former-commit-id: 99b8390e32f2fc2be4ea2818cc2b91bb5d9c6d22
    [fpgaboy.kicad_pcb, fpgaboy.sch]
2018-11-25 Pin-swapping + routing the SRAM: 50%
    Former-commit-id: 2b577cf7b52f24baabab8caba00ed91606b61012 [formerly dccfe95725d7621aa8f631ef6b86a4224c43d36a]
    Former-commit-id: 66db710dd59c402621ba8271397dc92d027909e4
    Former-commit-id: c62c4198c05e169013effc5fdc660d776587b68b
    [fpgaboy.sch]
2018-11-25 FPGA -> SRAM connected, still needs some tidying
    Former-commit-id: 485c30751ef063f7c9d3ffd6dee203909d14fc5b [formerly 03235fb12b113a93dc78ef023ce4bd03212aa64c]
    Former-commit-id: c6d7b3678d387a07fbd4eb6c1dc3e0ac1262a6cf
    Former-commit-id: 99bfaaad5736dd77a389fe19bcf24d957bc4f62f
    [fpgaboy.kicad_pcb, fpgaboy.sch]
2018-11-25 Kicad is a real piece of crap now. Froze while dragging trace and overwrote save, yet again (this was reason for previous commit). Luckily there was an autosave backup this time, which has 80% of wha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
    Former-commit-id: 47bd0b92407769516be17e2b7d6febcfbb496213 [formerly daeae14b88276c1abb7f3686e391b5f2632423f6]
    Former-commit-id: 6f7014c25425ff30e282d6ed453df39a12adce99
    Former-commit-id: 7b79513a4ef39134b27ede1bd435707a3ad2f3dd
    [fpgaboy.kicad_pcb]
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2018-11-25 Tidy up SD card routing. Fix some power routing.
    Former-commit-id: bc5e31278399f3c9f7cfb366e1fad21319d651bc [formerly 7a91a4b9c5cb68b516474c924bab2b3ca939cb32]
    Former-commit-id: bddaac2d5eda61544dc59f664f628ee1b133aec9
    Former-commit-id: 5cc6b4c78ef63d761f337436ff36185104890d02
    [fpgaboy.kicad_pcb]
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2018-11-26 Rename to riscboy, avoid confusion with FPGA gameboy emulation projects
    Former-commit-id: fb96d0d9b41329deac47c9db158a6f7d748e7161 [formerly ffa569024155a69818c60de720ddf209a1e6034b]
    Former-commit-id: 5a457fea539126d4458a57776f459b80fe8f52ae
    Former-commit-id: 0f4b3a040489864a3015ee07982b1bdd8d8035f7
    [fpgaboy.kicad_pcb]
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2018-11-26 Tidy up potential ground antenna on backside plane (stitch + shorten)
    [fpgaboy.kicad_pcb]
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2018-11-27 Correct orientation of LCD connector (oops), and add rudimentary audio to board.
    [fpgaboy.kicad_pcb, fpgaboy.sch]
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2018-11-27 Add rudimentary FPGA top level using new constraints file. Build currently fails due to apparent yosys/arachne bug wrt tristate buffers.
    [chip.pcf]
2018-11-28 Add workaround for Yosys tristate inference issue (wrapper to instantiate SB_IO cell directly)
    [chip.pcf]
2018-11-28 Decode: zero out specifier for unused register to avoid spurious load-use stalls.
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2019-01-19 Board: correct mirrored oscillator footprint :(
    [fpgaboy.kicad_pcb]
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2019-01-20 Add blinky .c file, and wire LED + UART correctly in FPGA top-level
2019-01-31 Remove extra reset from PC which caused multiple driver issue, ultimately causing PC to be tied to 0. WHOOPS
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2019-02-19 First pass at CIR-locking functionality to preserve jump/predicted branch side effects if D jump is asserted whilst D is stalled. Tests pass if I disable it :)
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2019-02-20 Add traffic generator to execution testbench to stress the stall logic a little.
2019-02-23 Right-justify buses in pin constraint file, due to bug in nextpnr
2019-02-24 Board changes (starting rev B): swap to 'hx4k' (actually an hx8k, but in TQ144, which is easier to solder), and add soft-latching power switch
    [fpgaboy.sch]
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2019-03-21 Add proper millisecond/microsecond delay functions. Start writing basic LCD init code. Have potentially found a processor bug; need to simulate or perhaps add RV formal.
2019-03-23 Fix historic bug in ahb_sync_sram: fails to ignore address phases with hready low. Badness ensues when this is a write, due to the subsequent wait state it inserts. For some dumbass reason this memor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
2019-03-23 oops, forgot to commit fixes to SRAM wiring in execution testbench. Also update PCF to constrain PWM pin.
2019-03-25 Add a two-stage FPGA reset generator to cope with the iCE40 block RAM bug
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2019-03-29 Add correctly-phased RX side to SPI master, and simplify some CPHA logic.
    [spi_smoke.c]
2019-03-29 SPI: fix read_en bit. Add internal loopback. Use this in sw test to check we can loopback data with all CPOL/CPHA, and different baud rates. Add sw test to test list.
    [spi_smoke.c]
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2019-03-30 Fix a bug where UART RX falls through idle (I never tested it...) and add a UART loopback test to make sure it stays fixed. Also make UART RX more robust: half a bit time of slack between stop bit sa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
    [uart_loopback.c]
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2019-04-01 Add simple glitch filter to UART RX, and aggressive (long back-to-back) UART loopback test. Added these while debugging the SPI programming shell... turned out to be something completely different
    [uart_loopback.c]
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2019-04-03 First pass at a proper serial bootloader. Fairly efficient buffer-oriented IO, very basic error checking, and it's possible to recover from error state.
    [riscboy_bootloader.c]
2019-04-04 Update uartprog for new bootloader; much faster and more reliable, but still nowhere near fast enough. Add activity light to bootloader, and fix write address bug.
    [riscboy_bootloader.c]
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2019-04-04 SRAM breakout: add gerbers + PDF schematic. Fix directory structure.
    [sram_dev_board-B.Cu.gbr, sram_dev_board-B.Mask.gbr, sram_dev_board-B.SilkS.gbr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]
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2019-04-07 Sync SRAM: add write buffer for 0-wait-state operation. In exec tb, hold processor in reset for a couple cycles at end of test to allow write buffer to retire before reading out memory.
2019-04-11 Add AHB to half-width async SRAM adapter. Uses DDR output for WE timing. No double pumped reads (wait for real hardware; timing will be tight.)
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2019-04-13 listfiles: option for paths relative to dir other than PWD. Due to ISIM bug: file paths are relative to PWD when fuse is run, but include paths are relative to project file... Also add include paths 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
2019-04-14 Add wiring and PCF for SRAM on HX8k board (doesn't synth due to pin conflict with oscillator)
    [riscboy_hx8kevn.pcf]
2019-04-14 Fix LED on hx8k_evn. Change hx8k pcf to reflect DQ2 fix. Fix uartprog to take highest-numbered serial port by default (seems to be decent heuristic)
    [riscboy_hx8kevn.pcf]
2019-04-14 Add memory test to bootloader. SRAM breakout fails :(
    [riscboy_bootloader.c]
2019-04-17 On iCE40 it's impossible to have a clke'd and a non-clke'd SB_IO on the same tile. Due to a nextpnr bug this is not reported, and it will just clke both of them, which broke the SRAM controller. This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
    [riscboy_hx8kevn.pcf]
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2019-04-20 Ramp up baud rate in second part of UART loopback, simulation time was far too long. Handle baud-mismatch garbage from behav uart rx in the test script.
    [uart_loopback.c]
2019-04-23 Hazard5 formal: connect up D PC (oops) and, in monitor, clear M instruction valid when X is stalled but M is not.
2019-04-24 RVFI stuff: fix typo causing mem masks to be tied off. Supply 0 for rd_wdata when rd is x0, as riscv-formal seems to expect this. Use rvformal_rand_reg for hrdata, hready in wrapper, to avoid warning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
2019-04-24 Tighten up decoding of reserved/invalid instructions. Also make D stage handle invalid instructions in a safer way; be certain that they cannot have any side effects.
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2019-04-27 For unaligned load/store, stomp data phase as well as address phase, to avoid spurious stalls (was probably safe before, but tidy up a loose end)
2019-04-28 CPU: do not rearbitrate bus requests if an active request stalled on the previous cycle.
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2019-07-11 Fix typo in UART loopback test, which caused it to fail when compiler version changed, due to timing difference
    [uart_loopback.c]
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2019-07-20 Bugs related to traps/IRQs: bubbling the trapped instruction on the way from X to M, interrupt decode and masking, making sure register specifiers are clear for the exception-generating instructions.
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2019-09-14 Get lcd_mandelbrot working with new display hardware. Fix bootloader to jump over 2nd stage vector table
    [lcd_mandelbrot.c, riscboy_bootloader.c, riscboy_hx8kevn.pcf]
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2019-12-19 Fix risky second stage of FPGA reset generator
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2019-12-19 Appease the ILI9341 gods with a MADCTL before the sw reset (otherwise display requires two inits to properly initialise after a hard LCD power cycle)
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2020-01-08 Replace SRAM0 with a large internal memory for ECP5 builds. Allow forcing of SRAM0 size in bootloader. Temporarily hook up LCD, SPI, UART to ECP5EVN expansion header. Build bootloader instead of blin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
    [riscboy_bootloader.c]
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2020-02-28 Don't commit operands to muliplier when X is in RAW stall against M
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2020-03-01 Mask CSR write and trap exit on stall/flush. Kill muldiv on mispredict or trap entry.
2020-03-01 hazard5_decode: fix case where flush is asserted while X is stalled.
2020-03-02 Fix case where exception exit and entry are requested simultaneously. Fix interaction between exception exit and pipe stall/flush.
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2020-03-02 Fix interaction between late-jump flush and X divider stall when the jump request is stalled by bus, causing X PC to not update
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2020-03-18 Add parameters for cutdown FPGA builds, and encode their values in a tbman register. In bootloader, skip flash boot if SPI not present.
    [riscboy_bootloader.c]
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2020-08-23 Fix up some tests broken during manic lockdown work
    [uart_loopback.c]
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2020-12-03 Fix SPI DISPTYPE, and add generic code for using display on SPI/DVI hardware
    [display.h, lcd_mandelbrot.c, ppu_lcd_smoke.c]
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2020-12-03 Couple of minor fixes in scripts
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2020-12-04 Replace YNE branch condition with YGE, and make cursed VGA 30Hz mode the default for DVI dispctrl
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2020-12-08 Fix LCD wiring on icebreaker build
2020-12-12 Bump libfpga to get UART RX sync fix
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2020-12-14 Fix couple of wiring issues that were making ISIM hit internal asserts
2020-12-14 Fix broken SPI test and disable GPIO test
    [spi_smoke.c]
2020-12-27 Add bus stalls to PPU tb
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2021-01-09 Playing with HDMI on icebreaker. Frequent placement failures.
    [riscboy_icebreaker.pcf]
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2021-02-15 Add 24pin LCD flex probe board for Chinaboy LCD, and MCU test for LCD init sequence
    [24pin_flex_interposer-B_Cu.gbr, 24pin_flex_interposer-B_Mask.gbr, 24pin_flex_interposer-B_Paste.gbr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]
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2021-02-22 Add -s argument to icepack, so a flash power down command is not issued after the bitstream is loaded
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2021-02-22 Fix a couple of pin assignment issues found during review. Add 3V3A testpoint.
    [riscboy.kicad_sch]
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2021-03-13 Add missing start/select buttons, and move LCD reset control to uC to make room for FPGA IOs.
    [riscboy.kicad_sch]
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2023-06-14 Start separating IOs from memory controller core, almost there but still something wrong with the byte strobes
    [riscboy_bootloader.c]
2023-06-16 Oops, revert SRAM pipe stage accidentally enabled in SRAM PHY -- not ready for that yet
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2023-06-24 Bump hazard5 for minor improvement to muldiv_seq stall output timing
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2023-07-01 Bump hazard5: move store data bypass to end of stage 3, to fix tight HWDATA path
